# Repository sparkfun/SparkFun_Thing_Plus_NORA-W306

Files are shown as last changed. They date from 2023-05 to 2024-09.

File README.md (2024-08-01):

SparkFun Thing Plus - NORA-W306
========================================

SparkFun Thing Plus - NORA-W306 (https://www.sparkfun.com/products/21637)

[*SparkFun Thing Plus - NORA-W306 (WRL-21637)*](https://www.sparkfun.com/products/21637)

The SparkFun Thing Plus - NORA-W306 is a Feather form-factor development board equipped with the u-blox NORA-W306 module. The module contains a Realtek RTL8720DF, which has an integrated single-chip low-power dual-band (2.4GHz and 5GHz) Wireless LAN (WLAN) and Bluetooth&reg; Low Energy (BLE 5.3) communication microcontroller. It also consists of a dual processor core: Arm Cortex-M33 and Cortex-M23. To complement the module's low-power options, we've optimized components and added the ability to depower all subsystems to conserve as much power as possible for remote battery-powered applications.

Repository Contents
-------------------

* **.github/workflows** - YAML files used for GitHub Actions and GitHub Pages/mkdocs
* **/Hardware** - Eagle design files (.brd, .sch)
  * **/Production** - Production panel files (.brd)
* **/docs** - Online documentation files
  * **/assets** - Folder containing all the file assets used for product documentation
    * **/board_files** - Copy of design files used for product documentation
    * **/component_documentation** - Datasheets and manuals for hardware components
    * **/img** - Images for product documentation
  * **/github** - Files stating how to contribute and filing issues used for product documentation
  * **/javascript** - Folder containing custom javascript used for product documentation
  * **/stylesheet** - Folder containing CSS files used for product documentation
* **/overrides** - Customization files used for product documentation
  * **/.icons** - Icons used for GitHub used for product documentation
  * **./partials** - Used for product documentation

Documentation
--------------

* **[Installing an Arduino Library Guide](https://learn.sparkfun.com/tutorials/installing-an-arduino-library)** - Basic information on how to install an Arduino library.
* **Arduino Libraries**
    * **[MAX17048 LiPo Fuel Gauge](https://github.com/sparkfun/SparkFun_MAX1704x_Fuel_Gauge_Arduino_Library)**
    * **[SdFat](https://github.com/greiman/SdFat)**
    * **[Qwiic OLED Display](https://github.com/sparkfun/SparkFun_Qwiic_OLED_Arduino_Library)**
* **[Graphical Datasheet](https://github.com/sparkfun/Graphical_Datasheets/blob/main/Datasheets/NORA-W306/SparkFun_Thing_Plus_NORA-W306_u-blox.pdf)**
* **[Fritzing Part](https://github.com/sparkfun/Fritzing_Parts/blob/main/products/21637_sfe_thing_plus_u-blox_NORA-W306_development_board_lipo_charger_fuel_gauge_qwiic_WS2812.fzpz)**
* **[Realtek: Arduino Board Support Files](https://github.com/ambiot/ambd_arduino)**
* **[Hookup Guide](https://docs.sparkfun.com/SparkFun_Thing_Plus_NORA-W306)** - Basic hookup guide for the SparkFun Thing Plus NORA-W306.

Product Versions
----------------

* [WRL-21637](https://www.sparkfun.com/products/21637) - v1.0

Version History
---------------
* v1.0 - Initial Release

License Information
-------------------

This product is _**open source**_!

Please review the LICENSE.md file for license information.

If you have any questions or concerns on licensing, please contact technical support on our [SparkFun forums](https://forum.sparkfun.com/viewforum.php?f=152).

Distributed as-is; no warranty is given.

- Your friends at SparkFun.

_<COLLABORATION CREDIT>_

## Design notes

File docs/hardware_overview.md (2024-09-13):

In this section, we will highlight the hardware and pins that are broken out on the SparkFun Thing Plus NORA-W306. For more information, check out our [Resources and Going Further](../resources/) for the u-blox NORA-W306 module or Realtek RTL8720DF that is contained within the module.

<div style="text-align: center;">
  <table>
    <tr style="vertical-align:middle;">
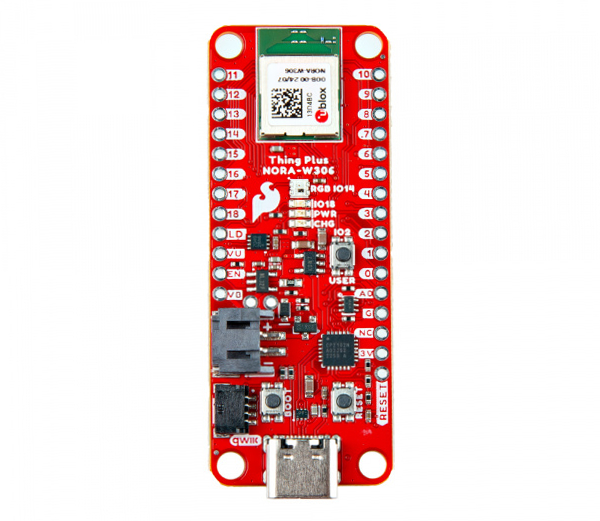
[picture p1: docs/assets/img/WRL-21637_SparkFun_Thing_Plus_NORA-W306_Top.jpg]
     <td style="text-align: center; vertical-align: middle; border: solid 1px #cccccc;"></td>
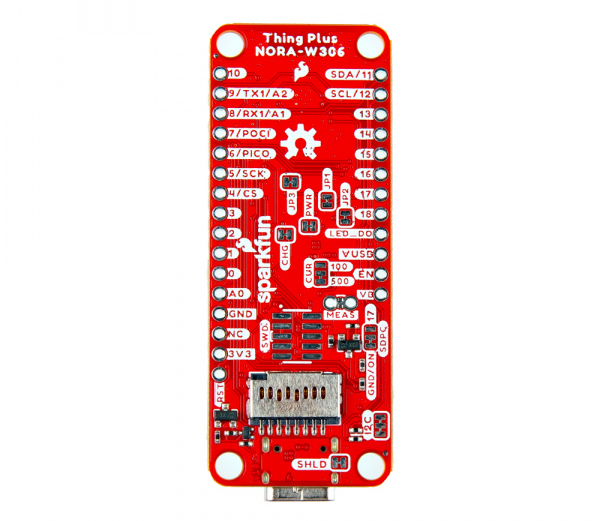
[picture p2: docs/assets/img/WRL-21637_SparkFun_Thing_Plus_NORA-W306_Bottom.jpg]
Bottom View
     <td style="text-align: center; vertical-align: middle; border: solid 1px #cccccc;"></td>
    </tr>
    <tr style="vertical-align:middle;">
     <td style="text-align: center; vertical-align: middle; border: solid 1px #cccccc;"><i>Top View</i></td>
     <td style="text-align: center; vertical-align: middle; border: solid 1px #cccccc;"><i>Bottom View</i></td>
    </tr>
  </table>
</div>

### Power

There are a variety of power and power-related nets broken out to connectors and through hole pads. Power is regulated down to 3.3V for the NORA-W306 so the [logic level](https://learn.sparkfun.com/tutorials/logic-levels/all) is 3.3V. There are Schottky diode and transistors to safely select voltage from the USB or LiPo battery. This avoids any conflicting voltages between the two sources.

* **VU** or **VUSB** &mdash; The _V_BUS_ net is connected to the USB Type C connector and the VU/VUSB PTH. You can use 5V from a USB port by connecting to the USB Type C connector or connecting power to the VBUS PTH. Make sure that power you provide to this pin does not exceed 6 volts. Power is regulated down with the XC6222 3.3V/700mA voltage regulator. The USB Type C connector is also used to upload code to your processor, send serial data to a terminal window, or charging the LiPo battery. Of course for portable power, you could connect a USB battery as an alternative to using a LiPo battery.
* **VB** &mdash;  The _V_BATT_ net is connected to the 2-pin JST style connector, VB PTH, and the NORA-W306's MEAS pin. For portable applications, you can connect a nominal 3.7V single cell, LiPo battery to the 2-pin JST style connector. This pin is also connected to the MCP73831 charge IC to safely charge the LiPo battery to its maximum voltage of about 4.2V. We recommend connecting only LiPo batteries to the VBAT net to power the board. Of course, you can power a separate device through the VBAT PTH pin. Power is regulated down with the XC6222 3.3V/700mA voltage regulator.
* **3V** or **3V3** &mdash; The 3.3V net is labeled as 3V or 3V3. You can apply power to the board if you have a regulated voltage of 3.3V. Otherwise, you could power a separate device through the 3V3 PTH pin. This is also connected to the Qwiic connector's 3.3V pin to power Qwiic enabled devices.
* **EN** &mdash; The 3.3V voltage regulator's EN pin is labeled as EN. Pulling this pin low will disable the 3.3V voltage regulator.
* **G** or **GND** &mdash; Of course, is the common, ground voltage (0V reference) for the system.

<div style="text-align: center;">
  <table>
    <tr style="vertical-align:middle;">
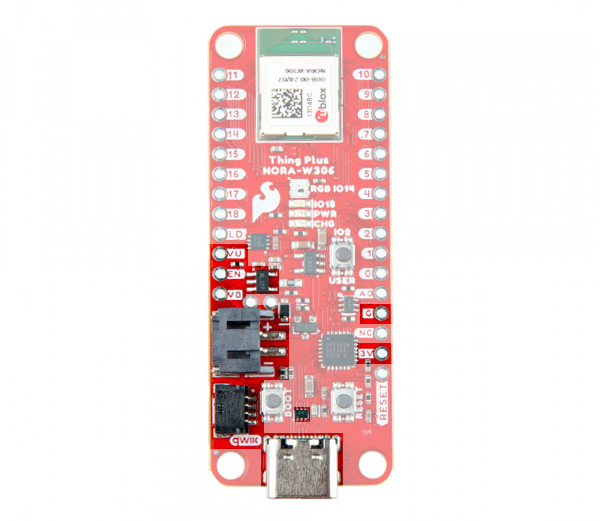
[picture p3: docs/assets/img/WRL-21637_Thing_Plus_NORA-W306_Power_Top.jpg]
     <td style="text-align: center; vertical-align: middle; border: solid 1px #cccccc;"></td>
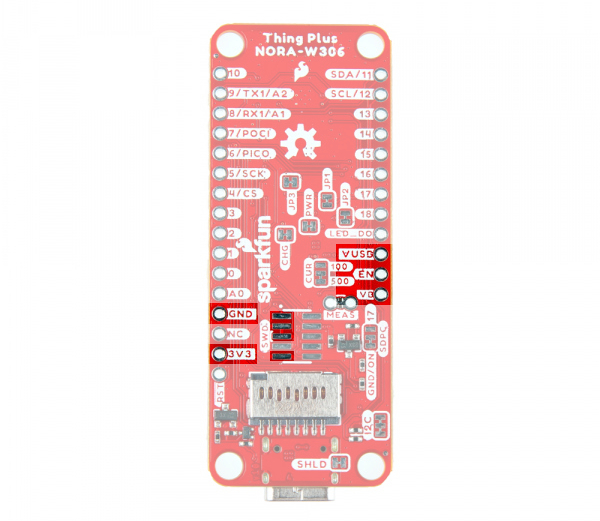
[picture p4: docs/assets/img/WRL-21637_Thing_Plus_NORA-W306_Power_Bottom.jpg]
Bottom View
     <td style="text-align: center; vertical-align: middle; border: solid 1px #cccccc;"></td>
    </tr>
    <tr style="vertical-align:middle;">
     <td style="text-align: center; vertical-align: middle; border: solid 1px #cccccc;" colspan="2"><i>Power, Ground, and Connectors Highlighted<br />(Top & Bottom View)</i></td>
    </tr>
  </table>
</div>

!!! note
    You will notice the pads of the SWD pins are also highlighted! 3.3V and ground are also connected to these pads. Users can easily access these pins using a SWD header and cable. Of course, you could also solder wire to those pads if you needed another way to connect to the traces.

!!! tip
    To complement the module's low-power options, we've optimized components and added the ability to depower all subsystems to conserve as much power as possible for remote battery-powered applications. Without a battery attached or charging, and cutting the power to WS2812 (i.e. jumper JP3); the current draw was as low as 14&micro;A in low power mode! Amazing! Under normal conditions, we measured the current draw as low as 30mA.

    Let's compare the Thing Plus ESP32 (USB-C) against the Thing Plus NORA-W306. The power LED jumper was cut on the Thing Plus ESP32. A microSD card was inserted in the microSD card socket (which does not have a way to turn off power through a GPIO) and the board was powered via a single cell LiPo battery. The current draw was 884&micro;A in deep sleep mode while it was 40mA when awake.

    For the Thing Plus NORA-W306, we cut the power LED and WS28112 LED jumpers. The SDPC (microSD Power Control) jumper was modified so power to the microSD card can be controlled through GPIO 17. A microSD card was inserted in the microSD card socket. With the MEAS jumper cut, a multimeter (set to measure current) was connected to monitor the current draw. Power was also provided via a single cell LiPo battery. The current draw was 115&micro;A in deep sleep mode while it was 21mA when awake.

    For more information, check out the demo video below with current draw for the board in low power mode!

    <div style="text-align: center;">
    <iframe width="560" height="315" src="https://www.youtube.com/embed/ElCYbEnyYH4?si=EVBnWnvqqZ6KBMxX" title="YouTube video player" frameborder="0" allow="accelerometer; autoplay; clipboard-write; encrypted-media; gyroscope; picture-in-picture; web-share" referrerpolicy="strict-origin-when-cross-origin" allowfullscreen></iframe>
    </div>

    <!--
    <div style="text-align: center;">
      <table>
        <tr style="vertical-align:middle;">
         <td style="text-align: center; vertical-align: middle; border: solid 1px #cccccc;">Component</td>
         <td style="text-align: center; vertical-align: middle; border: solid 1px #cccccc;">Power Usage Current [ &micro;A ]</td>
        </tr>
        <tr style="vertical-align:middle;">
         <td style="text-align: center; vertical-align: middle; border: solid 1px #cccccc;">CP2102</td>
         <td style="text-align: center; vertical-align: middle; border: solid 1px #cccccc;">199</td>
        </tr>
        <tr style="vertical-align:middle;">
         <td style="text-align: center; vertical-align: middle; border: solid 1px #cccccc;">microSD</td>
         <td style="text-align: center; vertical-align: middle; border: solid 1px #cccccc;">179</td>
        </tr>
        <tr style="vertical-align:middle;">
         <td style="text-align: center; vertical-align: middle; border: solid 1px #cccccc;">3.3V VREG<br />(Powered with 4V at VBATT)</td>
         <td style="text-align: center; vertical-align: middle; border: solid 1px #cccccc;">93</td>
        </tr>
        <tr style="vertical-align:middle;">
         <td style="text-align: center; vertical-align: middle; border: solid 1px #cccccc;">NORA-W306<br />(Powered with 3.3V at 3V3 net)</td>
         <td style="text-align: center; vertical-align: middle; border: solid 1px #cccccc;">10 to 11</td>
        </tr>
      </table>
    </div>
    -->

### LiPo Charge Circuit

The board includes the MCP73831 LiPo charger IC (the little black IC with 5 pins highlighted) to safely charge a single cell, LiPo battery. In this case, the charge rate is set to a default rate of **500mA**. Cutting the trace on the back while adding a solder jumper between the middle pad and the pad labeled as _100mA_ will set the charge rate to 100mA. The on-board LED (not highlighted) labeled as CHG can be used to get an indication of the **charge status** of your battery.

<div style="text-align: center;">
  <table>
    <tr style="vertical-align:middle;">
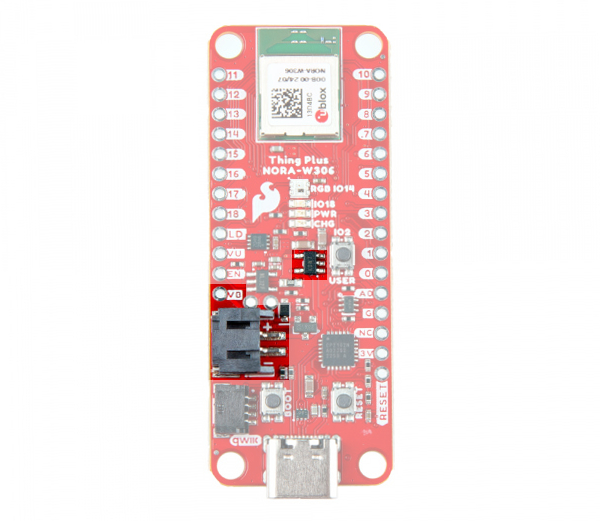
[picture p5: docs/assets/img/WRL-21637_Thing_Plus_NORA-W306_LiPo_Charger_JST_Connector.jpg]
Charge Circuit (Top View)
     <td style="text-align: center; vertical-align: middle; border: solid 1px #cccccc;"></td>
    </tr>
    <tr style="vertical-align:middle;">
     <td style="text-align: center; vertical-align: middle; border: solid 1px #cccccc;"><i>2-pin JST Style Connector, LiPo Charger IC, and VBATT PTH Highlighted<br />(Top View)</i></td>
    </tr>
  </table>
</div>

!!! note
    For more information on proper handling of LiPo batteries, check out the tutorial on [Single Cell LiPo Battery Care](https://learn.sparkfun.com/tutorials/single-cell-lipo-battery-care).

    <div class="grid cards" style="width:500px; margin: 0 auto;" markdown>

    -   <a href="https://learn.sparkfun.com/tutorials/single-cell-lipo-battery-care">
          <figure markdown>
            Single Cell LiPo Battery Care
          </figure>
        </a>

        ---

        <a href="https://learn.sparkfun.com/tutorials/single-cell-lipo-battery-care">
          <b>Single Cell LiPo Battery Care</b>
        </a>
    <!-- ----------WHITE SPACE BETWEEN GRID CARDS---------- -->
    </div>

### GPIO

The SparkFun Thing Plus - NORA-W306 breaks out the GPIO pins to plated through hole pads on the edge of the board using the Thing Plus/Feather Form Factor. Each of the pins on the edge of the board are tired to various components on the board. Check below for more information on each connection!

<div style="text-align: center;">
  <table>
    <tr style="vertical-align:middle;">
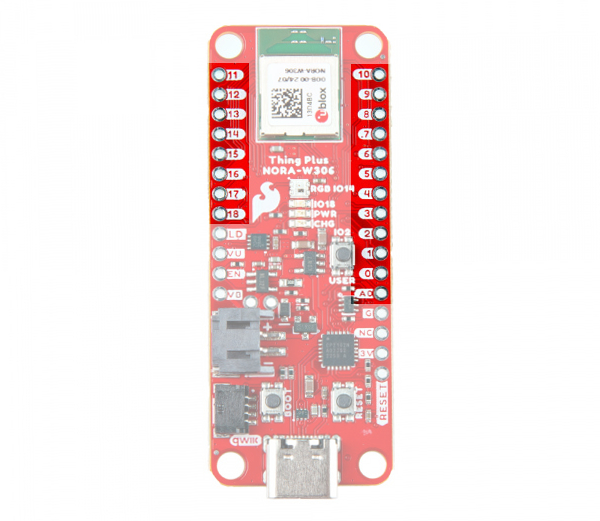
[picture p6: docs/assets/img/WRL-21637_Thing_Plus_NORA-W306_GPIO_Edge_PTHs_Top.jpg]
GPIO Pins Highlighted
     <td style="text-align: center; vertical-align: middle; border: solid 1px #cccccc;"></td>
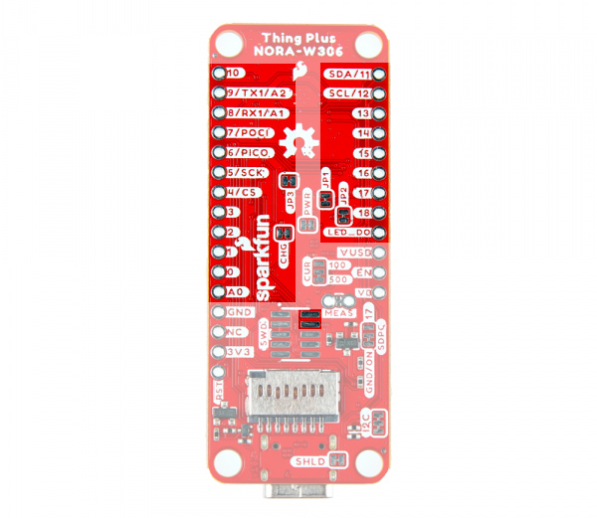
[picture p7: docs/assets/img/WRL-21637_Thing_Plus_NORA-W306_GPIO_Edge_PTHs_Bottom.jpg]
GPIO Pins Highlighted
     <td style="text-align: center; vertical-align: middle; border: solid 1px #cccccc;"></td>
    </tr>
    <tr style="vertical-align:middle;">
     <td style="text-align: center; vertical-align: middle; border: solid 1px #cccccc;" colspan="2"><i>GPIO Pins Highlighted<br />(Top & Bottom View)</i></td>
  </table>
</div>

Note that the pin label might have additional functionality that may not be apparent from the silkscreen. Below is a graphical datasheet of the SparkFun Thing Plus - NORA-W306 that highlights the additional functionality.

<div style="text-align: center;">
  <table>
    <tr style="vertical-align:middle;">
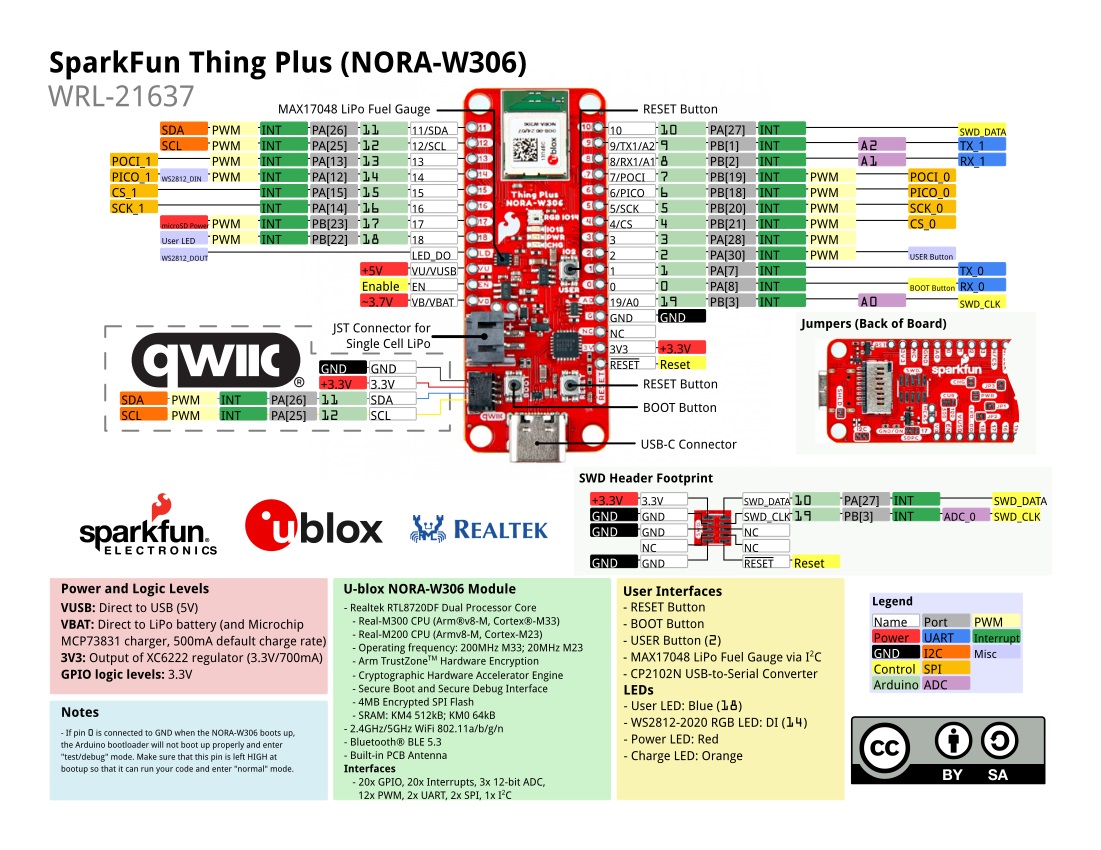
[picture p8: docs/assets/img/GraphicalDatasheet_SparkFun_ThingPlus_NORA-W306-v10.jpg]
Graphical Datasheet
     <td style="text-align: center; vertical-align: middle; border: solid 1px #cccccc;"></td>
    </tr>
    <tr style="vertical-align:middle;">
     <td style="text-align: center; vertical-align: middle; border: solid 1px #cccccc;"><i>Graphical Datasheet</i></td>
  </table>
</div>

!!! note
    While the u-blox integration manual may have pins highlighted to show additional functionality, there are some that are not supported in the Realtek's Arduino core. Some of these features that are not supported in the Arduino core include SDIO, I2S, IR, and RTC.

### SWD

For advanced users, the SWD pins are broken out on the 2x5 header on the back of the board. Note that this is not populated so you will need to solder a [compatible header, 2x5 SWD cable, and compatible JTAG programmer](https://www.sparkfun.com/categories/tags/jtag) to connect. These pins are also connected to the edge of the board.

<div style="text-align: center;">
  <table>
    <tr style="vertical-align:middle;">
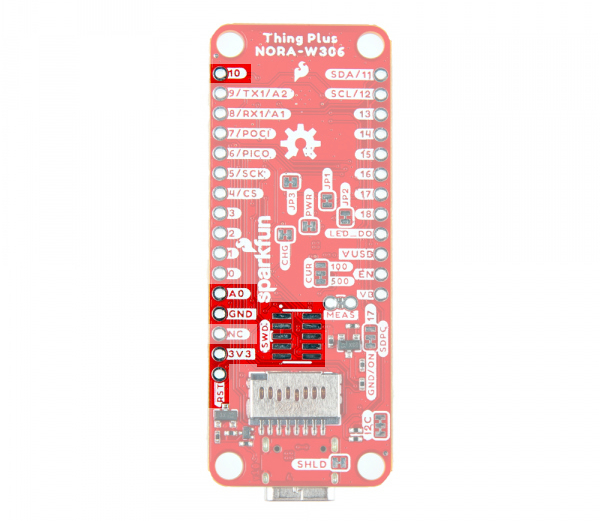
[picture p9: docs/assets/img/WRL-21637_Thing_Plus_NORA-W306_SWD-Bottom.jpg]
SWD Pins Highlighted
     <td style="text-align: center; vertical-align: middle; border: solid 1px #cccccc;"></td>
    </tr>
    <tr style="vertical-align:middle;">
     <td style="text-align: center; vertical-align: middle; border: solid 1px #cccccc;"><i>SWD Pins Highlighted</i></td>
  </table>
</div>

!!! note
    Pin `10` is tied to the SWD Data pad and `A0` is tied to SWD CLK pad on the back of the board.

### Reset and Boot Buttons

Each board includes a RESET and BOOT button. There is an additional reset PTH next to the reset button. Hit the reset button to restart the NORA-W306. To manually place the NORA-W306 into boot mode, hold down the BOOT button while pressing the RESET button momentarily and then release the BOOT button.

<div style="text-align: center;">
  <table>
    <tr style="vertical-align:middle;">
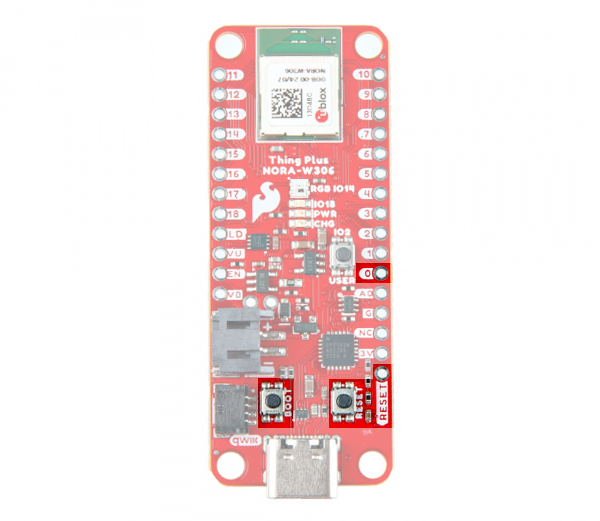
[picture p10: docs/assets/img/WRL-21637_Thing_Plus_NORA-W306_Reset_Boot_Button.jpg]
     <td style="text-align: center; vertical-align: middle; border: solid 1px #cccccc;"></td>
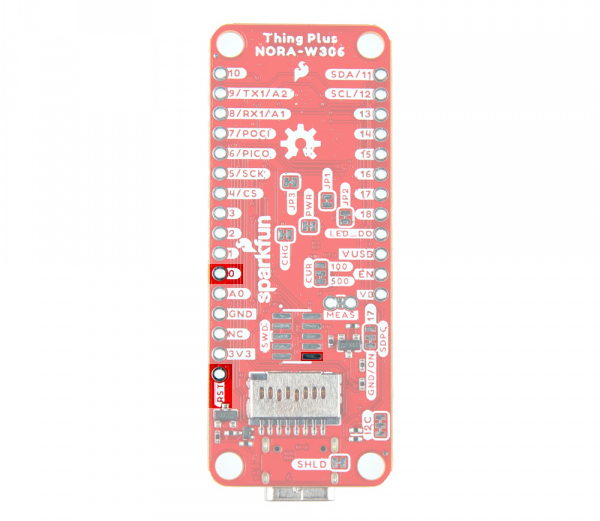
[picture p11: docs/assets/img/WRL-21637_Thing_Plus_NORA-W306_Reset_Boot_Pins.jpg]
     <td style="text-align: center; vertical-align: middle; border: solid 1px #cccccc;"></td>
    </tr>
    <tr style="vertical-align:middle;">
     <td style="text-align: center; vertical-align: middle; border: solid 1px #cccccc;" colspan="2"><i>Reset and Boot Pins and Buttons Highlighted<br />(Top & Bottom View)</i></td>
    </tr>
  </table>
</div>

!!! note
    The BOOT button is also connected to pin 0 (TX). The datasheet refers to this pin as the CHIP_EN.

!!! note
    You will notice a pad of the SWD is also highlighted. The reset pin is connected to this pad. Users can easily access these pins using a SWD header and cable. Of course, you could also solder wire to those pads if you needed another way to connect to the traces.

### User Button

The board also includes a user button that is connected pin `2`.

<div style="text-align: center;">
  <table>
    <tr style="vertical-align:middle;">
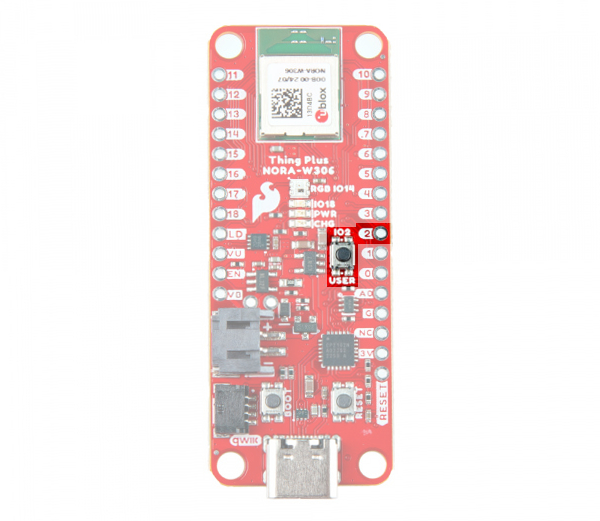
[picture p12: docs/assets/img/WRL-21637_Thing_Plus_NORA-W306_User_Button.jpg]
     <td style="text-align: center; vertical-align: middle; border: solid 1px #cccccc;"></td>
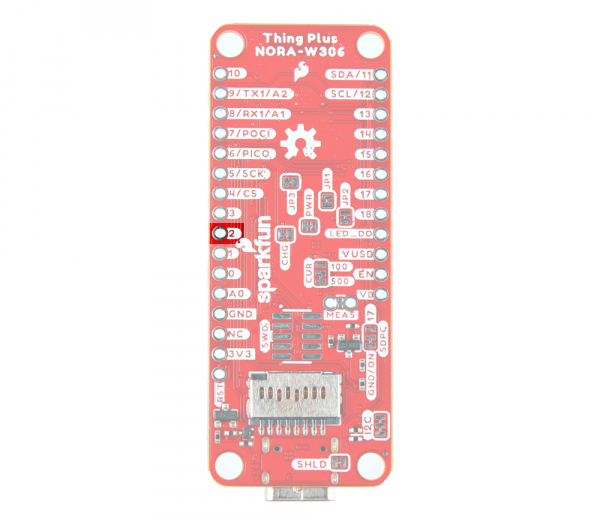
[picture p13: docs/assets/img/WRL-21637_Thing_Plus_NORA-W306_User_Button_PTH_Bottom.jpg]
Bottom View
     <td style="text-align: center; vertical-align: middle; border: solid 1px #cccccc;"></td>
    </tr>
    <tr style="vertical-align:middle;">
     <td style="text-align: center; vertical-align: middle; border: solid 1px #cccccc;" colspan="2"><i>Reset & Boot Pins and Buttons Highlighted<br />(Top & Bottom View)</i></td>
    </tr>
  </table>
</div>

!!! note
    When defining the pin for the user button, make sure to use an [internal pull-up resistor](https://docs.arduino.cc/tutorials/generic/digital-input-pullup) so that the button is not floating.

!!! tip
    Need a bigger button? Users can connect pin 2 on the edge of the board to an external button!

### Interrupts

Speaking of buttons, all GPIOs can also be set as [interrupts](https://learn.sparkfun.com/tutorials/processor-interrupts-with-arduino/all)!

<div style="text-align: center;">
  <table>
    <tr style="vertical-align:middle;">
     <td style="text-align: center; vertical-align: middle; border: solid 1px #cccccc;"><a href="../assets/img/WRL-21637_Thing_Plus_NORA-W306_GPIO_Edge_PTHs_Top.jpg">GPIO Pins Highlighted</a></td>
     <td style="text-align: center; vertical-align: middle; border: solid 1px #cccccc;"><a href="../assets/img/WRL-21637_Thing_Plus_NORA-W306_GPIO_Edge_PTHs_Bottom.jpg">GPIO Pins Highlighted</a></td>
    </tr>
    <tr style="vertical-align:middle;">
     <td style="text-align: center; vertical-align: middle; border: solid 1px #cccccc;" colspan="2"><i>Interrupt Pins Highlighted<br />(Top & Bottom View)</i></td>
  </table>
</div>

### UART

There are two [UARTs](https://learn.sparkfun.com/tutorials/serial-communication). The primary hardware UART (UART0) is connected to the USB-to-serial converter. The secondary hardware UART (UART1) is broken out to the edge of the board. We recommend connecting a UART device to the secondary hardware UART to avoid any bus contention with the CP2102N.

<div style="text-align: center;">
  <table>
    <tr style="vertical-align:middle;">
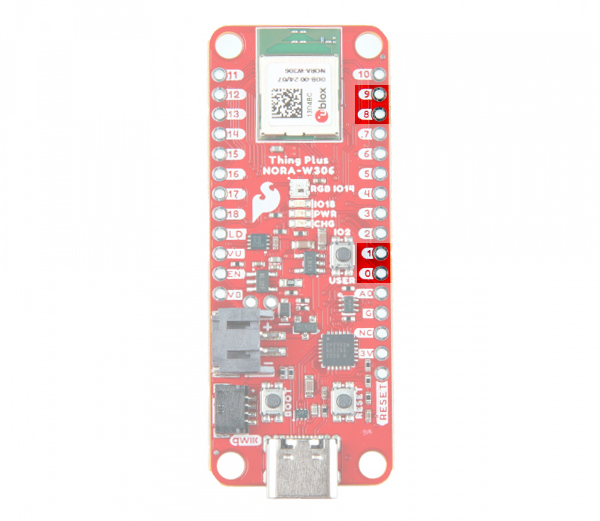
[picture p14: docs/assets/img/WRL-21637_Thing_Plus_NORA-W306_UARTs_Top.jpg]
UARTs Highlighted
     <td style="text-align: center; vertical-align: middle; border: solid 1px #cccccc;"></td>
     <td style="text-align: center; vertical-align: middle; border: solid 1px #cccccc;"><a href="../assets/img/WRL-
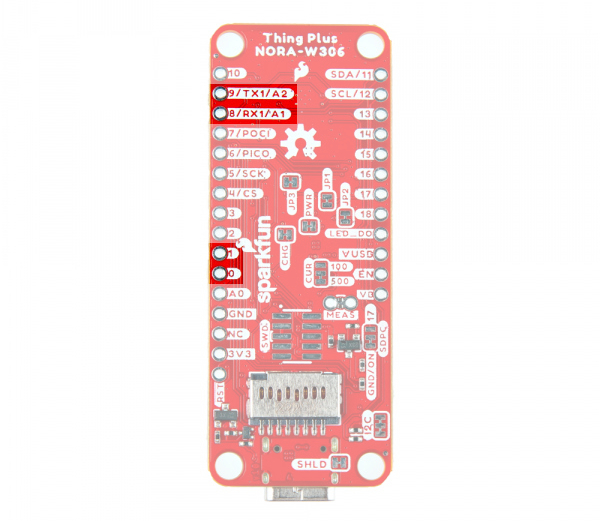
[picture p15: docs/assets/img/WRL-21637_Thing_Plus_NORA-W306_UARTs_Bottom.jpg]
UARTs Highlighted
    WRL-21637_Thing_Plus_NORA-W306_UARTs_Bottom.jpg"></a></td>
    </tr>
    <tr style="vertical-align:middle;">
     <td style="text-align: center; vertical-align: middle; border: solid 1px #cccccc;" colspan="2"><i>UARTs Highlighted<br />(Top & Bottom View)</i></td>
  </table>
</div>

#### CP2102N USB-to-Serial Converter

The board includes the CP2102N USB-to-Serial converter. This is used for serial programming or communicating with a serial terminal. The CP2102N is connected to the NORA-W306&apos;s primary hardware UART (UART0): TX pin is connected to pin `0` (RX0) while and RX pin is connected to pin `1` (TX0).

<div style="text-align: center;">
  <table>
    <tr style="vertical-align:middle;">
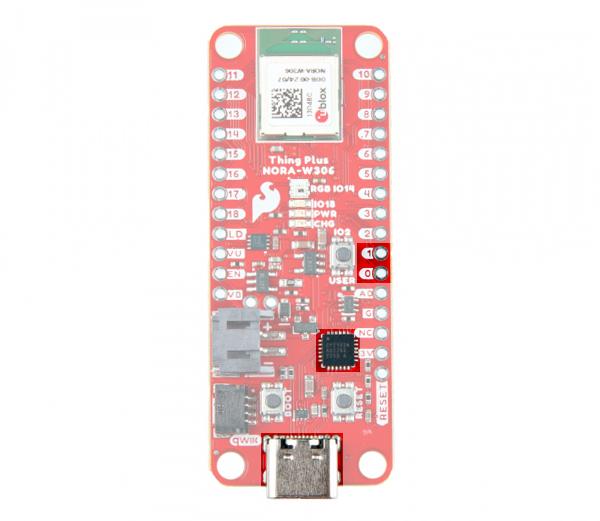
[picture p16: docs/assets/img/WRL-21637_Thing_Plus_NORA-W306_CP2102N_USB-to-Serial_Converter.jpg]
USB-to-Serial Converter, USB, and UART0 Highlighted
     <td style="text-align: center; vertical-align: middle; border: solid 1px #cccccc;"></td>
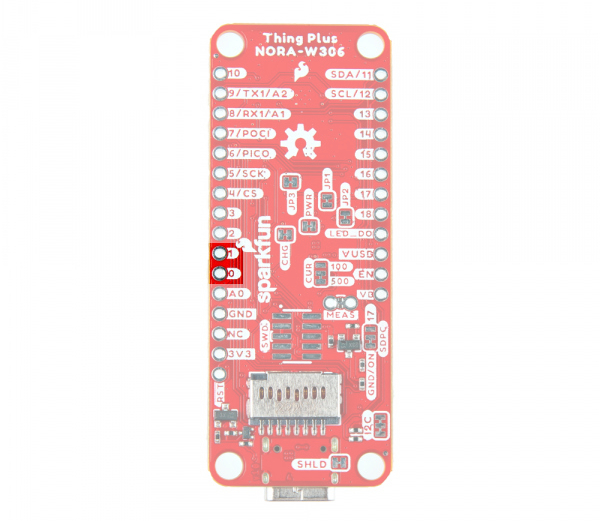
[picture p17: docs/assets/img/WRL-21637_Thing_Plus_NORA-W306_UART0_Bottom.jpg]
UART0 Highlighted
     <td style="text-align: center; vertical-align: middle; border: solid 1px #cccccc;"></td>
    </tr>
    <tr style="vertical-align:middle;">
     <td style="text-align: center; vertical-align: middle; border: solid 1px #cccccc;" colspan="2"><i>USB-to-Serial Converter, USB, and UART0 Highlighted<br />(Top & Bottom View)</i></td>
  </table>
</div>

### Qwiic and I<sup>2</sup>C

The board includes one horizontal Qwiic connector on the board. These pins are connected to the primary <a href="https://learn.sparkfun.com/tutorials/i2c/all">I<sup>2</sup>C</a> bus and power (e.g. 3.3V and GND) allowing you to easily add a Qwiic-enabled device to your application. The I<sup>2</sup>C data and clock lines are also tied to 2.2k&ohm; pull-up resistors. The I<sup>2</sup>C SCL pin is connected to `12`. The I<sup>2</sup>C SDA is connected to `11`.

<div style="text-align: center;">
  <table>
    <tr style="vertical-align:middle;">
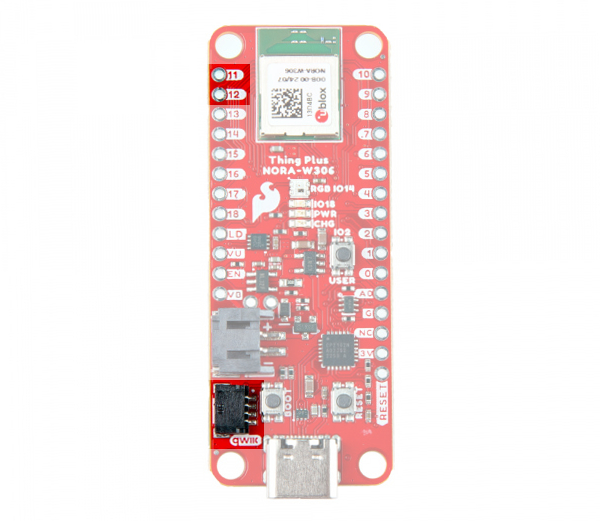
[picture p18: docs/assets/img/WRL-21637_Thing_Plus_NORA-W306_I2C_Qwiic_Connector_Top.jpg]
I2C Pins and Qwiic Connector Highlighted
     <td style="text-align: center; vertical-align: middle; border: solid 1px #cccccc;"></td>
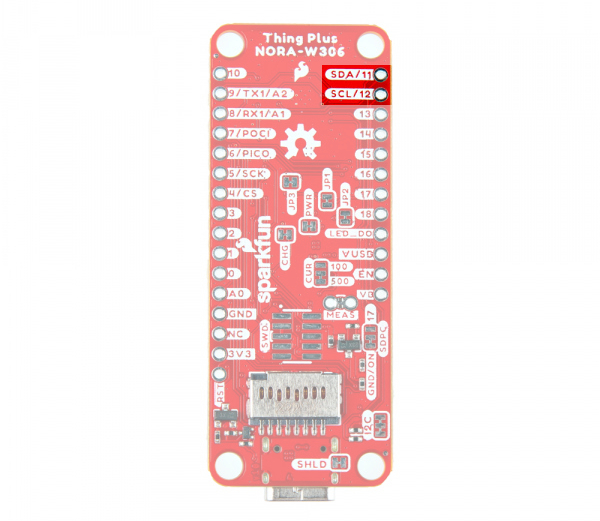
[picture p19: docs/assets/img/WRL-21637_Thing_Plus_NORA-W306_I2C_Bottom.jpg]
I2C Pins Highlighted
     <td style="text-align: center; vertical-align: middle; border: solid 1px #cccccc;"></td>
    </tr>
    <tr style="vertical-align:middle;">
     <td style="text-align: center; vertical-align: middle; border: solid 1px #cccccc;" colspan="2"><i>I<sup>2</sup>C and Qwiic Connector Highlighted<br />(Top & Bottom View)</i></td>
  </table>
</div>

#### LiPo Fuel Gauge - MAX17048

Built into the board is also the single cell LiPo Fuel Gauge, specifically the [MAX17408](https://learn.sparkfun.com/tutorials/lipo-fuel-gauge-max1704x-hookup-guide/all). The 7-bit, unshifted address of the MAX17048 is **0x36**. The address becomes _0x6C_ for write and _0x6D_ for read.  

<div style="text-align: center;">
  <table>
    <tr style="vertical-align:middle;">
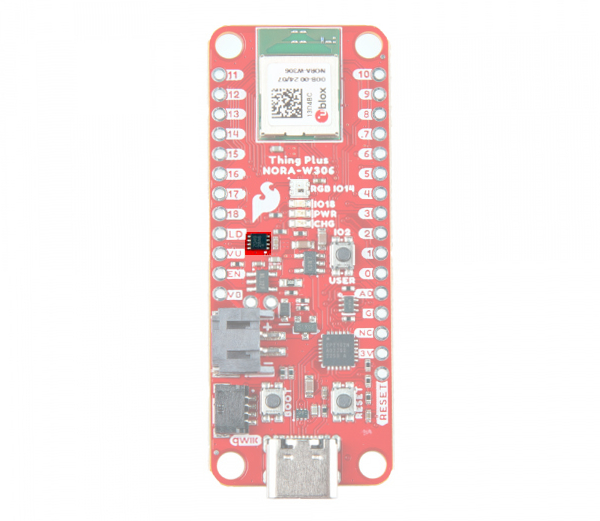
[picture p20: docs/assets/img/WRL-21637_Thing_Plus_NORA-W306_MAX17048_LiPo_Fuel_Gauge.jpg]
LiPo Fuel Gauge - MAX17048 Highlighted
     <td style="text-align: center; vertical-align: middle; border: solid 1px #cccccc;"></td>
    </tr>
    <tr style="vertical-align:middle;">
     <td style="text-align: center; vertical-align: middle; border: solid 1px #cccccc;"><i>LiPo Fuel Gauge - MAX17048 Highlighted<br />(Top View)</i></td>
  </table>
</div>

### SPI

There are two [SPI](https://learn.sparkfun.com/tutorials/serial-peripheral-interface-spi/all) ports available. The primary SPI pins (SPI0) is broken out as:  `5` (SPI0_SCK), `6` (SPI0_PICO), `7` (SPI0_POCI), and `4` (SPI0_CS). These are also connected to the microSD card that is populated on the back. The secondary SPI pins (SPI1) is broken out as: `16` (SPI1_SCK), `14` (SPI1_PICO), `13` (SPI1_POCI), and `15` (SPI1_CS)

<div style="text-align: center;">
  <table>
    <tr style="vertical-align:middle;">
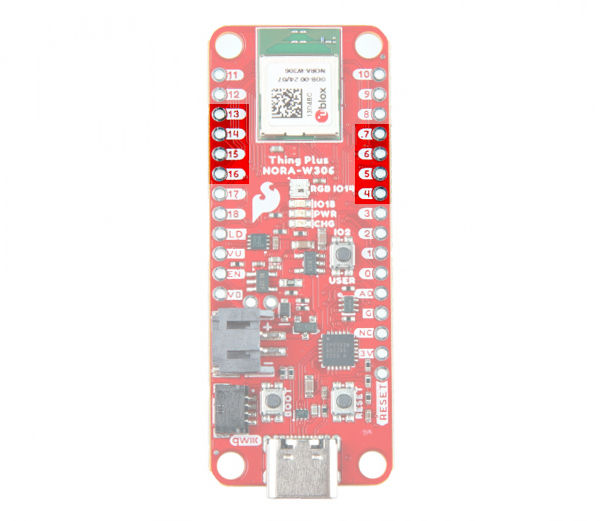
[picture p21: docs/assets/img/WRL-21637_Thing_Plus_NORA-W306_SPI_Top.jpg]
SPI Pins Highlighted - Top
     <td style="text-align: center; vertical-align: middle; border: solid 1px #cccccc;"></td>
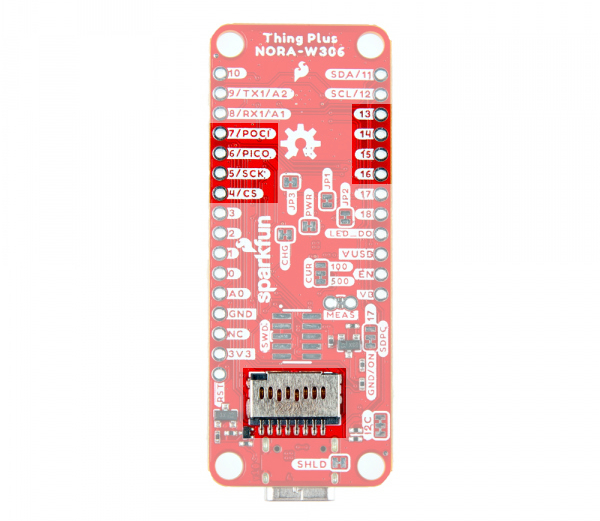
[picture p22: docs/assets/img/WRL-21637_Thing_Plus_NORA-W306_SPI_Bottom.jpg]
SPI Pins Highlighted - Bottom
     <td style="text-align: center; vertical-align: middle; border: solid 1px #cccccc;"></td>
    </tr>
    <tr style="vertical-align:middle;">
     <td style="text-align: center; vertical-align: middle; border: solid 1px #cccccc;" colspan="2"><i>SPI Pins Highlighted<br />(Top & Bottom View)</i></td>
  </table>
</div>

!!! note
    Pin `14` is also connected to the addressable LED. The Realtek Arduino Core needed to use this specific SPI pin to control WS2812. Users can disable the addressable LED by cutting JP1 on the back of the board.

#### MicroSD Card Socket

Built into the board is a microSD card socket to log data. As explained in the SPI section, the data lines are connected to the primary SPI pins (SPI0). One special feature that is different from other Thing Plus boards is the transistor to toggle power to the microSD card socket. By default, it is always on. For users that want to conserve power, you can cut the jumper for the **SDPC**. You will then need to add a solder blob between the center pad and the pad that is labeled **17**.

<div style="text-align: center;">
  <table>
    <tr style="vertical-align:middle;">
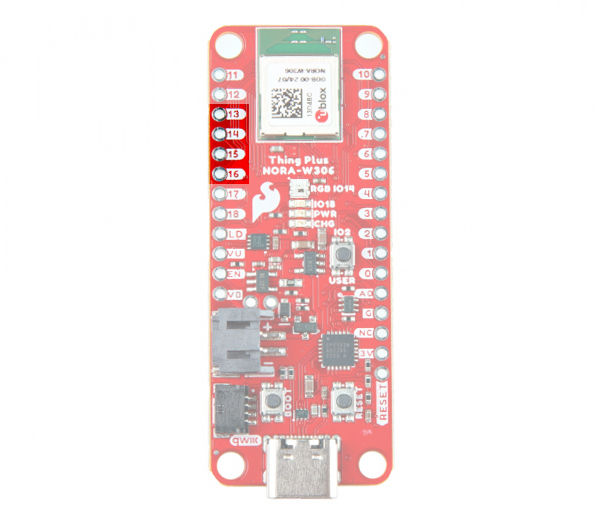
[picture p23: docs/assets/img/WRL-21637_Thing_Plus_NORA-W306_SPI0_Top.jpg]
SPI Pins Highlighted on the top
     <td style="text-align: center; vertical-align: middle; border: solid 1px #cccccc;"></td>
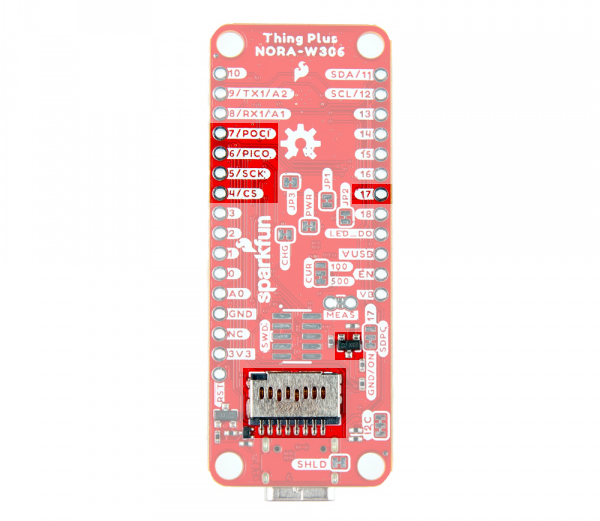
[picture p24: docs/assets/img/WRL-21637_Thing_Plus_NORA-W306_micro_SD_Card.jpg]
SPI Pins Highlighted on the Bottom
     <td style="text-align: center; vertical-align: middle; border: solid 1px #cccccc;"></td>
    </tr>
    <tr style="vertical-align:middle;">
     <td style="text-align: center; vertical-align: middle; border: solid 1px #cccccc;" colspan="2"><i>Micro SD Card, Transistor, and Power Enable Pin Highlighted<br />(Top & Bottom View)</i></td>
  </table>
</div>

### Pulse Width Modulation (PWM)

There are 12x [PWM](https://learn.sparkfun.com/tutorials/pulse-width-modulation/all) pins available: `2`, `3`, `4`, `5`, `6`, `7`, `11`, `12`, `13`, `14`, `17`, and `18`. Note that these are tied to other peripherals as well.

<div style="text-align: center;">
  <table>
    <tr style="vertical-align:middle;">
     <td style="text-align: center; vertical-align: middle; border: solid 1px #cccccc;"><a href="../assets/img/WRL-WRL-21637_Thing_Plus_NORA-W306_PWM_Pins_Top.jpg">PWM Pins Highlighted</a></td>
     <td style="text-align: center; vertical-align: middle; border: solid 1px #cccccc;"><a href="../assets/img/WRL-21637_Thing_Plus_NORA-W306_PWM_Pins_Bottom.jpg">PWM Pins Highlighted</a></td>
    </tr>
    <tr style="vertical-align:middle;">
     <td style="text-align: center; vertical-align: middle; border: solid 1px #cccccc;" colspan="2"><i>PWM Pins Highlighted<br />(Top & Bottom View)</i></td>
  </table>
</div>

### Analog

There are 3x 12-bit [analog](https://learn.sparkfun.com/tutorials/analog-to-digital-conversion/all#what-is-the-adc) pins available: `A0`, `A1`, and `A2`.

<div style="text-align: center;">
  <table>
    <tr style="vertical-align:middle;">
     <td style="text-align: center; vertical-align: middle; border: solid 1px #cccccc;"><a href="../assets/img/WRL-WRL-21637_Thing_Plus_NORA-W306_ADC_Pins_Analog_Top.jpg">ADC Pins Highlighted</a></td>
     <td style="text-align: center; vertical-align: middle; border: solid 1px #cccccc;"><a href="../assets/img/WRL-
     WRL-21637_Thing_Plus_NORA-W306_ADC_Pins_Analog_Bottom.jpg">ADC Pins Highlighted</a></td>
    </tr>
    <tr style="vertical-align:middle;">
     <td style="text-align: center; vertical-align: middle; border: solid 1px #cccccc;" colspan="2"><i>ADC Pins Highlighted<br />(Top & Bottom View)</i></td>
  </table>
</div>

### LEDs

There are 4x LEDs populated on the board.

* **PWR** &mdash; The **PWR** LED lights up to indicate when there is a 3.3V available after power is regulated down from the USB connector or LiPo battery. This can be disabled by cutting the jumper labeled as **PWR**.
* **CHG** &mdash; The on-board yellow **CHG** LED can be used to get an indication of the **charge status** of your battery. Below is a table of other status indicators depending on the state of the charge IC. This can be disabled by cutting the jumper labeled as **CHG**.
* **RGB IO14** &mdash; The **RGB IO14** LED is an WS2812-2020 LED. Users can control this addressable RGB LED using pin `14`. This LED can be disconnected from the pin by cutting the jumper labeled as **JP1**. For users that are not using this LED and want to conserve power, the 3.3V net can also be disconnected as well by cutting the jumper labeled as **JP3**. For users that are interested in daisy chaining additional WS2812 LEDs, users can connect to the PTH labled as **LD** or **LED D0**.
* **IO18** &mdash; The LED labeled as **IO18** can be configured by the user and is connected to pin `18`. This can be disconnect from the pin by cutting the jumper labeled **JP2**.

<div style="text-align: center;">
  <table>
    <tr style="vertical-align:middle;">
      <td style="text-align: center; vertical-align: middle;"><b>Charge State</b></td>
      <td style="text-align: center; vertical-align: middle;"><b>LED status</b></td>
    </tr>
    <tr align="center">
      <td style="text-align: center; vertical-align: middle;">No Battery</td>
      <td style="text-align: center; vertical-align: middle;">Floating (should be OFF, but may flicker)</td>
    </tr>
    <tr align="center">
      <td style="text-align: center; vertical-align: middle;">Shutdown</td>
      <td style="text-align: center; vertical-align: middle;">Floating (should be OFF, but may flicker)</td>
    </tr>
    <tr align="center">
      <td style="text-align: center; vertical-align: middle;">Charging</td>
      <td style="text-align: center; vertical-align: middle;">ON</td>
    </tr>
    <tr align="center">
      <td style="text-align: center; vertical-align: middle;">Charge Complete</td>
      <td style="text-align: center; vertical-align: middle;">OFF</td>
    </tr>
  </table>
</div>

<div style="text-align: center;">
  <table>
    <tr style="vertical-align:middle;">
     <td style="text-align: center; vertical-align: middle; border: solid 1px #cccccc;"><a href="../assets/img/WRL-21637_Thing_Plus_NORA-W306_LEDs_Top.jpg">LEDs and PTHs Highlighted - Top</a></td>
     <td style="text-align: center; vertical-align: middle; border: solid 1px #cccccc;"><a href="../assets/img/WRL-21637_Thing_Plus_NORA-W306_LED_PTH_Bottom.jpg">PTHs connected to LEDs Highlighted - Bottom</a></td>
    </tr>
    <tr style="vertical-align:middle;">
     <td style="text-align: center; vertical-align: middle; border: solid 1px #cccccc;" colspan="2"><i>LEDs and Connected PTHs Highlighted<br />(Top & Bottom View)</i></td>
  </table>
</div>

### Jumpers

!!!note
    If this is your first time working with jumpers, check out the [How to Work with Jumper Pads and PCB Traces](https://learn.sparkfun.com/tutorials/how-to-work-with-jumper-pads-and-pcb-traces/all) tutorial for more information.

There are a few jumper pads available on the bottom of the board.

* **SHLD** &mdash; This jumper connects the USB Type C connector's shield pin to GND. Cut this to isolate the USB Type C connector's shield pin. This is for advanced users that want to ground their board to their enclosure instead of the ground plane.
* **MEAS** &mdash; To enable measurements and determine how long your battery might last, we've added a NC (normally closed) jumper between the two MEAS PTH pins. By cutting this jumper, the voltage connecting to the 3.3V voltage regulator input is interrupted. Soldering in a male jumper or wires into the accompanying holes will give you the ability to insert a current meter and precisely monitor how much current your application is consuming.
* **PWR** &mdash; By default, this jumper is closed. Cut this trace to disable the power LED that is connected to 3.3V.
* **CHG** &mdash; By default, this jumper is closed. Cut this trace to disable the charge LED that is connected to the LiPo charge IC.
* **LED_D0** &mdash; By default, this jumper is closed. Cut this trace to disable the WS2812 addressable RGB LED's output pin labeled as `D0`.
* **JP1** &mdash; By default, this jumper is closed. Cut this trace to disable the WS2812 addressable RGB LED's input pin that is connected to pin `14`.
* **JP2** &mdash; By default, this jumper is closed. Cut this trace to disable the user LED that is connected to pin `18`.
* **JP3** &mdash; By default, this jumper is closed. Cut this trace to disable power connected to the WS2812 addressable LED's 3.3V pin.
* **CUR** &mdash; This three way jumper sets the charge IC's charge rate. By default, it's connected to the pad labeled **500** so the charge rate is set to 500mA. Cutting a trace and adding a solder jumper between the center pad and the pad labeled as **100** will set the charge rate to 100mA.
* **I2C** &mdash; By default, this three-pad jumper is closed and located on the bottom of the board. The three way jumper labeled I2C connect the two 2.2k&ohm; pull-up resistors to the I<sup>2</sup>C data and clock lines. If multiple devices are connected to the bus with the pull-up resistors enabled, the parallel equivalent resistance will create too strong of a pull-up for the bus to operate correctly. As a general rule of thumb, [disable all but one pair of pull-up resistors](https://learn.sparkfun.com/tutorials/i2c/all#i2c-at-the-hardware-level) if multiple devices are connected to the bus.
* **SDPC** &mdash; By default, this jumper is closed and for the microSD card's power control circuit. Cut this trace on the **GND/ON** side to disable power to the microSD card's socket. For users that want to control the transistor via a GPIO, add a solder blob between the center pad and the pad that is labeled **17**. Make sure to also define the pin in code to toggle power to the microSD card.

<div style="text-align: center;">
  <table>
    <tr style="vertical-align:middle;">
     <td style="text-align: center; vertical-align: middle; border: solid 1px #cccccc;"><a href="../assets/img/WRL-21637_Thing_Plus_NORA-W306_MEAS_PTH_Top.jpg">MEAS PTH Highlighted - Top</a></td>
     <td style="text-align: center; vertical-align: middle; border: solid 1px #cccccc;"><a href="../assets/img/WRL-21637_Thing_Plus_NORA-W306_Jumpers_Bottom.jpg">Jumpers Highlighted - Bottom</a></td>
    </tr>
    <tr style="vertical-align:middle;">
     <td style="text-align: center; vertical-align: middle; border: solid 1px #cccccc;" colspan="2"><i>Jumpers Highlighted<br />(Top & Bottom View)</i></td>
  </table>
</div>

### Board Dimensions

The board is 0.9" x 2.3" (22.86mm x 58.42mm) and uses the [standard Thing+](https://www.sparkfun.com/thing_plus) footprint. There are 4x mounting holes by each corner of the board. You can use 4-40 standoffs to mount the board to a panel or enclosure.

<div style="text-align: center;">
  <table>
    <tr style="vertical-align:middle;">
     <td style="text-align: center; vertical-align: middle; border: solid 1px #cccccc;"><a href="../assets/img/SparkFun_Thing_Plus_NORA-W306_Board_Dimensions.png">Board Dimensions</a></td>
    </tr>
    <tr style="vertical-align:middle;">
     <td style="text-align: center; vertical-align: middle; border: solid 1px #cccccc;"><i>Board Dimensions</i></td>
    </tr>
  </table>
</div>

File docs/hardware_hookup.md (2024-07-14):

At a minimum, you will need to plug in the USB C cable to the SparkFun Thing Plus NORA-W306 to power and program the board.

<div style="text-align: center;">
  <table>
    <tr style="vertical-align:middle;">
     <td style="text-align: center; vertical-align: middle; border: solid 1px #cccccc;"><a href="../assets/img/WRL-21637_Thing_Plus_NORA-W306_USB_Cable.jpg">USB Cable inserted into Thing Plus NORA-W306</a></td>
    </tr>
    <tr style="vertical-align:middle;">
     <td style="text-align: center; vertical-align: middle; border: solid 1px #cccccc;"><i>USB Cable inserted into Thing Plus NORA-W306</i></td>
    </tr>
  </table>
</div>

### Single Cell LiPo Battery

!!! warning "Battery Polarity"
    Please make sure that you use one of our recommended Lithium Ion batteries. Some batteries use the same JST connector as ours but have the opposite polarity. Connecting one of these to your SparkFun Thing Plus NORA-W306 will destroy it. If you are going to use your own battery, it is up to you to ensure it has the correct polarity.

For remote applications, you can connect a standard single cell LiPo battery. The SparkFun Thing Plus NORA-W306 has a built-in charger too which will charge your battery at **500mA** when a USB-C is connected. Please make sure your battery capacity is at least 500mAh (0.5Ah); bad things will happen if you try to charge smaller batteries using the board's default charge rate of 500mA. Of course, you can adjust the charge rate with the 3-way jumper on the back of the board. The yellow CHG charging LED will light up while the battery is charging and will turn off once charging is complete.

<div style="text-align: center;">
  <table>
    <tr style="vertical-align:middle;">
     <td style="text-align: center; vertical-align: middle; border: solid 1px #cccccc;"><a href="../assets/img/WRL-21637_Thing_Plus_NORA-W306_LiPo_Battery.jpg">Battery Connected</a></td>
    </tr>
    <tr style="vertical-align:middle;">
     <td style="text-align: center; vertical-align: middle; border: solid 1px #cccccc;"><i>Battery Connected</i></td>
    </tr>
  </table>
</div>

The MCP73831 charge IC on the board is used on a few SparkFun products. For more information about the CHG status LED, we recommend taking look at the Hardware Overview. We also recommend taking a look at this tutorial for [Single Cell LiPo Battery Care](https://learn.sparkfun.com/tutorials/single-cell-lipo-battery-care).

<div class="grid cards" style="width:500px; margin: 0 auto;" markdown>
<!-- ----------WHITE SPACE BETWEEN GRID CARDS---------- -->
-   <a href="https://learn.sparkfun.com/tutorials/single-cell-lipo-battery-care">
      <figure markdown>
        Single Cell LiPo Battery Care
      </figure>
    </a>

    ---

    <a href="https://learn.sparkfun.com/tutorials/single-cell-lipo-battery-care">
      <b>Single Cell LiPo Battery Care</b>
    </a>
<!-- ----------WHITE SPACE BETWEEN GRID CARDS---------- -->
</div>

### Inserting a MicroSD Card

For those that need to store data, you can add a microSD card to your application. You will just need to insert a microSD card with the metal contacts facing the board and into the socket on the back. Compared to other microSD cards sockets in sparkFun's storefront, this will not have a click to lock the memory card in place. Just make sure to fully insert the memory card.

<div style="text-align: center;">
  <table>
    <tr style="vertical-align:middle;">
     <td style="text-align: center; vertical-align: middle; border: solid 1px #cccccc;"><a href="../assets/img/WRL-21637_Thing_Plus_NORA-W306_microSD_Card.jpg">MicroSD Card in Socket</a></td>
    </tr>
    <tr style="vertical-align:middle;">
     <td style="text-align: center; vertical-align: middle; border: solid 1px #cccccc;"><i>MicroSD Card in Socket</i></td>
    </tr>
  </table>
</div>

You should only insert or remove the SD card while the power is turned off or disconnected. Removing the card while the SparkFun Thing Plus NORA-W306 is powered will almost certainly corrupt your data.

### Connecting via Qwiic

For users that want to connect a Qwiic-enabled device, you will simply need to insert a cable between the Qwiic connectors. Then insert a USB cable between the microcontroller and your computer to power and program.

<div style="text-align: center;">
  <table>
    <tr style="vertical-align:middle;">
     <td style="text-align: center; vertical-align: middle; border: solid 1px #cccccc;"><a href="../assets/img/WRL-21637_Thing_Plus_NORA-W306_Qwiic_Enabled_Device_OLED.jpg">Qwiic-enabled Device Connected to Thing Plus NORA-w306</a></td>
    </tr>
    <tr style="vertical-align:middle;">
     <td style="text-align: center; vertical-align: middle; border: solid 1px #cccccc;"><i>Qwiic-enabled Device Connected to Thing Plus NORA-W306</i></td>
    </tr>
  </table>
</div>

### Connecting via PTH

For temporary connections to the PTHs, you could use IC hooks to test out the pins. However, you'll need to solder headers or wires of your choice to the board for a secure connection. You can choose between a combination of [header pins and jumper wires](https://learn.sparkfun.com/tutorials/how-to-solder-through-hole-soldering/all), or [stripping wire and soldering the wire](https://learn.sparkfun.com/tutorials/working-with-wire/all) directly to the board.

<div class="grid cards col-2" markdown>

-   <a href="https://learn.sparkfun.com/tutorials/how-to-solder-through-hole-soldering/all">
      <figure markdown>
        How to Solder: Through Hole Soldering
      </figure>
    </a>

    ---

    <a href="https://learn.sparkfun.com/tutorials/how-to-solder-through-hole-soldering/all">
      <b>How to Solder: Through Hole Soldering</b>
    </a>
<!-- ----------WHITE SPACE BETWEEN GRID CARDS---------- -->

-   <a href="https://learn.sparkfun.com/tutorials/working-with-wire/all">
      <figure markdown>
        Working with Wire
      </figure>
    </a>

    ---

    <a href="https://learn.sparkfun.com/tutorials/working-with-wire/all">
      <b>Working with Wire</b>
    </a>
<!-- ----------WHITE SPACE BETWEEN GRID CARDS---------- -->
</div>

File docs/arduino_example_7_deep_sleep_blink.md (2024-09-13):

In this example, we will show how to set your board in deep sleep, blink the user LED as an indicator, and then go back into power saving mode.

!!! note
    This is a modified example from the Realtek's Arduino example for [Deep Sleep Mode](https://www.amebaiot.com/en/amebad-arduino-deepsleepmode/).

### Hardware Hookup

For users interested in measuring the current draw via the MEAS jumper, you can cut the trace located on the back of the board. Power the board via USB or battery. Then place a [multimeter set to measure current](https://learn.sparkfun.com/tutorials/how-to-use-a-multimeter#measuring-current) on the PTHs. This makes it easier to measure the current as opposed to measuring the current between the power source and connector.

!!! note
    The MEAS jumper is before the XC6222 3.3V voltage regulator. For users that are connecting power to the 3V3 pin or Qwiic connector, you will need to place a multimeter between the regulated 3.3V power source and the board.

<div style="text-align: center;">
  <table>
    <tr style="vertical-align:middle;">
     <td style="text-align: center; vertical-align: middle; border: solid 1px #cccccc;"><a href="../assets/img/WRL-21637_Thing_Plus_NORA-W306_MEAS_Jumper_Modified.jpg">MEAS Jumper Modified</a></td>
    </tr>
    <tr style="vertical-align:middle;">
     <td style="text-align: center; vertical-align: middle; border: solid 1px #cccccc;"><i>MEAS Jumper Modified</i></td>
    </tr>
  </table>
</div>

To upload code, connect the USB cable to the SparkFun Thing Plus NORA-W306. Of course, make sure to connect the other end to your computer.

<div style="text-align: center;">
  <table>
    <tr style="vertical-align:middle;">
     <td style="text-align: center; vertical-align: middle; border: solid 1px #cccccc;"><a href="../assets/img/WRL-21637_Thing_Plus_NORA-W306_USB_Cable.jpg">USB Cable inserted into Thing Plus NORA-W306</a></td>
    </tr>
    <tr style="vertical-align:middle;">
     <td style="text-align: center; vertical-align: middle; border: solid 1px #cccccc;"><i>USB Cable inserted into Thing Plus NORA-W306</i></td>
    </tr>
  </table>
</div>

!!! tip
    Make sure to add a solder blob on the MEAS jumper when finished measuring. Users can also solder a [2-pin male header](https://www.sparkfun.com/products/116) and [shunt](https://www.sparkfun.com/products/9044) to the PTHs to easily remove/add the connection.

### Arduino Code

This example builds upon Realtek's deep sleep mode. Once the deep sleep modes are set up, the NORA-W306 goes into deep sleep. In this particular example, we will use the timer (i.e. `SET_DS_AON_TIMER_WAKEUP`) as the source. After 5 seconds, the board wakes up with the user LED also blinking five times before going back to deep sleep for 5 seconds.

!!! note
    The serial UART is disabled to reduce amount the peripherals that are turned on. To save more power, you can cut the JP3 and PWR LED jumpers. There is also a fancy circuit to disable power to the CP2102 when there is no USB power. As an alternative to USB power, users can power the board with a LiPo battery.

Copy and paste the following code in the Arduino IDE. Select your Board (in this case the **SparkFun Thing Plus NORA-W306 (RTL8720DF)**), and associated COM port (in this case **COM13**). Then hit the upload button.

``` C++
/*
* SparkFun Electronics
* 7/17/2024
*
* SparkFun_ThingPlus_NORAW306_DeepSleepBlink.ino
*
* Deep Sleep mode example for the SparkFun Thing Plus NORA-W306
*
* This example demonstrates how to put the NORA-W306 into deep sleep mode and
* wake it up using the AON timer (every 5 seconds).
* When awake, the onboard LED will blink.
* When asleep, the current consumption can be monitored using the MEAS jumper.
*
* Hardware Hookup and Instructions:
*   Connect the NORA-W306 to your computer using a USB-C cable.
*   Upload this code to the NORA-W306.
*   To measure the low-power consumption of the NORA-W306, remove USB-C cable
*   and utilize the MEAS jumper to measure the current consumption.
*   
* Software versions used in this example:
*   Arduino IDE 2.3.2
*   Realtek Ameba Boards (32-bits ARM Cortex-M33 @200MHz) by Realtek Version 3.1.8
*     (https://github.com/ambiot/ambd_arduino)
*     (https://raw.githubusercontent.com/ambiot/ambd_arduino/dev/Arduino_package/package_realtek_amebad_early_index.json)
*
* Original code is from the following example in the RealTek Ameba Arduino package:
*  Examples -> AmebaPowerSave -> DeepSleepMode.ino
*
* MIT License
*
* Copyright (c) 2024 SparkFun Electronics
*
* Permission is hereby granted, free of charge, to any person obtaining a copy of
* this software and associated documentation files (the "Software"), to deal in the
* Software without restriction, including without limitation the rights to use,
* copy, modify, merge, publish, distribute, sublicense, and/or sell copies of the
* Software, and to permit persons to whom the Software is furnished to do so,
* subject to the following conditions:
*
* The above copyright notice and this permission notice shall be included in all
* copies or substantial portions of the Software.
*
* THE SOFTWARE IS PROVIDED "AS IS", WITHOUT WARRANTY OF ANY KIND, EXPRESS OR IMPLIED,
* INCLUDING BUT NOT LIMITED TO THE WARRANTIES OF MERCHANTABILITY, FITNESS FOR A
* PARTICULAR PURPOSE AND NONINFRINGEMENT. IN NO EVENT SHALL THE AUTHORS OR COPYRIGHT
* HOLDERS BE LIABLE FOR ANY CLAIM, DAMAGES OR OTHER LIABILITY, WHETHER IN AN ACTION
* OF CONTRACT, TORT OR OTHERWISE, ARISING FROM, OUT OF OR IN CONNECTION WITH THE
* SOFTWARE OR THE USE OR OTHER DEALINGS IN THE SOFTWARE.
*/

#include <PowerSave.h>

//SET_DS_AON_TIMER_WAKEUP
//SET_DS_RTC_WAKEUP
//For AMB21/22 only the AON GPIO pins listed below should be selected
    //SET_AON_GPIO_WAKEUP_PA25          // pin 16
    //SET_AON_GPIO_WAKEUP_PA26          // pin 17
    //SET_AON_GPIO_WAKEUP_PA21          // pin 26
    //SET_AON_GPIO_WAKEUP_PA20          // pin 27
    //SET_AON_GPIO_WAKEUP_PA19          // pin 28
//For AMB23 only the AON GPIO pins listed below should be selected
    //SET_AON_GPIO_WAKEUP_PA12          // pin 9
    //SET_AON_GPIO_WAKEUP_PA13          // pin 10
    //SET_AON_GPIO_WAKEUP_PA14          // pin 11
    //SET_AON_GPIO_WAKEUP_PA15          // pin 12
    //SET_AON_GPIO_WAKEUP_PA16          // pin 13
    //SET_AON_GPIO_WAKEUP_PA18          // pin 15
    //SET_AON_GPIO_WAKEUP_PA19          // pin 16
    //SET_AON_GPIO_WAKEUP_PA21          // pin 18
//For BW16/BW16-TypeC only the AON GPIO pins listed below should be selected
    //SET_AON_GPIO_WAKEUP_PA25          // pin 7
    //SET_AON_GPIO_WAKEUP_PA26          // pin 8
    //SET_AON_GPIO_WAKEUP_PA15          // pin 9
    //SET_AON_GPIO_WAKEUP_PA14          // pin 10
    //SET_AON_GPIO_WAKEUP_PA13          // pin 11
    //SET_AON_GPIO_WAKEUP_PA12          // pin 12
//For board AW-CU488_ThingPlus
    //SET_AON_GPIO_WAKEUP_PA18          // pin 0
    //SET_AON_GPIO_WAKEUP_PA16          // pin 1
    //SET_AON_GPIO_WAKEUP_PA17          // pin 2
    //SET_AON_GPIO_WAKEUP_PA13          // pin 3
    //SET_AON_GPIO_WAKEUP_PA12          // pin 4
    //SET_AON_GPIO_WAKEUP_PA26          // pin 5
    //SET_AON_GPIO_WAKEUP_PA25          // pin 6
    //SET_AON_GPIO_WAKEUP_PA19          // pin 8
    //SET_AON_GPIO_WAKEUP_PA15          // pin 28
    //SET_AON_GPIO_WAKEUP_PA14          // pin 29
//For board AMB25/AMB26
    //SET_AON_GPIO_WAKEUP_PA12          // pin 3
    //SET_AON_GPIO_WAKEUP_PA13          // pin 2
    //SET_AON_GPIO_WAKEUP_PA14          // pin 1
    //SET_AON_GPIO_WAKEUP_PA15          // pin 0
    //SET_AON_GPIO_WAKEUP_PA25          // pin 7
    //SET_AON_GPIO_WAKEUP_PA26          // pin 6
//For board SparkFun Thing Plus NORA-W306
    //SET_AON_GPIO_WAKEUP_PA18          // pin 6
    //SET_AON_GPIO_WAKEUP_PA13          // pin 13
    //SET_AON_GPIO_WAKEUP_PA12          // pin 14
    //SET_AON_GPIO_WAKEUP_PA26          // pin 11
    //SET_AON_GPIO_WAKEUP_PA25          // pin 12
    //SET_AON_GPIO_WAKEUP_PA15          // pin 15
    //SET_AON_GPIO_WAKEUP_PA14          // pin 16

#define DS_WAKEUP_SOURCE                SET_DS_AON_TIMER_WAKEUP

#define AON_TIMER_SLEEP_DURATION        5000
#define DS_RTC_ALARM_DAY                0
#define DS_RTC_ALARM_HOUR               0
#define DS_RTC_ALARM_MIN                0
#define DS_RTC_ALARM_SEC                10

void DeepSleep_wakeup(void) {
    //printf("\r\nDeep sleep wakeuped! \r\n");
    uint32_t wakereason_number = PowerSave.AONWakeReason();

    //pinMode(17, OUTPUT); // 17 SDPC uSD power control
    //digitalWrite(17, LOW); // Turn on uSD power if you'd like to measure its current consumption   

    if (wakereason_number == AONWakeReason_AON_GPIO) {
        //printf("AonWakepin wakeup. Wait 5s sleep again.    \r\n");
        delay(5000);
    } else if (wakereason_number == AONWakeReason_AON_TIMER) {
        PowerSave.AONTimerCmd();
        //printf("AonTimer wakeup. Wait 5s sleep again.    \r\n");

        pinMode(LED_BUILTIN, OUTPUT);
        for(int i = 0 ; i < 5 ; i ++)
        {
          digitalWrite(LED_BUILTIN, HIGH);
          delay(1000);
          digitalWrite(LED_BUILTIN, LOW);
          delay(1000);
        }
        pinMode(LED_BUILTIN, INPUT);
        //delay(5000);
    } else if (wakereason_number == AONWakeReason_RTC) {
        //printf("RTC wakeup. Wait 5s sleep again.    \r\n");
        delay(5000);
    }

    //pinMode(17, INPUT_PULLUP); // 17 SDPC uSD power control (Pullup = off)

    PowerSave.AONWakeClear();
}

void setup() {
    // If you want serial debug messages, uncomment the following lines and others
    // below, as desired.
    // Open serial communications and wait for port to open:
    // Serial.begin(115200);
    // while (!Serial) {
    //     ; // wait for serial port to connect. Needed for native USB port only
    // }

    // Pin configuration - specific to the SparkFun Thing Plus NORA-W306

    pinMode(0, INPUT_PULLDOWN); // LOG RX, can backpower the CP2102
    pinMode(1, INPUT_PULLDOWN); // LOG TX, can backpower the CP2102
    pinMode(4, INPUT_PULLDOWN); // SPI0_CS, can sink current from 3V3 via R16 (100K), note, this is only possible if you leave uSD power on
    pinMode(5, INPUT_PULLDOWN); // SPI0_CLK
    pinMode(6, INPUT_PULLDOWN); // SPI0_PICO
    pinMode(7, INPUT_PULLDOWN); // SPI0_POCI

    pinMode(11, INPUT_PULLUP); // SDA
    pinMode(12, INPUT_PULLUP); // SCL
    pinMode(17, INPUT_PULLUP); // 17 SDPC uSD power control
    pinMode(20, INPUT_PULLNONE); // aka PB_24, this is tied internally to PB_23 (aka Arduino pin "17") and also defaults to internal pulldown.

    PowerSave.begin(DEEPSLEEP_MODE);

    if (TRUE == (PowerSave.DsleepWakeStatusGet())) {
        DeepSleep_wakeup();
    }

    PowerSave.AONTimerDuration(0);

    switch (DS_WAKEUP_SOURCE) {
        case SET_DS_AON_TIMER_WAKEUP:
            PowerSave.DS_AON_TIMER_WAKEUP();
            PowerSave.AONTimerDuration(AON_TIMER_SLEEP_DURATION);
            break;
        case SET_DS_RTC_WAKEUP:
            PowerSave.DS_RTC_WAKEUP();
            PowerSave.RTCWakeSetup(DS_RTC_ALARM_DAY, DS_RTC_ALARM_HOUR, DS_RTC_ALARM_MIN, DS_RTC_ALARM_SEC);
            break;
        case SET_AON_GPIO_WAKEUP_PA12:
            PowerSave.AON_WAKEPIN_WAKEUP_PA12();
            break;
        case SET_AON_GPIO_WAKEUP_PA13:
            PowerSave.AON_WAKEPIN_WAKEUP_PA13();
            break;
        case SET_AON_GPIO_WAKEUP_PA14:
            PowerSave.AON_WAKEPIN_WAKEUP_PA14();
            break;
        case SET_AON_GPIO_WAKEUP_PA15:
            PowerSave.AON_WAKEPIN_WAKEUP_PA15();
            break;
        case SET_AON_GPIO_WAKEUP_PA16:
            PowerSave.AON_WAKEPIN_WAKEUP_PA16();
            break;
        case SET_AON_GPIO_WAKEUP_PA17:
            PowerSave.AON_WAKEPIN_WAKEUP_PA17();
            break;
        case SET_AON_GPIO_WAKEUP_PA18:
            PowerSave.AON_WAKEPIN_WAKEUP_PA18();
            break;
        case SET_AON_GPIO_WAKEUP_PA19:
            PowerSave.AON_WAKEPIN_WAKEUP_PA19();
            break;
        case SET_AON_GPIO_WAKEUP_PA20:
            PowerSave.AON_WAKEPIN_WAKEUP_PA20();
            break;
        case SET_AON_GPIO_WAKEUP_PA21:
            PowerSave.AON_WAKEPIN_WAKEUP_PA21();
            break;
        case SET_AON_GPIO_WAKEUP_PA25:
            PowerSave.AON_WAKEPIN_WAKEUP_PA25();
            break;
        case SET_AON_GPIO_WAKEUP_PA26:
            PowerSave.AON_WAKEPIN_WAKEUP_PA26();
            break;
        default:
            printf("Unknown wakeup source.    \r\n");
        break;
    }

    PowerSave.enable();
}

void loop() {
    delay(1000);
}
```

Once connected, choose a power source to connect to the SparkFun Thing Plus NORA-W306. This can be through the PTHs on the edge of the board (VU, VB, or 3V3) or the connectors (USB C, 2-pin JST, or Qwiic). Note that the board will draw more power through the USB C connector and VU PTH as this will power the CP2102. Power will also be drawn with the LiPo charger and 3.3V voltage regulator.

Below are a few diagrams showing two possible ways to measure the current draw when the board is in deep sleep mode.

<div style="text-align: center;">
  <table>
    <tr style="vertical-align:middle;">
     <td style="text-align: center; vertical-align: middle; border: solid 1px #cccccc;"><a href="../assets/img/NORA-W306_Low_Power_Deep_Sleep_Multimeter_bb.jpg">Fritzing Diagram of Multimeter Measuring Current through MEAS and a LiPo Battery as the Power Source</a></td>
     <td style="text-align: center; vertical-align: middle; border: solid 1px #cccccc;"><a href="../assets/img/NORA-W306_Low_Power_Deep_Sleep_Multimeter_PTH_bb.jpg">Fritzing Diagram of Multimeter Measuring Current LiPo Battery and Board</a></td>
    </tr>
    <tr style="vertical-align:middle;">
     <td style="text-align: center; vertical-align: middle; border: solid 1px #cccccc;"><i>Fritzing Diagram of Multimeter Measuring Current through MEAS and a LiPo Battery as the Power Source</i></td>
     <td style="text-align: center; vertical-align: middle; border: solid 1px #cccccc;"><i>Fritzing Diagram of Multimeter Measuring Current LiPo Battery and Board</i></td>
    </tr>
  </table>
</div>

If you haven't already, check out the demo video that was linked earlier in the hardware overview showing the current draw for the board in low power mode!

<div style="text-align: center;">
  <iframe width="560" height="315" src="https://www.youtube.com/embed/ElCYbEnyYH4?si=EVBnWnvqqZ6KBMxX" title="YouTube video player" frameborder="0" allow="accelerometer; autoplay; clipboard-write; encrypted-media; gyroscope; picture-in-picture; web-share" referrerpolicy="strict-origin-when-cross-origin" allowfullscreen></iframe>
</div>

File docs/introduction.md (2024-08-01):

The [SparkFun Thing Plus - NORA-W306](https://www.sparkfun.com/products/21637) is a Feather form-factor development board equipped with the u-blox NORA-W306 module. The module contains a Realtek RTL8720DF, which has an integrated single-chip low-power dual-band (2.4GHz and 5GHz) Wireless LAN (WLAN) and Bluetooth&reg; Low Energy (BLE 5.3) communication microcontroller. It also consists of a dual processor core: Arm Cortex-M33 and Cortex-M23. To complement the module's low-power options, we've optimized components and added the ability to depower all subsystems to conserve as much power as possible for remote battery-powered applications.

<div class="grid cards" style="width:500px; margin: 0 auto;" markdown>

-   <a href="https://www.sparkfun.com/products/21637">
      <figure markdown>
        SparkFun Thing Plus NORA-W306
      </figure>
    </a>

    ---

    <a href="https://www.sparkfun.com/products/21637">
      <b>SparkFun Thing Plus NORA-W306</b>
      <br />
      WRL-21637
      <br />
      <center>[Purchase from SparkFun :fontawesome-solid-cart-plus:](https://www.sparkfun.com/products/21637){ .md-button .md-button--primary }</center>
    </a>

</div>

<div style="text-align: center;">
  <iframe width="560" height="315" src="https://www.youtube.com/embed/sLkoSZ7Aepk?si=EVbyI7tt1I8poK95" title="YouTube video player" frameborder="0" allow="accelerometer; autoplay; clipboard-write; encrypted-media; gyroscope; picture-in-picture; web-share" referrerpolicy="strict-origin-when-cross-origin" allowfullscreen></iframe>
</div>

In this tutorial, we'll go over the hardware and how to hookup the development board to an Arduino. We will also go over a few Arduino examples to get started!

### Required Materials

To follow along with this tutorial, you will need the following materials. You may not need everything though depending on what you have. Add it to your cart, read through the guide, and adjust the cart as necessary.

<!--

* 1x [USB micro-B Cable - 6 Foot [CAB-15425]](https://www.sparkfun.com/products/15425)
* 1x [SparkFun Thing Plus NORA-W306 [WRL-21637]](https://www.sparkfun.com/products/21637)
* 1x microSD Card
    * [microSD Card - 1GB (Class 4) [COM-15107]](https://www.sparkfun.com/products/15107) for those that are interested in logging data
* 1x microSD Card Adapter
* 1x Qwiic Cable
    * [Flexible Qwiic Cable - 50mm [PRT-17260]](https://www.sparkfun.com/products/17260), for short distances
    * [Flexible Qwiic Cable - 500mm [PRT-17257]](https://www.sparkfun.com/products/17257), for those that need to wire the board farther away from your microcontroller
* 1x [SparkFun Micro OLED Breakout (Qwiic) [SEN-22495]](https://www.sparkfun.com/products/22495) to Qwiic-ly connect and display readings

-->

<div class="grid cards col-4" markdown>

<!-- ----------WHITE SPACE BETWEEN PRODUCTS---------- -->
-   <a href="https://www.sparkfun.com/products/15425">
      <figure markdown>
        Reversible USB A to C Cable - 0.8m
      </figure>
    </a>

    ---

    <a href="https://www.sparkfun.com/products/15425">
      <b>Reversible USB A to C Cable - 0.8m</b>
      <br />
      CAB-15425
    </a>
<!-- ----------WHITE SPACE BETWEEN PRODUCTS---------- -->
-   <a href="https://www.sparkfun.com/products/21637">
      <figure markdown>
        SparkFun Thing Plus NORA-W306
      </figure>
    </a>

    ---

    <a href="https://www.sparkfun.com/products/21637">
      <b>SparkFun Thing Plus NORA-W306</b>
      <br />
      WRL-21637
    </a>
<!-- ----------WHITE SPACE BETWEEN PRODUCTS---------- -->
-   <a href="https://www.sparkfun.com/products/15107">
      <figure markdown>
        microSD Card - 1GB (Class 4)
      </figure>
    </a>

    ---

    <a href="https://www.sparkfun.com/products/15107">
      <b>microSD Card - 1GB (Class 4)</b>
      <br />
      COM-15107
    </a>
<!-- ----------WHITE SPACE BETWEEN PRODUCTS---------- -->
-   <a href="https://www.sparkfun.com/products/22495">
      <figure markdown>
        SparkFun Micro OLED Breakout (Qwiic)
      </figure>
    </a>

    ---

    <a href="https://www.sparkfun.com/products/22858">
      <b>SparkFun Micro OLED Breakout (Qwiic)</b>
      <br />
      SEN-22495
    </a>
<!-- ----------WHITE SPACE BETWEEN PRODUCTS---------- -->
-   <a href="https://www.sparkfun.com/products/17260">
      <figure markdown>
        Flexible Qwiic Cable - 50mm
      </figure>
    </a>

    ---

    <a href="https://www.sparkfun.com/products/17260">
      <b>Flexible Qwiic Cable - 50mm</b>
      <br>
      PRT-17260
    </a>
<!-- ----------WHITE SPACE BETWEEN PRODUCTS---------- -->

</div>

!!! note
    Make sure that you have a microSD card reader or adapter as well to read the contents saved on the memory card.

    <div style="text-align: center;">
      <table>
        <tr style="vertical-align:middle;">
         <td style="text-align: center; vertical-align: middle; border: solid 1px #cccccc;"><a href="https://cdn.sparkfun.com/assets/parts/7/6/3/6/11609-Action.jpg">MicroSD Card Adapters</a></td>
        </tr>
        <tr style="vertical-align:middle;">
         <td style="text-align: center; vertical-align: middle; border: solid 1px #cccccc;"><i>MicroSD Card Adapters</i></td>
      </table>
    </div>

### Tools (Optional)

You will need a soldering iron, solder, and [general soldering accessories](https://www.sparkfun.com/categories/49) for a secure connection when using the plated through holes. For users that are measuring the current draw, you may want to consider grabbing a digital multimeter or a USB C cable that is able to display the current draw.

<!--

* [Soldering Iron [TOL-14456]](https://www.sparkfun.com/products/14456)
* [Solder Lead Free - 15-gram Tube [TOL-9163]](https://www.sparkfun.com/products/9163)
* [Flush Cutters - Hakko [TOL-11952]](https://www.sparkfun.com/products/11952)
* [Hook-Up Wire - Assortment (Stranded, 22 AWG) [PRT-11375]](https://www.sparkfun.com/products/11375)
* [Wire Strippers - 30AWG (Hakko) [TOL-12630]](https://www.sparkfun.com/products/12630)

-->

<div class="grid cards col-4" markdown>

-   <a href="https://www.sparkfun.com/products/14456">
      <figure markdown>
        Soldering Iron - 60W (Adjustable Temperature)
      </figure>
    </a>

    ---

    <a href="https://www.sparkfun.com/products/14456">
      <b>Soldering Iron - 60W (Adjustable Temperature)</b>
      <br />
      TOL-14456
    </a>
<!-- ----------WHITE SPACE BETWEEN PRODUCTS---------- -->
-   <a href="https://www.sparkfun.com/products/9163">
      <figure markdown>
        Solder Lead Free - 15-gram Tube
      </figure>
    </a>

    ---

    <a href="https://www.sparkfun.com/products/9163">
      <b>Solder Lead Free - 15-gram Tube</b>
      <br>
      TOL-09163
    </a>
<!-- ----------WHITE SPACE BETWEEN PRODUCTS---------- -->
-   <a href="https://www.sparkfun.com/products/11375">
      <figure markdown>
        Hook-Up Wire - Assortment (Stranded, 22 AWG)
      </figure>
    </a>

    ---

    <a href="https://www.sparkfun.com/products/11375">
      <b>Hook-Up Wire - Assortment (Stranded, 22 AWG)</b>
      <br />
      PRT-11375
    </a>
<!-- ----------WHITE SPACE BETWEEN PRODUCTS---------- -->
-   <a href="https://www.sparkfun.com/products/12630">
      <figure markdown>
        Wire Strippers - 30AWG (Hakko)
      </figure>
    </a>

    ---

    <a href="https://www.sparkfun.com/products/12630">
      <b>Wire Strippers - 30AWG (Hakko)</b>
      <br />
      TOL-12630
    </a>
<!-- ----------WHITE SPACE BETWEEN PRODUCTS---------- -->
-   <a href="https://www.sparkfun.com/products/11952">
      <figure markdown>
        Flush Cutters - Hakko
      </figure>
    </a>

    ---

    <a href="https://www.sparkfun.com/products/11952">
      <b>Flush Cutters - Hakko</b>
      <br />
      TOL-11952
    </a>
<!-- ----------WHITE SPACE BETWEEN PRODUCTS---------- -->
-   <a href="https://www.sparkfun.com/products/12966">
      <figure markdown>
        Digital Multimeter - Basic
      </figure>
    </a>

    ---

    <a href="https://www.sparkfun.com/products/12966">
      <b>Digital Multimeter - Basic</b>
      <br />
      TOL-12966
    </a>
<!-- ----------WHITE SPACE BETWEEN PRODUCTS---------- -->
-   <a href="https://www.sparkfun.com/products/19718">
      <figure markdown>
        Fast Charging USB A to C Cable with LCD - 4ft (6A)
      </figure>
    </a>

    ---

    <a href="https://www.sparkfun.com/products/19718">
      <b>Fast Charging USB A to C Cable with LCD - 4ft (6A)</b>
      <br />
      CAB-19718
    </a>
<!-- ----------WHITE SPACE BETWEEN PRODUCTS---------- -->
</div>

### Prototyping Accessories

Depending on your setup, you may want to use IC hooks for a temporary connection. However, you will want to solder header pins to connect devices to the plated through holes for a secure connection.

<!--

* [Breadboard - Self-Adhesive (White) [PRT-12002]](https://www.sparkfun.com/products/12002)
* [IC Hook with Pigtail [CAB-09741]](https://www.sparkfun.com/products/9741)
* [Break Away Headers - Straight [PRT-00116]](https://www.sparkfun.com/products/116)
* [Feather Stackable Header Kit [PRT-15187]](https://www.sparkfun.com/products/15187)
* [Jumper Wires Premium 6" M/M Pack of 10 [PRT-08431]](https://www.sparkfun.com/products/8431)

-->

<div class="grid cards col-4" markdown>

-   <a href="https://www.sparkfun.com/products/12002">
      <figure markdown>
        Breadboard - Self-Adhesive (White)
      </figure>
    </a>

    ---

    <a href="https://www.sparkfun.com/products/12002">
      <b>Breadboard - Self-Adhesive (White)</b>
      <br />
      PRT-12002
    </a>
<!-- ----------WHITE SPACE BETWEEN PRODUCTS---------- -->
-   <a href="https://www.sparkfun.com/products/9741">
      <figure markdown>
        IC Hook with Pigtail
      </figure>
    </a>

    ---

    <a href="https://www.sparkfun.com/products/9741">
      <b>IC Hook with Pigtail</b>
      <br>
      CAB-09741
    </a>
<!-- ----------WHITE SPACE BETWEEN PRODUCTS---------- -->
-   <a href="https://www.sparkfun.com/products/116">
      <figure markdown>
        Break Away Headers - Straight
      </figure>
    </a>

    ---

    <a href="https://www.sparkfun.com/products/116">
      <b>Break Away Headers - Straight</b>
      <br />
      PRT-00116
    </a>
<!-- ----------WHITE SPACE BETWEEN PRODUCTS---------- -->
-   <a href="https://www.sparkfun.com/products/15187">
      <figure markdown>
        Feather Stackable Header Kit
      </figure>
    </a>

    ---

    <a href="https://www.sparkfun.com/products/15187">
      <b>Feather Stackable Header Kit</b>
      <br />
      PRT-15187
    </a>
<!-- ----------WHITE SPACE BETWEEN PRODUCTS---------- -->
-   <a href="https://www.sparkfun.com/products/9044">
      <figure markdown>
        Jumper - 2 Pin
      </figure>
    </a>

    ---

    <a href="https://www.sparkfun.com/products/9044">
      <b>Jumper - 2 Pin</b>
      <br />
      PRT-09044
    </a>
<!-- ----------WHITE SPACE BETWEEN PRODUCTS---------- -->
-   <a href="https://www.sparkfun.com/products/8431">
      <figure markdown>
        Jumper Wires Premium 6
      <br />
      PRT-08431
    </a>
<!-- ----------WHITE SPACE BETWEEN PRODUCTS---------- -->
</div>

### Qwiic Cables

For those that want to take advantage of the Qwiic enabled devices, you'll want to grab a Qwiic cable.

<div class="grid cards col-4" markdown>

-   <a href="https://www.sparkfun.com/products/15081">
      <figure markdown>
        SparkFun Qwiic Cable Kit
      </figure>
    </a>

    ---

    <a href="https://www.sparkfun.com/products/15081">
      <b>SparkFun Qwiic Cable Kit</b>
      <br />
      KIT-15081
    </a>
<!-- ----------WHITE SPACE BETWEEN PRODUCTS---------- -->
-   <a href="https://www.sparkfun.com/products/14427">
      <figure markdown>
        Qwiic Cable - 100mm
      </figure>
    </a>

    ---

    <a href="https://www.sparkfun.com/products/14427">
      <b>Qwiic Cable - 100mm</b>
      <br>
      PRT-14427
    </a>
<!-- ----------WHITE SPACE BETWEEN PRODUCTS---------- -->
-   <a href="https://www.sparkfun.com/products/14429">
      <figure markdown>
        Qwiic Cable - 500mm
      </figure>
    </a>

    ---

    <a href="https://www.sparkfun.com/products/14429">
      <b>Qwiic Cable - 500mm</b>
      <br />
      PRT-14429
    </a>
<!-- ----------WHITE SPACE BETWEEN PRODUCTS---------- -->
-   <a href="https://www.sparkfun.com/products/14425">
      <figure markdown>
        Qwiic Cable - Breadboard Jumper (4-pin)
      </figure>
    </a>

    ---

    <a href="https://www.sparkfun.com/products/14425">
      <b>Qwiic Cable - Breadboard Jumper (4-pin)</b>
      <br />
      PRT-14425
    </a>
<!-- ----------WHITE SPACE BETWEEN PRODUCTS---------- -->
</div>

### LiPo Battery

A [single-cell Lithium-ion battery](https://www.sparkfun.com/categories/tags/lithium-polymer) can be connected to the SparkFun Thing Plus NORA-W306 for portability.

<div class="grid cards col-4" markdown>

-   <a href="https://www.sparkfun.com/products/18286">
      <figure markdown>
        Lithium Ion Battery - 1250mAh (IEC62133 Certified)
      </figure>
    </a>

    ---

    <a href="https://www.sparkfun.com/products/18286">
      <b>Lithium Ion Battery - 1250mAh (IEC62133 Certified)</b>
      <br />
      PRT-18286
    </a>
<!-- ----------WHITE SPACE BETWEEN PRODUCTS---------- -->
-   <a href="https://www.sparkfun.com/products/13854">
      <figure markdown>
        Lithium Ion Battery - 850mAh
      </figure>
    </a>

    ---

    <a href="https://www.sparkfun.com/products/13854">
      <b>Lithium Ion Battery - 850mAh</b>
      <br>
      PRT-13854
    </a>
<!-- ----------WHITE SPACE BETWEEN PRODUCTS---------- -->
-   <a href="https://www.sparkfun.com/products/13856">
      <figure markdown>
        Lithium Ion Battery - 6Ah
      </figure>
    </a>

    ---

    <a href="https://www.sparkfun.com/products/13856">
      <b>Lithium Ion Battery - 6Ah</b>
      <br />
      PRT-13856
    </a>
<!-- ----------WHITE SPACE BETWEEN PRODUCTS---------- -->
</div>

### Suggested Reading

If you aren't familiar with the Qwiic Connection System, we recommend reading [here for an overview](https://www.sparkfun.com/qwiic).

<div style="text-align: center">
  <table style="border-style:none">
    <tr>
     <td style="text-align: center; vertical-align: middle;">
     <div style="text-align: center"><a href="https://www.sparkfun.com/qwiic">Qwiic Connection System Click to learn more about the Qwiic Connection System!</a>
     </div>
    </td>
    </tr>
    <tr>
      <td style="text-align: center; vertical-align: middle;"><div style="text-align: center"><i><a href="https://www.sparkfun.com/qwiic">Qwiic Connection System</a></i></div></td>
    </tr>
  </table>
</div>

If you aren’t familiar with the following concepts, we also recommend checking out a few of these tutorials before continuing.

<div class="grid cards col-4" markdown>

-   <a href="https://learn.sparkfun.com/tutorials/how-to-solder-through-hole-soldering">
      <figure markdown>
        How to Solder: Through-Hole Soldering
      </figure>
    </a>

    ---

    <a href="https://learn.sparkfun.com/tutorials/how-to-solder-through-hole-soldering">
      <b>How to Solder: Through-Hole Soldering</b>
    </a>
<!-- ----------WHITE SPACE BETWEEN GRID CARDS---------- -->
-   <a href="https://learn.sparkfun.com/tutorials/installing-arduino-ide">
      <figure markdown>
        Installing Arduino IDE
      </figure>
    </a>

    ---

    <a href="https://learn.sparkfun.com/tutorials/installing-arduino-ide">
      <b>Installing Arduino IDE</b>
    </a>
<!-- ----------WHITE SPACE BETWEEN GRID CARDS---------- -->
-   <a href="https://learn.sparkfun.com/tutorials/arduino-shields-v2">
      <figure markdown>
        Arduino Shields V2
      </figure>
    </a>

    ---

    <a href="https://learn.sparkfun.com/tutorials/arduino-shields-v2">
      <b>Arduino Shields V2</b>
    </a>
<!-- ----------WHITE SPACE BETWEEN GRID CARDS---------- -->
-   <a href="https://learn.sparkfun.com/tutorials/i2c">
      <figure markdown>
        I2C
      </figure>
    </a>

    ---

    <a href="https://learn.sparkfun.com/tutorials/i2c">
      <b>I2C</b>
    </a>
<!-- ----------WHITE SPACE BETWEEN GRID CARDS---------- -->
-   <a href="https://learn.sparkfun.com/tutorials/installing-board-definitions-in-the-arduino-ide">
      <figure markdown>
        Installing Board Definitions in the Arduino IDE
      </figure>
    </a>

    ---

    <a href="https://learn.sparkfun.com/tutorials/installing-board-definitions-in-the-arduino-ide">
      <b>Installing Board Definitions in the Arduino IDE</b>
    </a>
<!-- ----------WHITE SPACE BETWEEN GRID CARDS---------- -->
-   <a href="https://learn.sparkfun.com/tutorials/serial-communication">
      <figure markdown>
        Serial Communication
      </figure>
    </a>

    ---

    <a href="https://learn.sparkfun.com/tutorials/serial-communication">
      <b>Serial Communication</b>
    </a>
<!-- ----------WHITE SPACE BETWEEN GRID CARDS---------- -->
-   <a href="https://learn.sparkfun.com/tutorials/serial-peripheral-interface-spi">
      <figure markdown>
        Serial Peripheral Interface (SPI)
      </figure>
    </a>

    ---

    <a href="https://learn.sparkfun.com/tutorials/serial-peripheral-interface-spi">
      <b>Serial Peripheral Interface (SPI)</b>
    </a>
<!-- ----------WHITE SPACE BETWEEN GRID CARDS---------- -->
-   <a href="https://learn.sparkfun.com/tutorials/pulse-width-modulation">
      <figure markdown>
        Pulse Width Modulation
      </figure>
    </a>

    ---

    <a href="https://learn.sparkfun.com/tutorials/pulse-width-modulation">
      <b>Pulse Width Modulation</b>
    </a>
<!-- ----------WHITE SPACE BETWEEN GRID CARDS---------- -->
-   <a href="https://learn.sparkfun.com/tutorials/logic-levels">
      <figure markdown>
        Logic Levels
      </figure>
    </a>

    ---

    <a href="https://learn.sparkfun.com/tutorials/logic-levels">
      <b>Logic Levels</b>
    </a>
<!-- ----------WHITE SPACE BETWEEN GRID CARDS---------- -->
-   <a href="https://learn.sparkfun.com/tutorials/analog-vs-digital">
      <figure markdown>
        Analog vs. Digital
      </figure>
    </a>

    ---

    <a href="https://learn.sparkfun.com/tutorials/analog-vs-digital">
      <b>Analog vs. Digital</b>
    </a>
<!-- ----------WHITE SPACE BETWEEN GRID CARDS---------- -->
-   <a href="https://learn.sparkfun.com/tutorials/ws2812-breakout-hookup-guide/">
      <figure markdown>
        WS2812 Breakout Hookup Guide
      </figure>
    </a>

    ---

    <a href="https://learn.sparkfun.com/tutorials/ws2812-breakout-hookup-guide/">
      <b>WS2812 Breakout Hookup Guide</b>
    </a>
<!-- ----------WHITE SPACE BETWEEN GRID CARDS---------- -->
-   <a href="https://learn.sparkfun.com/tutorials/single-cell-lipo-battery-care">
      <figure markdown>
        Single Cell LiPo Battery Care
      </figure>
    </a>

    ---

    <a href="https://learn.sparkfun.com/tutorials/single-cell-lipo-battery-care">
      <b>Single Cell LiPo Battery Care</b>
    </a>
<!-- ----------WHITE SPACE BETWEEN GRID CARDS---------- -->
-   <a href="https://learn.sparkfun.com/tutorials/lipo-fuel-gauge-max1704x-hookup-guide">
      <figure markdown>
        LiPo Fuel Gauge (MAX1704X) Hookup Guide
      </figure>
    </a>

    ---

    <a href="https://learn.sparkfun.com/tutorials/lipo-fuel-gauge-max1704x-hookup-guide">
      <b>LiPo Fuel Gauge (MAX1704X) Hookup Guide</b>
    </a>
<!-- ----------WHITE SPACE BETWEEN GRID CARDS---------- -->
</div>

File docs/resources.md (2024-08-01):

Now that you've successfully got your SparkFun Thing Plus - NORA-W306 up and running, it's time to incorporate it into your own project! For more information, check out the resources below:

* [Schematic (PDF)](../assets/board_files/SparkFun_Thing_Plus_NORA_W306_Schematic_v10.pdf)
* [Eagle Files (ZIP)](../assets/board_files/SparkFun_Thing_Plus_NORA_W306_v1_0.zip)
* [Board Dimensions (PNG)](../assets/img/SparkFun_Thing_Plus_NORA-W306_Board_Dimensions.png)
* Component Datasheets
    * u-blox NORA-W306
        * [Product Summary (PDF)](../assets/component_documentation/NORA-W30_ProductSummary_UBX-22006516.pdf)
        * [Datasheet (PDF)](../assets/component_documentation/NORA-W30_DataSheet_UBX-22021117.pdf)
        * [Integration Manual (PDF)](../assets/component_documentation/NORA-W30_SIM_UBX-22021119.pdf)
    * [XC6222 3.3V/700mA Voltage Regulator (PDF)](../assets/component_documentation/xc6222.pdf)
    * [MCP73831 LiPo Charger (PDF)](../assets/component_documentation/MCP73831.pdf)
    * [MAX17048 LiPo Fuel Gauge (PDF)](../assets/component_documentation/MAX17048.pdf)
    * [WS2812C-2020 RGB Addressable LED (PDF)](../assets/component_documentation/WS2812C-2020.pdf)
* [Graphical Datasheet](../assets/img/SparkFun_Thing_Plus_NORA-W306_u-blox.pdf)
* [Fritzing Part](https://github.com/sparkfun/Fritzing_Parts/blob/main/products/21637_sfe_thing_plus_u-blox_NORA-W306_development_board_lipo_charger_fuel_gauge_qwiic_WS2812.fzpz)
* [Qwiic Info Page](https://www.sparkfun.com/qwiic)
* [Compare Thing Plus Boards](https://www.sparkfun.com/thing_plus)
* [CP210X Drivers](https://www.silabs.com/developers/usb-to-uart-bridge-vcp-drivers)
* [Realtek: Arduino Board Support Files](https://github.com/ambiot/ambd_arduino)
* Arduino Libraries
    * [MAX17048](https://github.com/sparkfun/SparkFun_MAX1704x_Fuel_Gauge_Arduino_Library)
    * [SdFat](https://github.com/greiman/SdFat)
    * [Qwiic OLED](https://github.com/sparkfun/SparkFun_Qwiic_OLED_Arduino_Library)
* [GitHub Hardware Repo](https://github.com/sparkfun/SparkFun_Thing_Plus_NORA-W306)
* [SFE Product Showcase](https://youtu.be/sLkoSZ7Aepk?si=6z98aLXZULI_bts6)

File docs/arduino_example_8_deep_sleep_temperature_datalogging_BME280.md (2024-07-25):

In this example, we will read sensor readings from a BME280, log the data to a microSD card, and then go into deep sleep.

### Hardware Hookup

To take advantage of the SD power control (SDPC), you will need to make sure to cut the trace on the back of the board and add a solder blob between the center pad and pad labeled as `17`.

<div style="text-align: center;">
  <table>
    <tr style="vertical-align:middle;">
     <td style="text-align: center; vertical-align: middle; border: solid 1px #cccccc;"><a href="../assets/img/WRL-21637_Thing_Plus_NORA-W306_SDPC_Jumper_Modification.jpg">MicroSD Card Power Control Jumper Modified</a></td>
    </tr>
    <tr style="vertical-align:middle;">
     <td style="text-align: center; vertical-align: middle; border: solid 1px #cccccc;"><i>MicroSD Card Power Control Jumper Modified</i></td>
    </tr>
  </table>
</div>

When ready, insert a microSD card into the socket on the back of the board. Then connect the Qwiic BME280 to the SparkFun Thing Plus NORA-W306 using a Qwiic cable.

<div style="text-align: center;">
  <table>
    <tr style="vertical-align:middle;">
     <td style="text-align: center; vertical-align: middle; border: solid 1px #cccccc;"><a href="../assets/img/NORA-W306_Low_Power_Deep_Sleep_microSD_BME280_bb.jpg">Fritzing Diagram BME280 connected to NORA-W306 via Qwiic</a></td>
    </tr>
    <tr style="vertical-align:middle;">
     <td style="text-align: center; vertical-align: middle; border: solid 1px #cccccc;"><i>Fritzing Diagram BME280 connected to NORA-W306 via Qwiic</i></td>
    </tr>
  </table>
</div>

Connect a USB cable to the board to power and upload code.

### Arduino Code

This example builds upon Realtek's deep sleep like the previous example. In addition to blinking the LED, we will also read the temperature from a BME280 and write the sensor data to the microSD card.

Copy and paste the following code in the Arduino IDE. Select your Board (in this case the **SparkFun Thing Plus NORA-W306 (RTL8720DF)**), and associated COM port (in this case **COM23**). Then hit the upload button.

``` C++
/*
* SparkFun Electronics
* 7/17/2024
*
* SparkFun_ThingPlus_NORAW306_DeepSleepTempLogger.ino
*
* Deep Sleep mode with data logging  - example for the SparkFun Thing Plus NORA-W306
*
* This example demonstrates how to put the NORA-W306 into deep sleep mode and
* wake it up using the AON timer (every 5 seconds).
* When awake, it will log the temperature from the BME280 sensor to the uSD card.
* When awake, it will also blink the stat LED three times to indicate a log has happened.
* When asleep, the current consumption can be monitored using the MEAS jumper.
*
* Hardware Hookup and Instructions:
*   Connect the NORA-W306 to your computer using a USB-C cable.
*   Connect the BME280 sensor with a Qwiic Cable.
*   Upload this code to the NORA-W306.
*   To measure the low-power consumption of the NORA-W306, remove USB-C cable
*   and utilize the MEAS jumper to measure the current consumption.
*   
* Software versions used in this example:
*   Arduino IDE 2.3.2
*   Realtek Ameba Boards (32-bits ARM Cortex-M33 @200MHz) by Realtek Version 3.1.8
*     (https://github.com/ambiot/ambd_arduino)
*     (https://raw.githubusercontent.com/ambiot/ambd_arduino/dev/Arduino_package/package_realtek_amebad_early_index.json)
*   BME280 library by SparkFun Electronics
*     (https://github.com/sparkfun/SparkFun_BME280_Arduino_Library)
*
* Original code is from the following example in the RealTek Ameba Arduino package:
*  Examples -> AmebaPowerSave -> DeepSleepMode.ino
*
* MIT License
*
* Copyright (c) 2024 SparkFun Electronics
*
* Permission is hereby granted, free of charge, to any person obtaining a copy of
* this software and associated documentation files (the "Software"), to deal in the
* Software without restriction, including without limitation the rights to use,
* copy, modify, merge, publish, distribute, sublicense, and/or sell copies of the
* Software, and to permit persons to whom the Software is furnished to do so,
* subject to the following conditions:
*
* The above copyright notice and this permission notice shall be included in all
* copies or substantial portions of the Software.
*
* THE SOFTWARE IS PROVIDED "AS IS", WITHOUT WARRANTY OF ANY KIND, EXPRESS OR IMPLIED,
* INCLUDING BUT NOT LIMITED TO THE WARRANTIES OF MERCHANTABILITY, FITNESS FOR A
* PARTICULAR PURPOSE AND NONINFRINGEMENT. IN NO EVENT SHALL THE AUTHORS OR COPYRIGHT
* HOLDERS BE LIABLE FOR ANY CLAIM, DAMAGES OR OTHER LIABILITY, WHETHER IN AN ACTION
* OF CONTRACT, TORT OR OTHERWISE, ARISING FROM, OUT OF OR IN CONNECTION WITH THE
* SOFTWARE OR THE USE OR OTHER DEALINGS IN THE SOFTWARE.
*/

// variables to store the readings from the sensor
float humidity;
float pressure;
float altitude;
float temperature;

#include "SdFat.h"
#include "sdios.h"

File myFile;

/*
  Set DISABLE_CS_PIN to disable a second SPI device.
  For example, with the Ethernet shield, set DISABLE_CS_PIN
  to 10 to disable the Ethernet controller.
*/
const int8_t DISABLE_CS_PIN = -1;
/*
  Change the value of SD_CS_PIN if you are using SPI
  and your hardware does not use the default value, SS.
  Common values are:
  Arduino Ethernet shield: pin 4
  Sparkfun SD shield: pin 8
  Adafruit SD shields and modules: pin 10
  SparkFun Thing Plus NORA-W306: Arduino pin 4 (aka SS/PB_21/SPI0_CS)
*/
// SDCARD_SS_PIN is defined for the built-in SD on some boards.
#ifndef SDCARD_SS_PIN
const uint8_t SD_CS_PIN = SS;
#else  // SDCARD_SS_PIN
const uint8_t SD_CS_PIN = SDCARD_SS_PIN;
#endif  // SDCARD_SS_PIN

// Try to select the best SD card configuration.
#if HAS_SDIO_CLASS
#define SD_CONFIG SdioConfig(FIFO_SDIO)
#elif ENABLE_DEDICATED_SPI
#define SD_CONFIG SdSpiConfig(SD_CS_PIN, DEDICATED_SPI, SD_SCK_MHZ(16))
#else  // HAS_SDIO_CLASS
#define SD_CONFIG SdSpiConfig(SD_CS_PIN, SHARED_SPI, SD_SCK_MHZ(16))
#endif  // HAS_SDIO_CLASS

//------------------------------------------------------------------------------
SdFs sd;
cid_t cid;
csd_t csd;
scr_t scr;
uint8_t cmd6Data[64];
uint32_t eraseSize;
uint32_t ocr;
static ArduinoOutStream cout(Serial);

#include <Wire.h>

#include "SparkFunBME280.h"
BME280 mySensor;

#include <PowerSave.h>

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

#define DS_WAKEUP_SOURCE                SET_DS_AON_TIMER_WAKEUP

#define AON_TIMER_SLEEP_DURATION        5000
#define DS_RTC_ALARM_DAY                0
#define DS_RTC_ALARM_HOUR               0
#define DS_RTC_ALARM_MIN                0
#define DS_RTC_ALARM_SEC                10

void DeepSleep_wakeup(void) {
    //printf("\r\nDeep sleep wakeuped! \r\n");
    uint32_t wakereason_number = PowerSave.AONWakeReason();

    readSensor();

    if (wakereason_number == AONWakeReason_AON_GPIO) {
        //printf("AonWakepin wakeup. Wait 5s sleep again.    \r\n");
        delay(5000);
    } else if (wakereason_number == AONWakeReason_AON_TIMER) {
        PowerSave.AONTimerCmd();
        //printf("AonTimer wakeup. Wait 5s sleep again.    \r\n");

        pinMode(LED_BUILTIN, OUTPUT);
        for(int i = 0 ; i < 3 ; i ++)
        {
          digitalWrite(LED_BUILTIN, HIGH);
          delay(100);
          digitalWrite(LED_BUILTIN, LOW);
          delay(100);
        }
        pinMode(LED_BUILTIN, INPUT);
        //delay(5000);
    } else if (wakereason_number == AONWakeReason_RTC) {

        printf("RTC wakeup. Wait 5s sleep again.    \r\n");

        delay(5000);
    }

    pinMode(0, INPUT_PULLDOWN); // LOG RX, can backpower the CP2102
    pinMode(1, INPUT_PULLDOWN); // LOG TX, can backpower the CP2102
    pinMode(4, INPUT_PULLDOWN); // SPI0_CS, can sink current from 3V3 via R16 (100K), note, this is only possible if you leave uSD power on
    pinMode(5, INPUT_PULLDOWN); // SPI0_CLK
    pinMode(6, INPUT_PULLDOWN); // SPI0_PICO
    pinMode(7, INPUT_PULLDOWN); // SPI0_POCI
    pinMode(11, INPUT_PULLUP); // SDA
    pinMode(12, INPUT_PULLUP); // SCL
    pinMode(17, INPUT_PULLUP); // 17 SDPC uSD power control
    pinMode(20, INPUT_PULLNONE); // aka PB_24, this is tied internally to PB_23 (aka Arduino pin "17") and also defaults to internal pulldown.

    PowerSave.AONWakeClear();
}

void setup() {
    // If you want serial debug messages, uncomment the following lines and others
    // below, as desired.
    // Open serial communications and wait for port to open:
    // Serial.begin(115200);
    // while (!Serial) {
    //     ; // wait for serial port to connect. Needed for native USB port only
    // }

    PowerSave.begin(DEEPSLEEP_MODE);

    if (TRUE == (PowerSave.DsleepWakeStatusGet())) {
        DeepSleep_wakeup();
    }

    PowerSave.AONTimerDuration(0);

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

    PowerSave.enable();
}

void loop() {
    delay(1000);
}

void readSensor()
{
    pinMode(0, INPUT); // LOG RX, can backpower the CP2102
    pinMode(1, OUTPUT); // LOG TX, can backpower the CP2102

    pinMode(11, OUTPUT); // SDA
    pinMode(12, OUTPUT); // SCL

    pinMode(17, OUTPUT); // 17 SDPC uSD power control
    digitalWrite(17, LOW); // uSD power GND = ON

    Serial.begin(115200);

    cout << F("SdFat version: ") << SD_FAT_VERSION_STR << endl;
    printConfig(SD_CONFIG);
uint32_t t = millis();
      if (!sd.cardBegin(SD_CONFIG)) {
    cout << F(
           "\nSD initialization failed.\n"
           "Do not reformat the card!\n"
           "Is the card correctly inserted?\n"
           "Is there a wiring/soldering problem?\n");
    if (isSpi(SD_CONFIG)) {
      cout << F(
           "Is SD_CS_PIN set to the correct value?\n"
           "Does another SPI device need to be disabled?\n"
           );
    }
    errorPrint();
    return;
  }

    t = millis() - t;
  cout << F("init time: ") << dec << t << " ms" << endl;

  if (!sd.card()->readCID(&cid) ||
      !sd.card()->readCSD(&csd) ||
      !sd.card()->readOCR(&ocr) ||
      !sd.card()->readSCR(&scr)) {
    cout << F("readInfo failed\n");
    errorPrint();
    return;
  }
  printCardType();
  cout << F("sdSpecVer: ") << 0.01*scr.sdSpecVer() << endl;
  cout << F("HighSpeedMode: ");
  if (scr.sdSpecVer() &&
    sd.card()->cardCMD6(0X00FFFFFF, cmd6Data) && (2 & cmd6Data[13])) {
    cout << F("true\n");
  } else {
    cout << F("false\n");
  }      
  cidDmp();
  csdDmp();
  cout << F("\nOCR: ") << uppercase << showbase;
  cout << hex << ocr << dec << endl;
  if (!mbrDmp()) {
    return;
  }
  if (!sd.volumeBegin()) {
    cout << F("\nvolumeBegin failed. Is the card formatted?\n");
    errorPrint();
    return;
  }
  dmpVol();

    Wire.begin();
    Wire.setClock(400000); //Increase to fast I2C speed!
    if (mySensor.beginI2C() == false) //Begin communication over I2C
    {
        printf("The sensor did not respond. Please check wiring.");
        while(1); //Freeze
    }

    mySensor.setMode(MODE_FORCED); //Wake up sensor and take reading

    while(mySensor.isMeasuring() == false) ; //Wait for sensor to start measurment
    while(mySensor.isMeasuring() == true) ; //Hang out while sensor completes the reading    

    humidity = mySensor.readFloatHumidity();
    pressure = mySensor.readFloatPressure();
    altitude = mySensor.readFloatAltitudeFeet();
    temperature = mySensor.readTempF();

    printf(" Humidity: ");
    printf("%d", int(humidity));

    printf(" Pressure: ");
    printf("%d", int(pressure));

    printf(" Altitude: ");
    printf("%d", int(altitude));

    printf(" Temperature: ");
    printf("%d", int(temperature));

    mySensor.setMode(MODE_SLEEP); //Sleep for now

    Wire.end();

    logDataToSd();
}

//------------------------------------------------------------------------------
void cidDmp() {
  cout << F("\nManufacturer ID: ");
  cout << uppercase << showbase << hex << int(cid.mid) << dec << endl;
  cout << F("OEM ID: ") << cid.oid[0] << cid.oid[1] << endl;
  cout << F("Product: ");
  for (uint8_t i = 0; i < 5; i++) {
    cout << cid.pnm[i];
  }
  cout << F("\nRevision: ") << cid.prvN() << '.' << cid.prvM() << endl;
  cout << F("Serial number: ") << hex << cid.psn() << dec << endl;
  cout << F("Manufacturing date: ");
  cout << cid.mdtMonth() << '/' << cid.mdtYear() << endl;
  cout << endl;
}
//------------------------------------------------------------------------------
void clearSerialInput() {
  uint32_t m = micros();
  do {
    if (Serial.read() >= 0) {
      m = micros();
    }
  } while (micros() - m < 10000);
}
//------------------------------------------------------------------------------
void csdDmp() {
  eraseSize = csd.eraseSize();
  cout << F("cardSize: ") << 0.000512 * csd.capacity();
  cout << F(" MB (MB = 1,000,000 bytes)\n");

  cout << F("flashEraseSize: ") << int(eraseSize) << F(" blocks\n");
  cout << F("eraseSingleBlock: ");
  if (csd.eraseSingleBlock()) {
    cout << F("true\n");
  } else {
    cout << F("false\n");
  }
  cout << F("dataAfterErase: ");
  if (scr.dataAfterErase()) {
    cout << F("ones\n");
  } else {
    cout << F("zeros\n");
  }
}
//------------------------------------------------------------------------------
void errorPrint() {
  if (sd.sdErrorCode()) {
    cout << F("SD errorCode: ") << hex << showbase;
    printSdErrorSymbol(&Serial, sd.sdErrorCode());
    cout << F(" = ") << int(sd.sdErrorCode()) << endl;
    cout << F("SD errorData = ") << int(sd.sdErrorData()) << dec << endl;
  }
}
//------------------------------------------------------------------------------
bool mbrDmp() {
  MbrSector_t mbr;
  bool valid = true;
  if (!sd.card()->readSector(0, (uint8_t*)&mbr)) {
    cout << F("\nread MBR failed.\n");
    errorPrint();
    return false;
  }
  cout << F("\nSD Partition Table\n");
  cout << F("part,boot,bgnCHS[3],type,endCHS[3],start,length\n");
  for (uint8_t ip = 1; ip < 5; ip++) {
    MbrPart_t *pt = &mbr.part[ip - 1];
    if ((pt->boot != 0 && pt->boot != 0X80) ||
        getLe32(pt->relativeSectors) > csd.capacity()) {
      valid = false;
    }
    cout << int(ip) << ',' << uppercase << showbase << hex;
    cout << int(pt->boot) << ',';
    for (int i = 0; i < 3; i++ ) {
      cout << int(pt->beginCHS[i]) << ',';
    }
    cout << int(pt->type) << ',';
    for (int i = 0; i < 3; i++ ) {
      cout << int(pt->endCHS[i]) << ',';
    }
    cout << dec << getLe32(pt->relativeSectors) << ',';
    cout << getLe32(pt->totalSectors) << endl;
  }
  if (!valid) {
    cout << F("\nMBR not valid, assuming Super Floppy format.\n");
  }
  return true;
}
//------------------------------------------------------------------------------
void dmpVol() {
  cout << F("\nScanning FAT, please wait.\n");
  int32_t freeClusterCount = sd.freeClusterCount();
  if (sd.fatType() <= 32) {
    cout << F("\nVolume is FAT") << int(sd.fatType()) << endl;
  } else {
    cout << F("\nVolume is exFAT\n");
  }
  cout << F("sectorsPerCluster: ") << sd.sectorsPerCluster() << endl;
  cout << F("fatStartSector:    ") << sd.fatStartSector() << endl;
  cout << F("dataStartSector:   ") << sd.dataStartSector() << endl;
  cout << F("clusterCount:      ") << sd.clusterCount() << endl;  
  cout << F("freeClusterCount:  ");
  if (freeClusterCount >= 0) {
    cout << freeClusterCount << endl;
  } else {
    cout << F("failed\n");
    errorPrint();    
  }
}
//------------------------------------------------------------------------------
void printCardType() {
  cout << F("\nCard type: ");
  switch (sd.card()->type()) {
    case SD_CARD_TYPE_SD1:
      cout << F("SD1\n");
      break;
    case SD_CARD_TYPE_SD2:
      cout << F("SD2\n");
      break;
    case SD_CARD_TYPE_SDHC:
      if (csd.capacity() < 70000000) {
        cout << F("SDHC\n");
      } else {
        cout << F("SDXC\n");
      }
      break;
    default:
      cout << F("Unknown\n");
  }
}
//------------------------------------------------------------------------------
void printConfig(SdSpiConfig config) {
  if (DISABLE_CS_PIN < 0) {
    cout << F(
           "\nAssuming the SD is the only SPI device.\n"
           "Edit DISABLE_CS_PIN to disable an SPI device.\n");
  } else {
    cout << F("\nDisabling SPI device on pin ");
    cout << int(DISABLE_CS_PIN) << endl;
    pinMode(DISABLE_CS_PIN, OUTPUT);
    digitalWrite(DISABLE_CS_PIN, HIGH);
  }
  cout << F("\nAssuming the SD chip select pin is: ") << int(config.csPin);
  cout << F("\nEdit SD_CS_PIN to change the SD chip select pin.\n");
}
//------------------------------------------------------------------------------
void printConfig(SdioConfig config) {
  (void)config;
  cout << F("Assuming an SDIO interface.\n");
}

//------------------------------------------------------------------------------
void logDataToSd()
{
  // open the file. note that only one file can be open at a time,
  // so you have to close this one before opening another.
  myFile = sd.open("log.txt", FILE_WRITE);

  // if the file opened okay, write to it:
  if (myFile) {
    Serial.print("Writing to log.txt...");

    myFile.print("Humidity:");
    myFile.print(humidity);
    myFile.print(",Pressure:");
    myFile.print(pressure);
    myFile.print(",Altitude:");
    myFile.print(altitude);
    myFile.print(",Temperature:");
    myFile.println(temperature);

    // close the file:
    myFile.close();
    Serial.println("done.");
  } else {
    // if the file didn't open, print an error:
    Serial.println("error opening log.txt");
  }

  // re-open the file for reading:
  myFile = sd.open("log.txt");
  if (myFile) {
    Serial.println("log.txt:");

    // read from the file until there's nothing else in it:
    while (myFile.available()) {
      Serial.write(myFile.read());
    }
    // close the file:
    myFile.close();
  } else {
    // if the file didn't open, print an error:
    Serial.println("error opening log.txt");
  }
}

```

Open the Arduino Serial Monitor at **115200** to view the output. You should see the NORA-W306 wake up, read the sensor data, user LED blink, print the data as an integer through the serial terminal, write to a file, and then close the file. For verification, the code will also re-open the file, print the contents of the file, and then close the file again. This is a good time to verify if the sensor readings are being written at the end of the file.

<div style="text-align: center;">
  <table>
    <tr style="vertical-align:middle;">
     <td style="text-align: center; vertical-align: middle; border: solid 1px #cccccc;"><a href="../assets/img/NORA-W306_Deep_Sleep_DataLogging_BME280_Arduino.JPG">Arduino Output from the NORA-W306's Deep Sleep and Datalogging Example</a></td>
    </tr>
    <tr style="vertical-align:middle;">
     <td style="text-align: center; vertical-align: middle; border: solid 1px #cccccc;"><i>Arduino Output from the NORA-W306's Deep Sleep and Datalogging Example</i></td>
    </tr>
  </table>
</div>

!!! tip
    For users that need to comment out the lines of code to re-open the file and read the sensor data, you will just need to add a multiline comment (i.e. /* and `*/`) around the following lines of code as shown below.

    ``` c++
      // re-open the file for reading:
      /*myFile = sd.open("log.txt");
      if (myFile) {
        Serial.println("log.txt:");

        // read from the file until there's nothing else in it:
        while (myFile.available()) {
          Serial.write(myFile.read());
        }
        // close the file:
        myFile.close();
      } else {
        // if the file didn't open, print an error:
        Serial.println("error opening log.txt");
      }*/
    ```

!!! note
    The sensor output in the Arduino Serial Monitor displayed the sensor reading as integers. When writing to the file, the sensor readings were floats.

For those that want to verify through a text editor, remove the USB cable from the NORA-W306. Then remove the microSD card from the board. Connect the microSD card to your computer. Using a text editor, open the file labeled as **log.txt**. You should see the sensor readings that were logged earlier. You may have an additional line of comma separated values written to the file before removing power from the board.

<div style="text-align: center;">
  <table>
    <tr style="vertical-align:middle;">
     <td style="text-align: center; vertical-align: middle; border: solid 1px #cccccc;"><a href="../assets/img/NORA-W306_datalogging_log_file_BME280_sensor_reading.JPG">Log File Opened Through Text Editor Displaying Sensor Readings</a></td>
    </tr>
    <tr style="vertical-align:middle;">
     <td style="text-align: center; vertical-align: middle; border: solid 1px #cccccc;"><i>Log File Opened Through Text Editor Displaying Sensor Readings</i></td>
    </tr>
  </table>
</div>

For those interested in viewing the current consumption, cut the MEAS jumper on the back of the NORA-W306. Solder a 1x2 breakaway male header to the board. Then connect it to a multimeter to measure the current consumption. Using a LiPo battery will bring down the current consumption since the LiPo battery charger, CHG LED, and CP2102 USB-to-serial converter are not being powered. Try disabling the power LED jumpers on the NORA-W306 and BME280. You can take it a step further by also disabling power to the WS2812 by cutting the JP3 jumper.

<div style="text-align: center;">
  <table>
    <tr style="vertical-align:middle;">
     <td style="text-align: center; vertical-align: middle; border: solid 1px #cccccc;"><a href="../assets/img/NORA-W306_Low_Power_Deep_Sleep_microSD_BME280_Multimeter_PTH_no_battery_bb.jpg">Fritzing Diagram Multimeter Connected to NORA-W306's MESA Jumper, no battery</a></td>
     <td style="text-align: center; vertical-align: middle; border: solid 1px #cccccc;"><a href="../assets/img/NORA-W306_Low_Power_Deep_Sleep_microSD_BME280_Multimeter_PTH_bb.jpg">Fritzing Diagram Multimeter Connected to NORA-W306's MESA Jumper</a></td>
    </tr>
    <tr style="vertical-align:middle;">
     <td style="text-align: center; vertical-align: middle; border: solid 1px #cccccc;" colspan="2"><i>Fritzing Diagrams with Multimeter Connected to NORA-W306's MEAS Jumper</i></td>
    </tr>
  </table>
</div>

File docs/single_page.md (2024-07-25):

---
hide:
  - navigation
  - toc
icon: fontawesome/solid/scroll
---

# Introduction
--8<-- "./docs/introduction.md"

# Hardware Overview
--8<-- "./docs/hardware_overview.md"

# Hardware Hookup
--8<-- "./docs/hardware_hookup.md"

# Installing the CP2102 USB Driver
--8<-- "./docs/installing_drivers.md"

# Setting Up Arduino
--8<-- "./docs/setting_up_arduino.md"

# Installing the Arduino Library
--8<-- "./docs/arduino_library.md"

# Arduino

# Example 1 - Blink
--8<-- "./docs/arduino_example_1_blink.md"

# Example 2: Button
--8<-- "./docs/arduino_example_2_button.md

# Example 3 - Scanning WiFi Networks
--8<-- "./docs/arduino_example_3_scan_wifi.md"

# Example 4 - Connecting to a WiFi Network
--8<-- "./docs/arduino_example_4_connect_wifi.md"

# Example 5a - Bluetooth UART Service
--8<-- "./docs/arduino_example_5a_bluetooth_uart_service.md"

# Example 5b - Bluetooth UART Client
--8<-- "./docs/arduino_example_5b_bluetooth_uart_client.md"

# Example 6 - MicroSD Card
--8<-- "./docs/arduino_example_6_microsd.md"

# Example 7 - Deep Sleep and Blink
--8<-- "./docs/arduino_example_7_deep_sleep_blink.md"

# Example 8 - Deep Sleep and MicroSD Power Control
--8<-- "./docs/arduino_example_8_deep_sleep_temperature_datalogging_BME280.md"

# Example 9 - MAX17048 LiPo Fuel Gauge
--8<-- "./docs/arduino_example_9_lipo_fuel_gauge.md"

# Example 10 - WS2812 Addressable RGB LED
--8<-- "./docs/arduino_example_10_ws2812.md"

# Example 11 - Qwiic Micro OLED
--8<-- "./docs/arduino_example_11_qwiic_micro_oled.md"

# Example 12 - LiPo Fuel Gauge (MAX17048) with Micro OLED Display Demo
--8<-- "./docs/arduino_example_12_lipo_fuel_gauge_micro_oled_ws2812.md"

# More Examples!!!
--8<-- "./docs/more_examples.md"

# Troubleshooting
--8<-- "./docs/troubleshooting.md"

# Resources
--8<-- "./docs/resources.md"

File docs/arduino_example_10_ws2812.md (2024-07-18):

In this example, we will blink the WS2812.

### Hardware Hookup

The connection is the same as explained earlier in the tutorial. Connect the USB cable to the SparkFun Thing Plus NORA-W306 and the other end to your computer. For the scope of this tutorial, we will be using the built-in WS2812B on the development board.

For those that are interested in connecting additional WS2812, you can follow the table below to daisy chain additional LEDs. This configuration is when users are using USB for power and daisy chaining a small number of WS2812's.

<div style="text-align: center;">
    <table>
        <tr>
            <th style="text-align: center; border: solid 1px #cccccc;">NORA-W306<br />Pinout
            </th>
            <th style="text-align: center; border: solid 1px #cccccc;">WS2812 LED<br />Pinout
            </th>
        </tr>
        <tr>
            <td style="text-align: center; border: solid 1px #cccccc;" bgcolor="#f2dede"><font color="#000000">VUSB (if powering off USB<br />and low number of WS2812 LEDs)</font>
            <td style="text-align: center; border: solid 1px #cccccc;" bgcolor="#f2dede"><font color="#000000">VIN</font>
            </td>
        </tr>
        <tr>
            <td style="text-align: center; border: solid 1px #cccccc;" bgcolor="#d4edda"><font color="#000000">LD/LED_D0</font>
            </td>
            <td style="text-align: center; border: solid 1px #cccccc;" bgcolor="#d4edda"><font color="#000000">DI</font>
            </td>
        </tr>
        <tr>
            <td style="text-align: center; border: solid 1px #cccccc;" bgcolor="#fff3cd"><font color="#000000">GND</font>
            </td>
            <td style="text-align: center; border: solid 1px #cccccc;" bgcolor="#fff3cd"><font color="#000000">GND</font>
            </td>
        </tr>
    </table>
</div>

For large number of LEDs, you may want to considering using an [external power supply to power the strip of addressable LEDs](https://learn.sparkfun.com/tutorials/mean-well-led-switching-power-supply-hookup-guide#daisychain).
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

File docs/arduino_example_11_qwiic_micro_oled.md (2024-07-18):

In this example, we will connect a Qwiic-enabled Micro OLED display.

### Hardware Hookup

To connect the Qwiic Micro OLED, simply insert a Qwiic cable between the display and the SparkFun Thing Plus NORA-W306.

<div style="text-align: center;">
  <table>
    <tr style="vertical-align:middle;">
     <td style="text-align: center; vertical-align: middle; border: solid 1px #cccccc;"><a href="../assets/img/WRL-21637_Thing_Plus_NORA-W306_Qwiic_Enabled_Device_OLED.jpg">Qwiic Micro OLED Connected to SparkFun Thing Plus NORA-W306</a></td>
    </tr>
    <tr style="vertical-align:middle;">
     <td style="text-align: center; vertical-align: middle; border: solid 1px #cccccc;"><i>Qwiic Micro OLED Connected to SparkFun Thing Plus NORA-W306</i></td>
    </tr>
  </table>
</div>

When ready, connect the board to your computer with the USB C cable.

### Installing the Arduino Library

!!! note
    There are two SparkFun Arduino Libraries for the Qwiic micro OLED. We recommend using the SparkFun Qwiic OLED Arduino Library.

If you have not already, make sure to install the following libraries as explained earlier.

* [Qwiic OLED](https://github.com/sparkfun/SparkFun_Qwiic_OLED_Arduino_Library)
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

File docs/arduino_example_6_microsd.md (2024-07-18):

In this example, we will write some text to a microSD card and read the contents of the text file for verification.

### Hardware Hookup

Make sure to insert a microSD card into the microSD card socket on the back of the board.

<div style="text-align: center;">
  <table>
    <tr style="vertical-align:middle;">
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

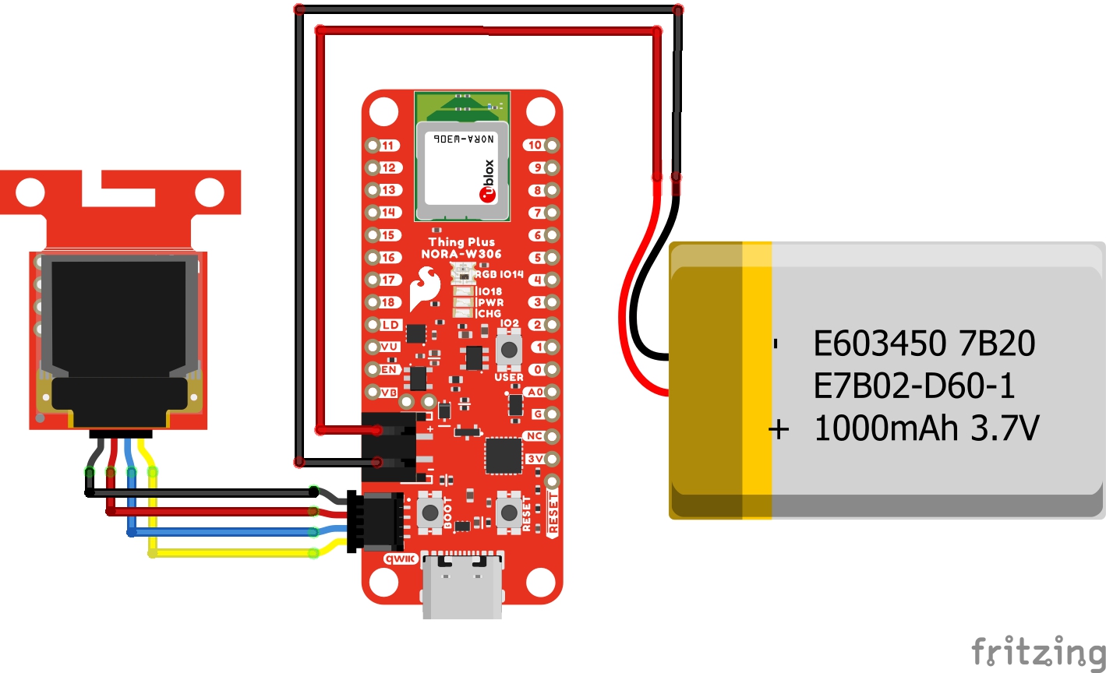
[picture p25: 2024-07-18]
docs/assets/img/NORA-W306_MAX17048_Fuel_Gauge_WS2812_LiPo_Battery_Demo_bb.jpg

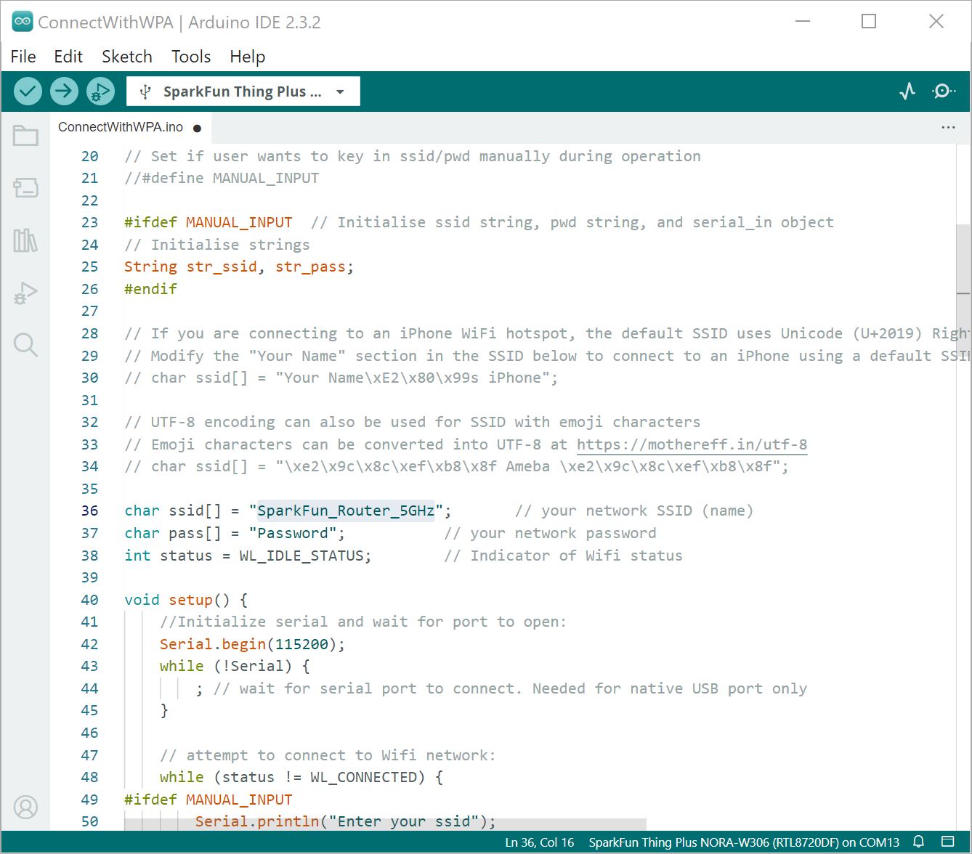
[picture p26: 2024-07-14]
docs/assets/img/AmebaD_RealTek_NORA-W306_Arduino_Connect_to_WPA_Rename_SSID_to_5GHz_Network.JPG

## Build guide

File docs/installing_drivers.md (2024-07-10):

!!! warning
    Make sure to manually install the driver for the CP2102N with the following instructions. The driver that Windows auto-installs will not work with the auto-reset circuit on the board and can cause serial uploads to fail.

You will also need to install the SiLabs CP210X Driver, which can be found here: [USB to UART Bridge VCP Driver](https://www.silabs.com/products/development-tools/software/usb-to-uart-bridge-vcp-drivers).

<div style="text-align: center">
    <a href="https://cdn.sparkfun.com/assets/learn_tutorials/8/5/2/CP210x_Universal_Windows_Driver.zip" class="md-button">Windows VCP Driver (ZIP)</a>
    <br />
    <br />
    <a href="https://www.silabs.com/documents/public/software/Mac_OSX_VCP_Driver.zip" class="md-button md-button--primary">Mac OSX VCP Driver (ZIP)</a>
</div>

!!! note
    If applicable, make sure you are using the proper driver files for your CPU architecture. This is usually indicated by a folder or file name with "x86" for 32-bit processors or "x64" for 64-bit processors.

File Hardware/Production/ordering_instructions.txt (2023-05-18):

panel size, 107x201mm
PCB thickness, 1.6mm
number of layers, 4
controlled impedance, JLC7628
material, TG155
soldermask color, Red
silkscreen color, White
oz copper, 1oz
finish, HASL lead free
stencils, top+bottom
pcs per panel, 12
min trace width, 0.1778mm / 0.0070in
min drill size, 0.2000mm / 0.0079in
filename to layer stackup 1/2/3/4: GTL, GL2, GL3, GBL

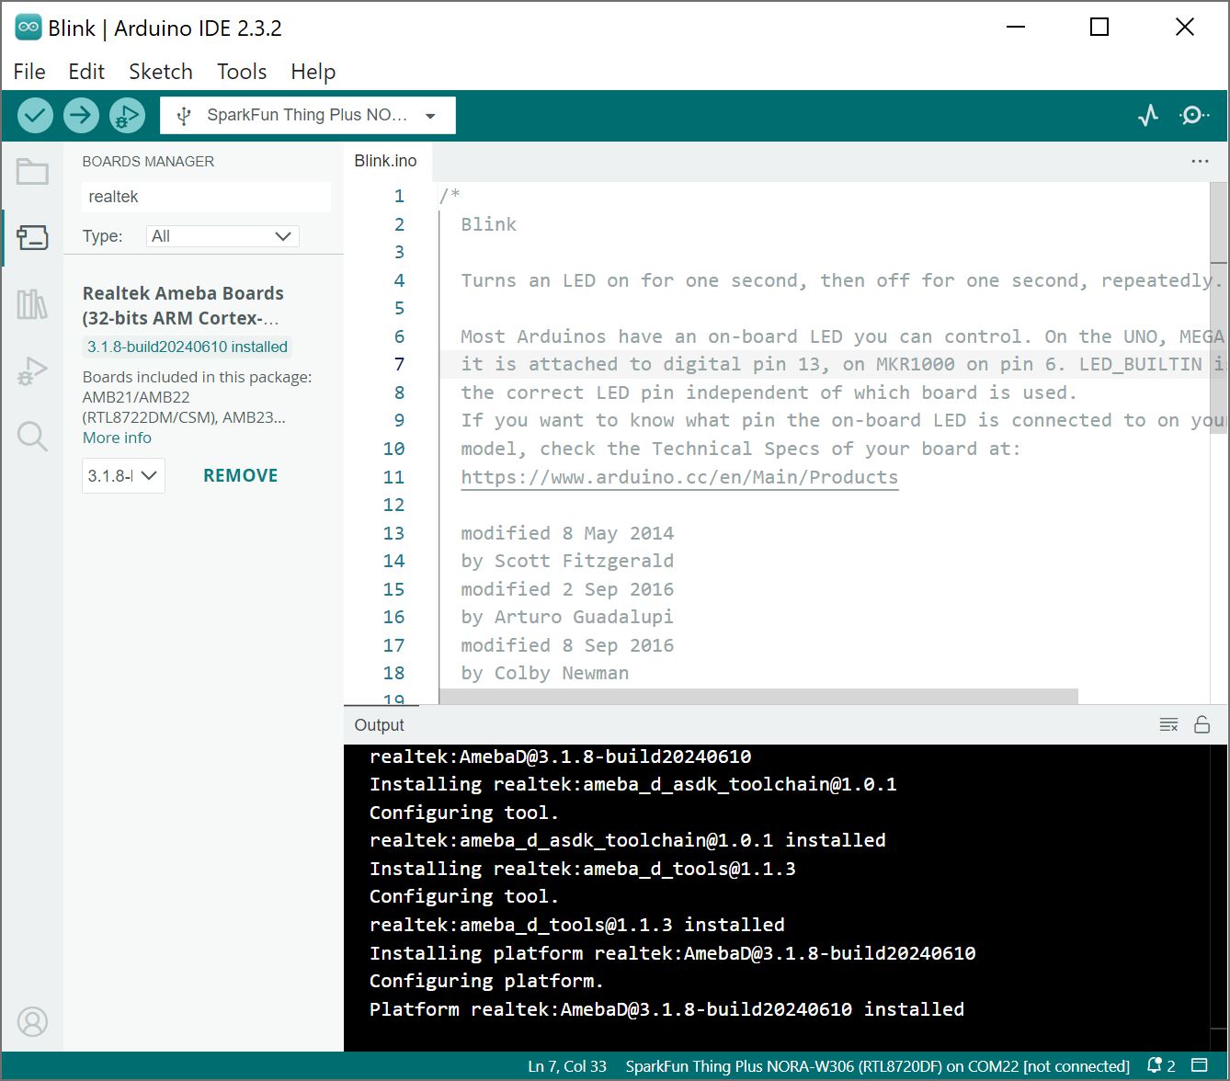
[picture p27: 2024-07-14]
docs/assets/img/NORA-W306_installed_Arduino_Board_Manager-EARLY_RELEASE.JPG

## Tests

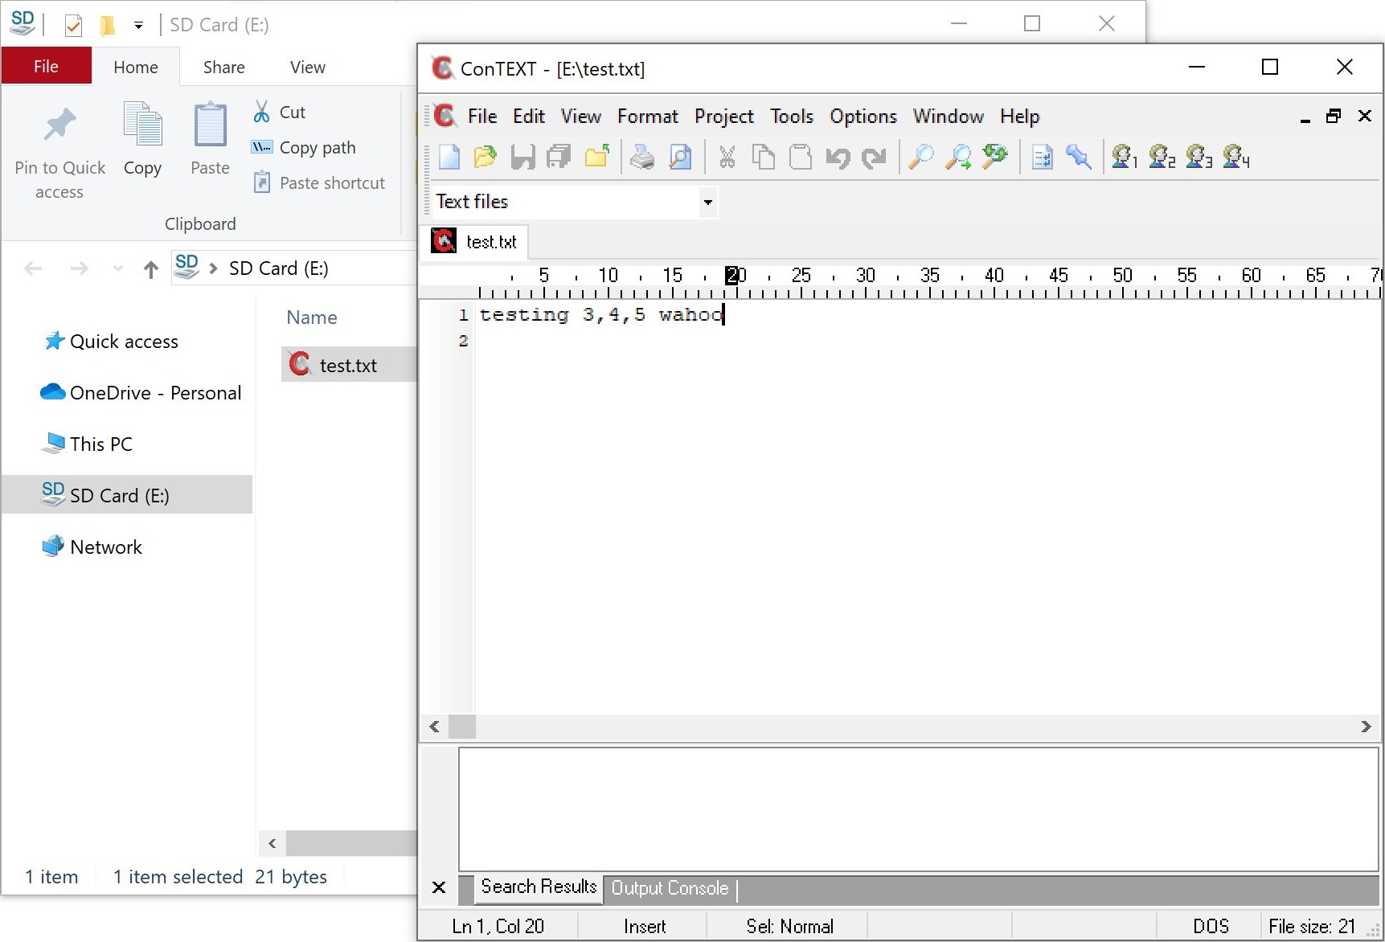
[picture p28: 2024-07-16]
docs/assets/img/File_Explorer_Text_Editor_Verification.JPG

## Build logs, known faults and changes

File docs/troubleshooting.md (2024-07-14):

### General Troubleshooting Help

!!! note
    <span class="glyphicon glyphicon-question-sign" aria-hidden="true"></span>
        <strong> Not working as expected and need help? </strong> <br /><br />

    If you need technical assistance and more information on a product that is not working as you expected, we recommend heading on over to the <a href="https://www.sparkfun.com/technical_assistance">SparkFun Technical Assistance</a> page for some initial troubleshooting. <br /><br />

    <div style="text-align: center"><a href="https://www.sparkfun.com/technical_assistance" target="sfe_technical_assistance" class="md-button">SparkFun Technical Assistance Page</a></div>

    If you don't find what you need there, the <a href="https://community.sparkfun.com/">SparkFun Forums</a> are a great place to find and ask for help. If this is your first visit, you'll need to create a forum account to search product forums and post questions.<br /><br />

    <div style="text-align: center"><a href="https://community.sparkfun.com/" class="md-button md-button--primary">Log Into SparkFun Forums</a></div>

### Manual Upload Mode

Having problems uploading code with the auto upload mode? You may see this in the output window indicating there was an error uploading.

``` bash
Please enter the upload mode manually(wait 5s)
    05
    04
    03
    02
    01
Uploading.....error: Enter Uart Download Mode

    Upload Image done.
```

If you have problems uploading code when Auto Upload Mode is enabled, try uploading code manually. From the menu, select the following: **Tools** > **Auto Upload Mode:** > **Enable**. Hit the upload button in the Arduino IDE. In the debug window, you should see something similar. As the Arduino IDE starts outputting the numbers.

``` bash
Please enter the upload mode manually(wait 5s)
    05
    04
    03
    02
    01
```

Press down on the BOOT button. While holding down the BOOT button, press the RESET Button momentarily. Keep holding the BOOT button for a moment before lifting your finger off the button.

<div style="text-align: center;">
<table>
  <tr align="center">
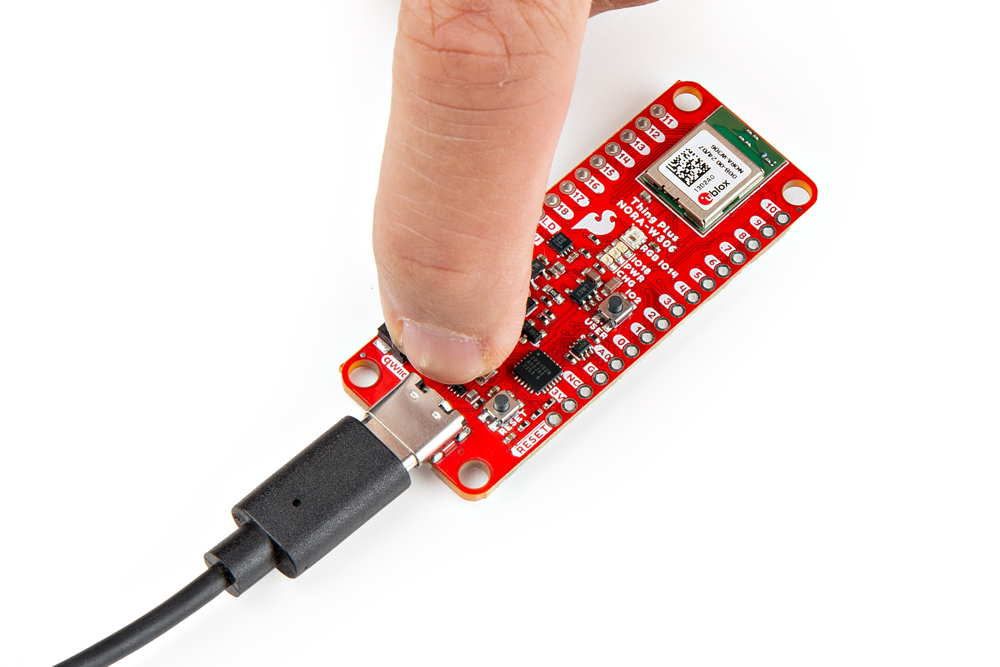
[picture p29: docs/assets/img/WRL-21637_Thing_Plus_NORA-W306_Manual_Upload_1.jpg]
Manual Upload Sequence (Boot)
   <td style="text-align: center; vertical-align: middle; border: solid 1px #cccccc;"></td>
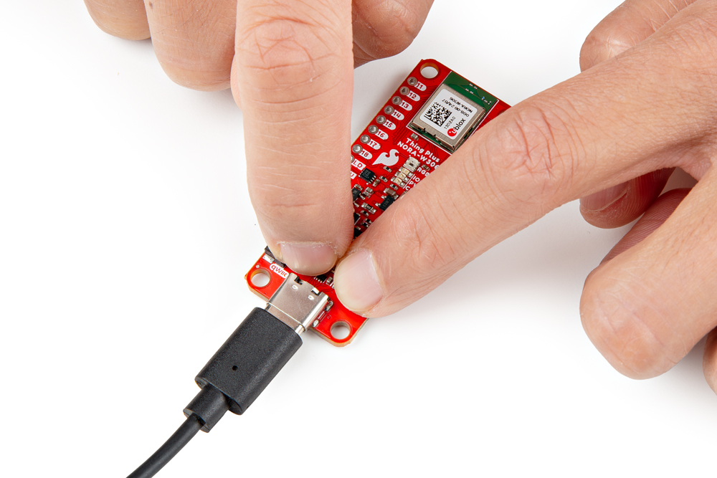
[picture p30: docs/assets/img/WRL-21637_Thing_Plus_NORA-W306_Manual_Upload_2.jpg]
Manual Upload Sequence (Boot + Reset)
   <td style="text-align: center; vertical-align: middle; border: solid 1px #cccccc;"></td>
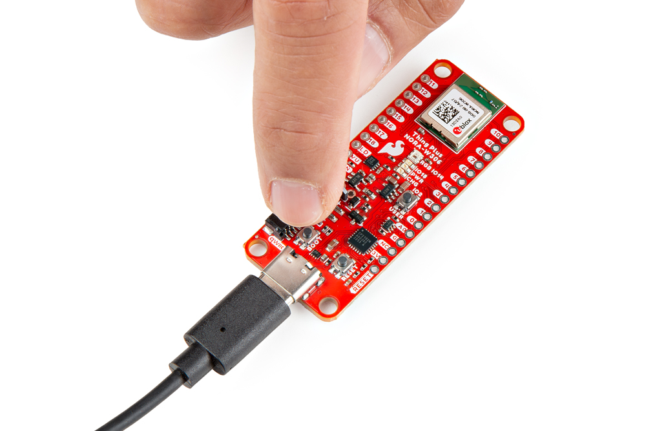
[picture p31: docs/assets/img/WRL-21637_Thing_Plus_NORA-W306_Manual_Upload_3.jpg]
Manual Upload Sequence (Boot)
   <td style="text-align: center; vertical-align: middle; border: solid 1px #cccccc;"></td>
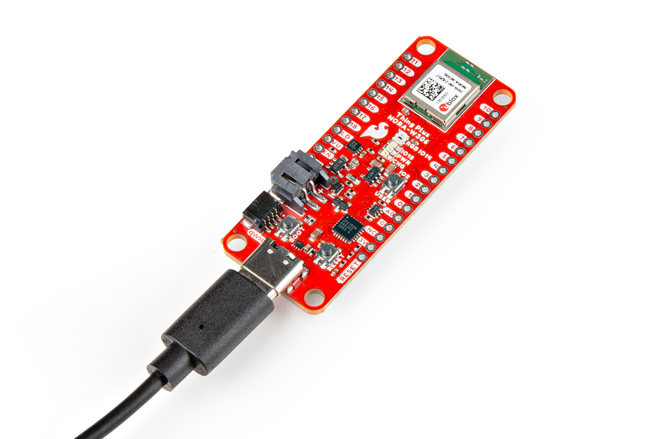
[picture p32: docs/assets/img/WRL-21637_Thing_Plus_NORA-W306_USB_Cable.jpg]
Manual Upload Sequence Release
   <td style="text-align: center; vertical-align: middle; border: solid 1px #cccccc;"></td>
  </tr>
  <tr align="center">
   <td style="text-align: center; vertical-align: middle; border: solid 1px #cccccc;"><i>BOOT Button</i></td>
   <td style="text-align: center; vertical-align: middle; border: solid 1px #cccccc;"><i>BOOT and RESET</i></td>
   <td style="text-align: center; vertical-align: middle; border: solid 1px #cccccc;"><i>Keep Holding Down BOOT</i></td>
   <td style="text-align: center; vertical-align: middle; border: solid 1px #cccccc;"><i>Release BOOT</i></td>
  </tr>
</table>
</div>

If all goes well, you should have a successful upload with the following message.

``` bash
Please enter the upload mode manually(wait 5s)
    05
    04
    03
    02
    01
Uploading..................
    Upload Image done.
All images are sent successfully!
```

<div style="text-align: center;">
  <table>
    <tr style="vertical-align:middle;">
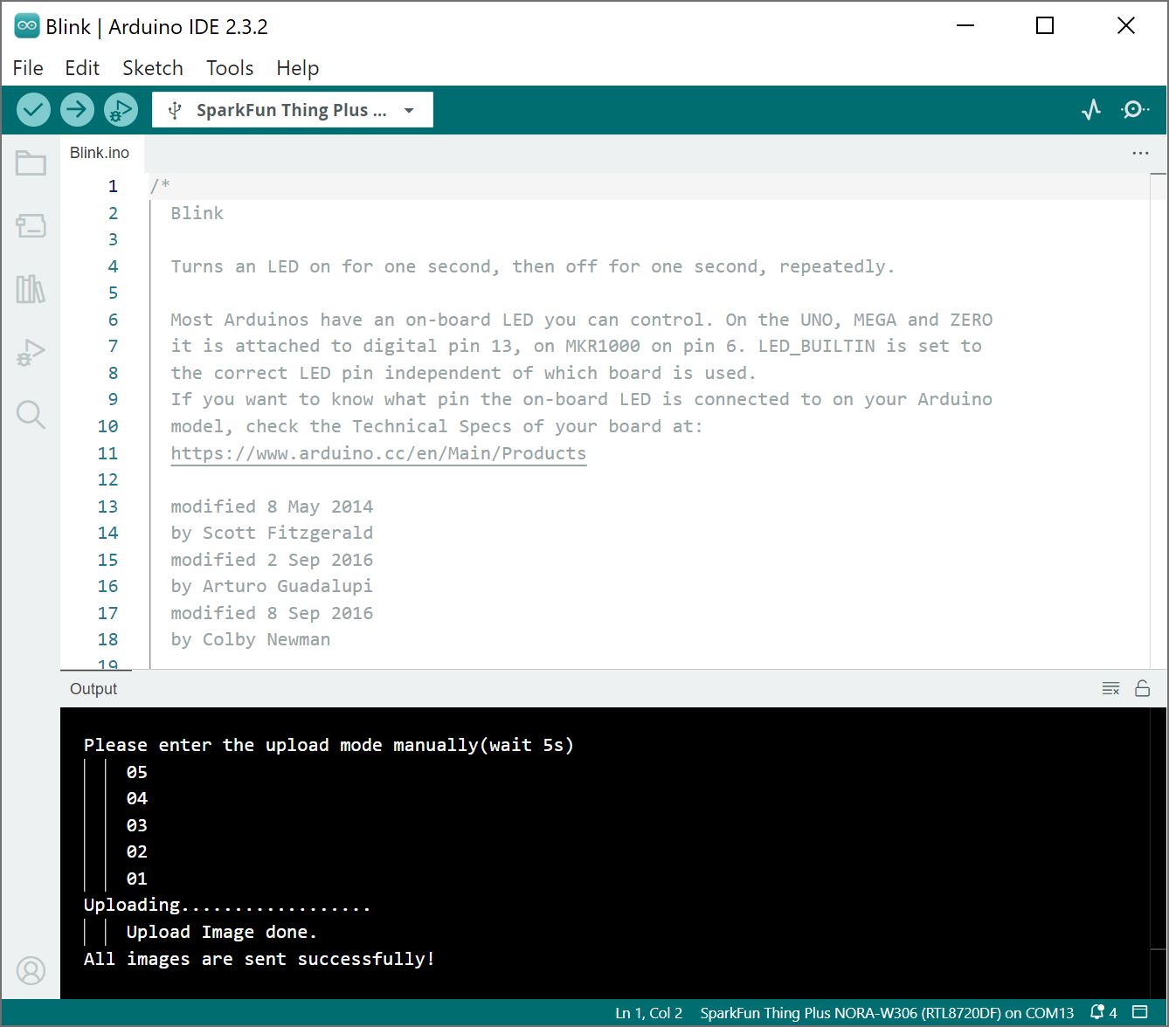
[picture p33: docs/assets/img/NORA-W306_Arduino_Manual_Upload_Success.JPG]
NORA-W306 Arduino Manual Upload Success
     <td style="text-align: center; vertical-align: middle; border: solid 1px #cccccc;"></td>
    </tr>
    <tr style="vertical-align:middle;">
     <td style="text-align: center; vertical-align: middle; border: solid 1px #cccccc;"><i>NORA-W306 Arduino Manual Upload Success</i></td>
   </tr>
  </table>
</div>

To execute the code, hit the reset button or power cycle the board!

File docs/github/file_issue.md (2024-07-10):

# Did we make a mistake?

Spot something wrong? Please let us know. 

!!! attention
    This is not where customers should seek assistance on a product. If you require technical assistance or have questions about a product that is not working as expected, please head over to the [SparkFun Technical Assistance](https://www.sparkfun.com/technical_assistance) page for some initial troubleshooting.
    <center>
    [SparkFun Technical Assistance Page](https://www.sparkfun.com/technical_assistance){ .md-button .md-button--primary }
    </center>

    If you can't find what you need there, you'll need a [Forum Account](https://forum.sparkfun.com/ucp.php?mode=register) to search product forums and post questions.

## Discrepancies in the Documentation

All of this documentation can be modified by you! Please help us make it better.

* The documentation files for these pages are contained in the [`docs` folder of the SparkFun Thing Plus NORA-W306 repository](https://github.com/sparkfun/SparkFun_Thing_Plus_NORA-W306/tree/main/docs).

### Spot something wrong?
If a section of the documentation is incorrect, please [open an issue](https://github.com/sparkfun/SparkFun_Thing_Plus_NORA-W306/issues) and let us know.

### Do you have a suggested correction?
1. With a GitHub account, fork this repo
2. Add your correction(s) or improvement(s) to the markdown file(s)
3. File a pull request with your changes, and enjoy making the ~~words~~ ~~worlds~~ world a better place.
    * Once received, the documentation specialist will automatically be notified.
    * We will review your suggested improvement(s) to make sure they are correct and fit within our documentation standards.

## Problems in the Hardware Design

All of our designs are open-source! Please help us make it better.

* Our board design files are contained in the [`Hardware` folder of the SparkFun Thing Plus NORA-W306 repository](https://github.com/sparkfun/SparkFun_Thing_Plus_NORA-W306/tree/main/Hardware).

### Does something not make sense?
If part of the design is confusing, please [open an issue](https://github.com/sparkfun/SparkFun_Thing_Plus_NORA-W306/issues) and let us know.

### Did we forget to include an important function of the board?
* Please keep in mind that we may intentionally exclude certain functions of the board to meet our product design requirements. *(For example, our Qwiic Micro boards are intended to fit on a small board layout and only use I<sup>2</sup>C communication; therefore, we may not have the SPI and interrupt pins available for users.)*
* If part of the board's functionality is missing, please [open an issue](https://github.com/sparkfun/SparkFun_Thing_Plus_NORA-W306/issues) and file a feature request.

### Do you wish to contribute directly to improving the board design?
1. With a GitHub account, Fork this repo
2. Add your design improvement(s)
3. File a pull request with your changes, and enjoy making the ~~words~~ ~~worlds~~ world a better place.
    * Once received, the engineer in charge of the original design will automatically be notified.
    * We will review your suggested improvement(s), if they are within our board design standards and meet our product design requirements, we will flag these changes for our next board revision. *(Please note, that even if your suggestion is accepted, these changes may not be immediate. We may have to cycle through our current product inventory first.)*

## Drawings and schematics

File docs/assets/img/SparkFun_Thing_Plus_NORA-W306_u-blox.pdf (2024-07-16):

# WRL-21637

# SparkFun Thing Plus (NORA-W306)

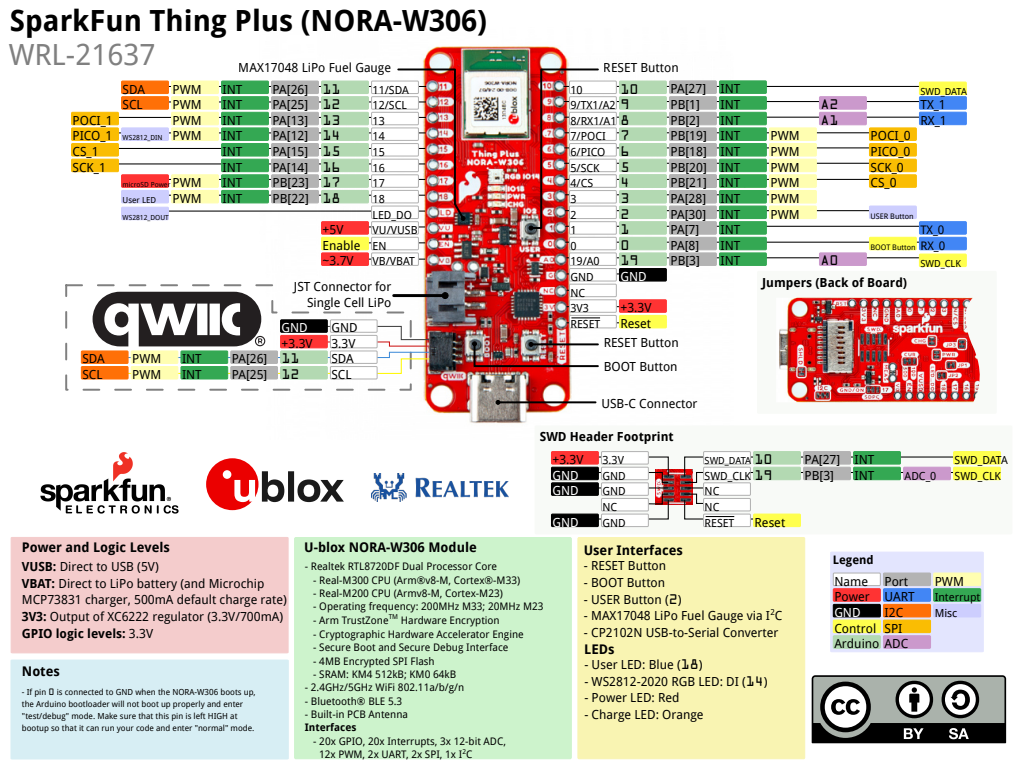
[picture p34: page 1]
INT; ADC_0; SWD_DATA 10; SWD_CLK 19; RESET; Reset; SWD_CLK; SWD_DATA; GND; Notes; 8-bit; 7/POCI 7; PB[19] INT; PWM; POCI_0; 6/PICO 6; PB[18] INT; PICO_0; 5/SCK; PB[20] INT; PB[21] INT; PA[30] INT; BOOT Button; PA[27] INT; PA[28] INT; USER Button; SCK_0; 11/SDA; 12/SCL; WS2812_DOUT; LED_DO; VU/VUSB; VB/VBAT; microSD Power User LED; SDA SCL; WS2812_DIN; POCI_1 PICO_1; SCK_1; SDA; SCL; Legend; Name Port; Power UART; Interrupt; Misc; Control SPI Arduino ADC; RESET Button; USB-C Connector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

Enable EN
JST Connector for
Single Cell LiPo

Jumpers (Back of Board)

SWD Header Footprint

User Interfaces
- RESET Button
- BOOT Button
- USER Button (2)
- MAX17048 LiPo Fuel Gauge via I²
- CP2102N USB-to-Serial Converter
LEDs
- User LED: Blue (18)
- WS2812-2020 RGB LED: DI (14)
- Power LED: Red
- Charge LED: Orange

Power and Logic Levels
VUSB: Direct to USB (5V)
VBAT: Direct to LiPo battery (and Microchip
MCP73831 charger, 500mA default charge rate)
3V3: Output of XC6222 regulator (3.3V/700mA)
GPIO logic levels: 3.3V

U-blox NORA-W306 Module
- Realtek RTL8720DF Dual Processor Core
- Real-M300 CPU (Arm®v8-M, Cortex®-M33)
- Real-M200 CPU (Armv8-M, Cortex-M23)
- Operating frequency: 200MHz M33; 20MHz M23
- Arm TrustZoneTM Hardware Encryption
- Cryptographic Hardware Accelerator Engine
- Secure Boot and Secure Debug Interface
- 4MB Encrypted SPI Flash
- SRAM: KM4 512kB; KM0 64kB
- 2.4GHz/5GHz WiFi 802.11a/b/g/n
- Bluetooth® BLE 5.3
- Built-in PCB Antenna
Interfaces
- 20x GPIO, 20x Interrupts, 3x 12-bit ADC,
12x PWM, 2x UART, 2x SPI, 1x I²

- If pin 0 is connected to GND when the NORA-W306 boots up,
the Arduino bootloader will not boot up properly and enter
"test/debug" mode. Make sure that this pin is left HIGH at
bootup so that it can run your code and enter "normal" mode.

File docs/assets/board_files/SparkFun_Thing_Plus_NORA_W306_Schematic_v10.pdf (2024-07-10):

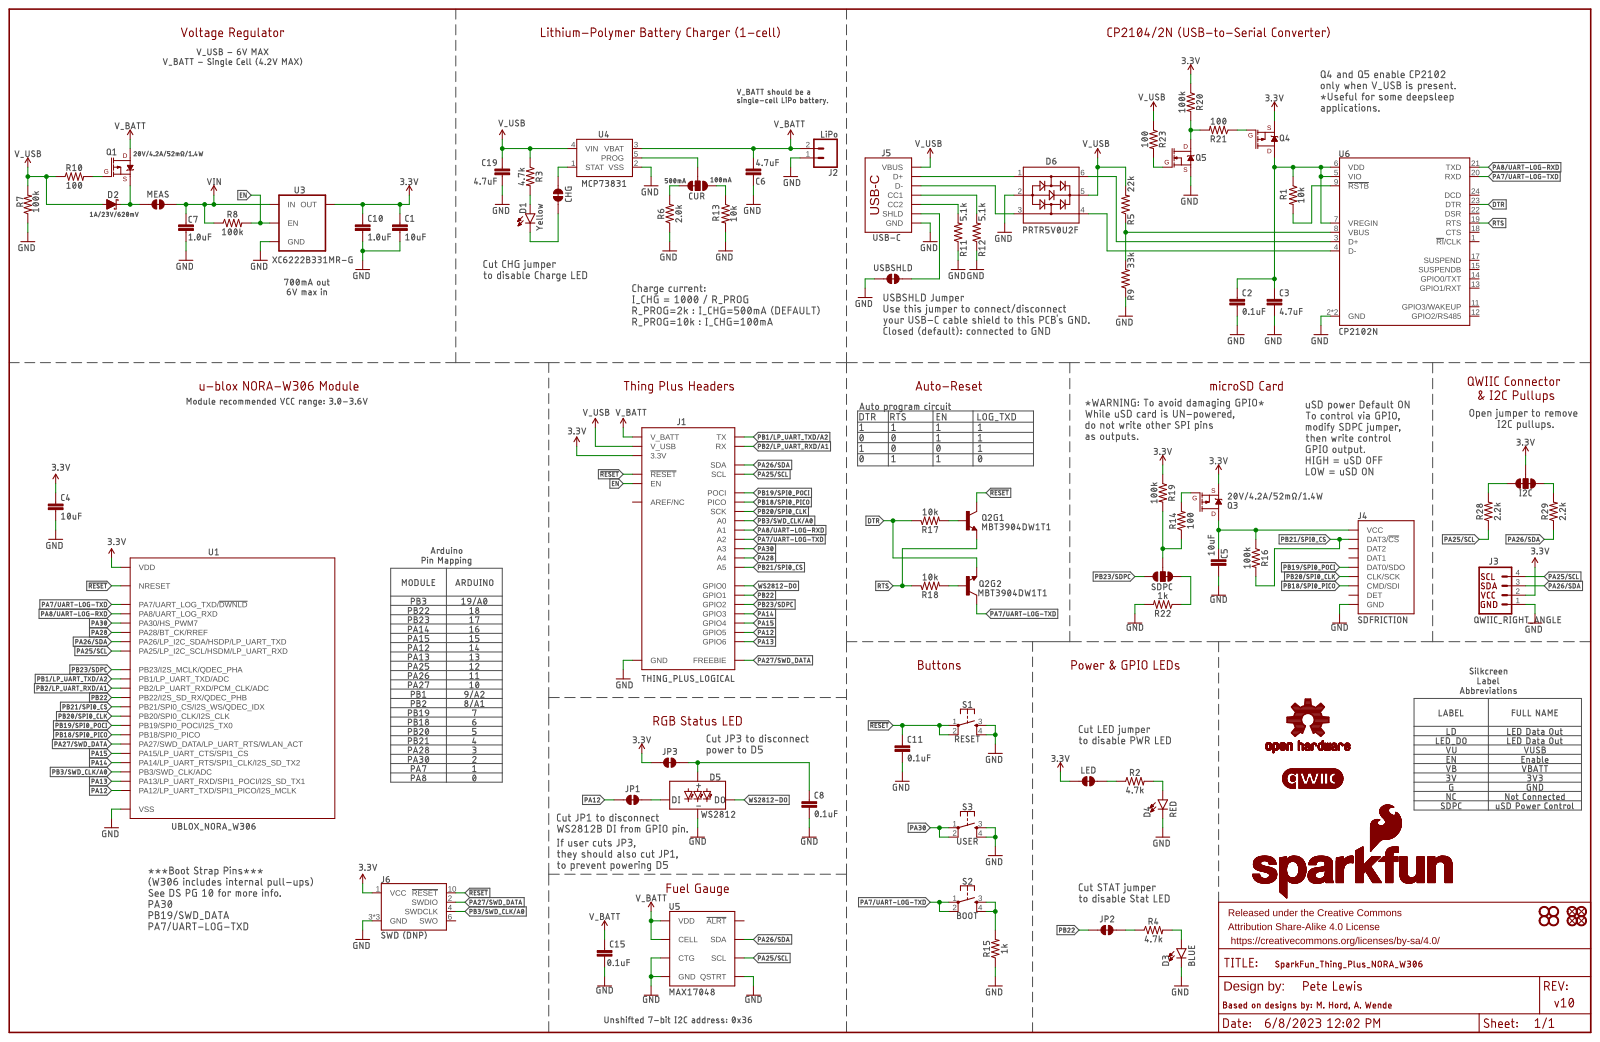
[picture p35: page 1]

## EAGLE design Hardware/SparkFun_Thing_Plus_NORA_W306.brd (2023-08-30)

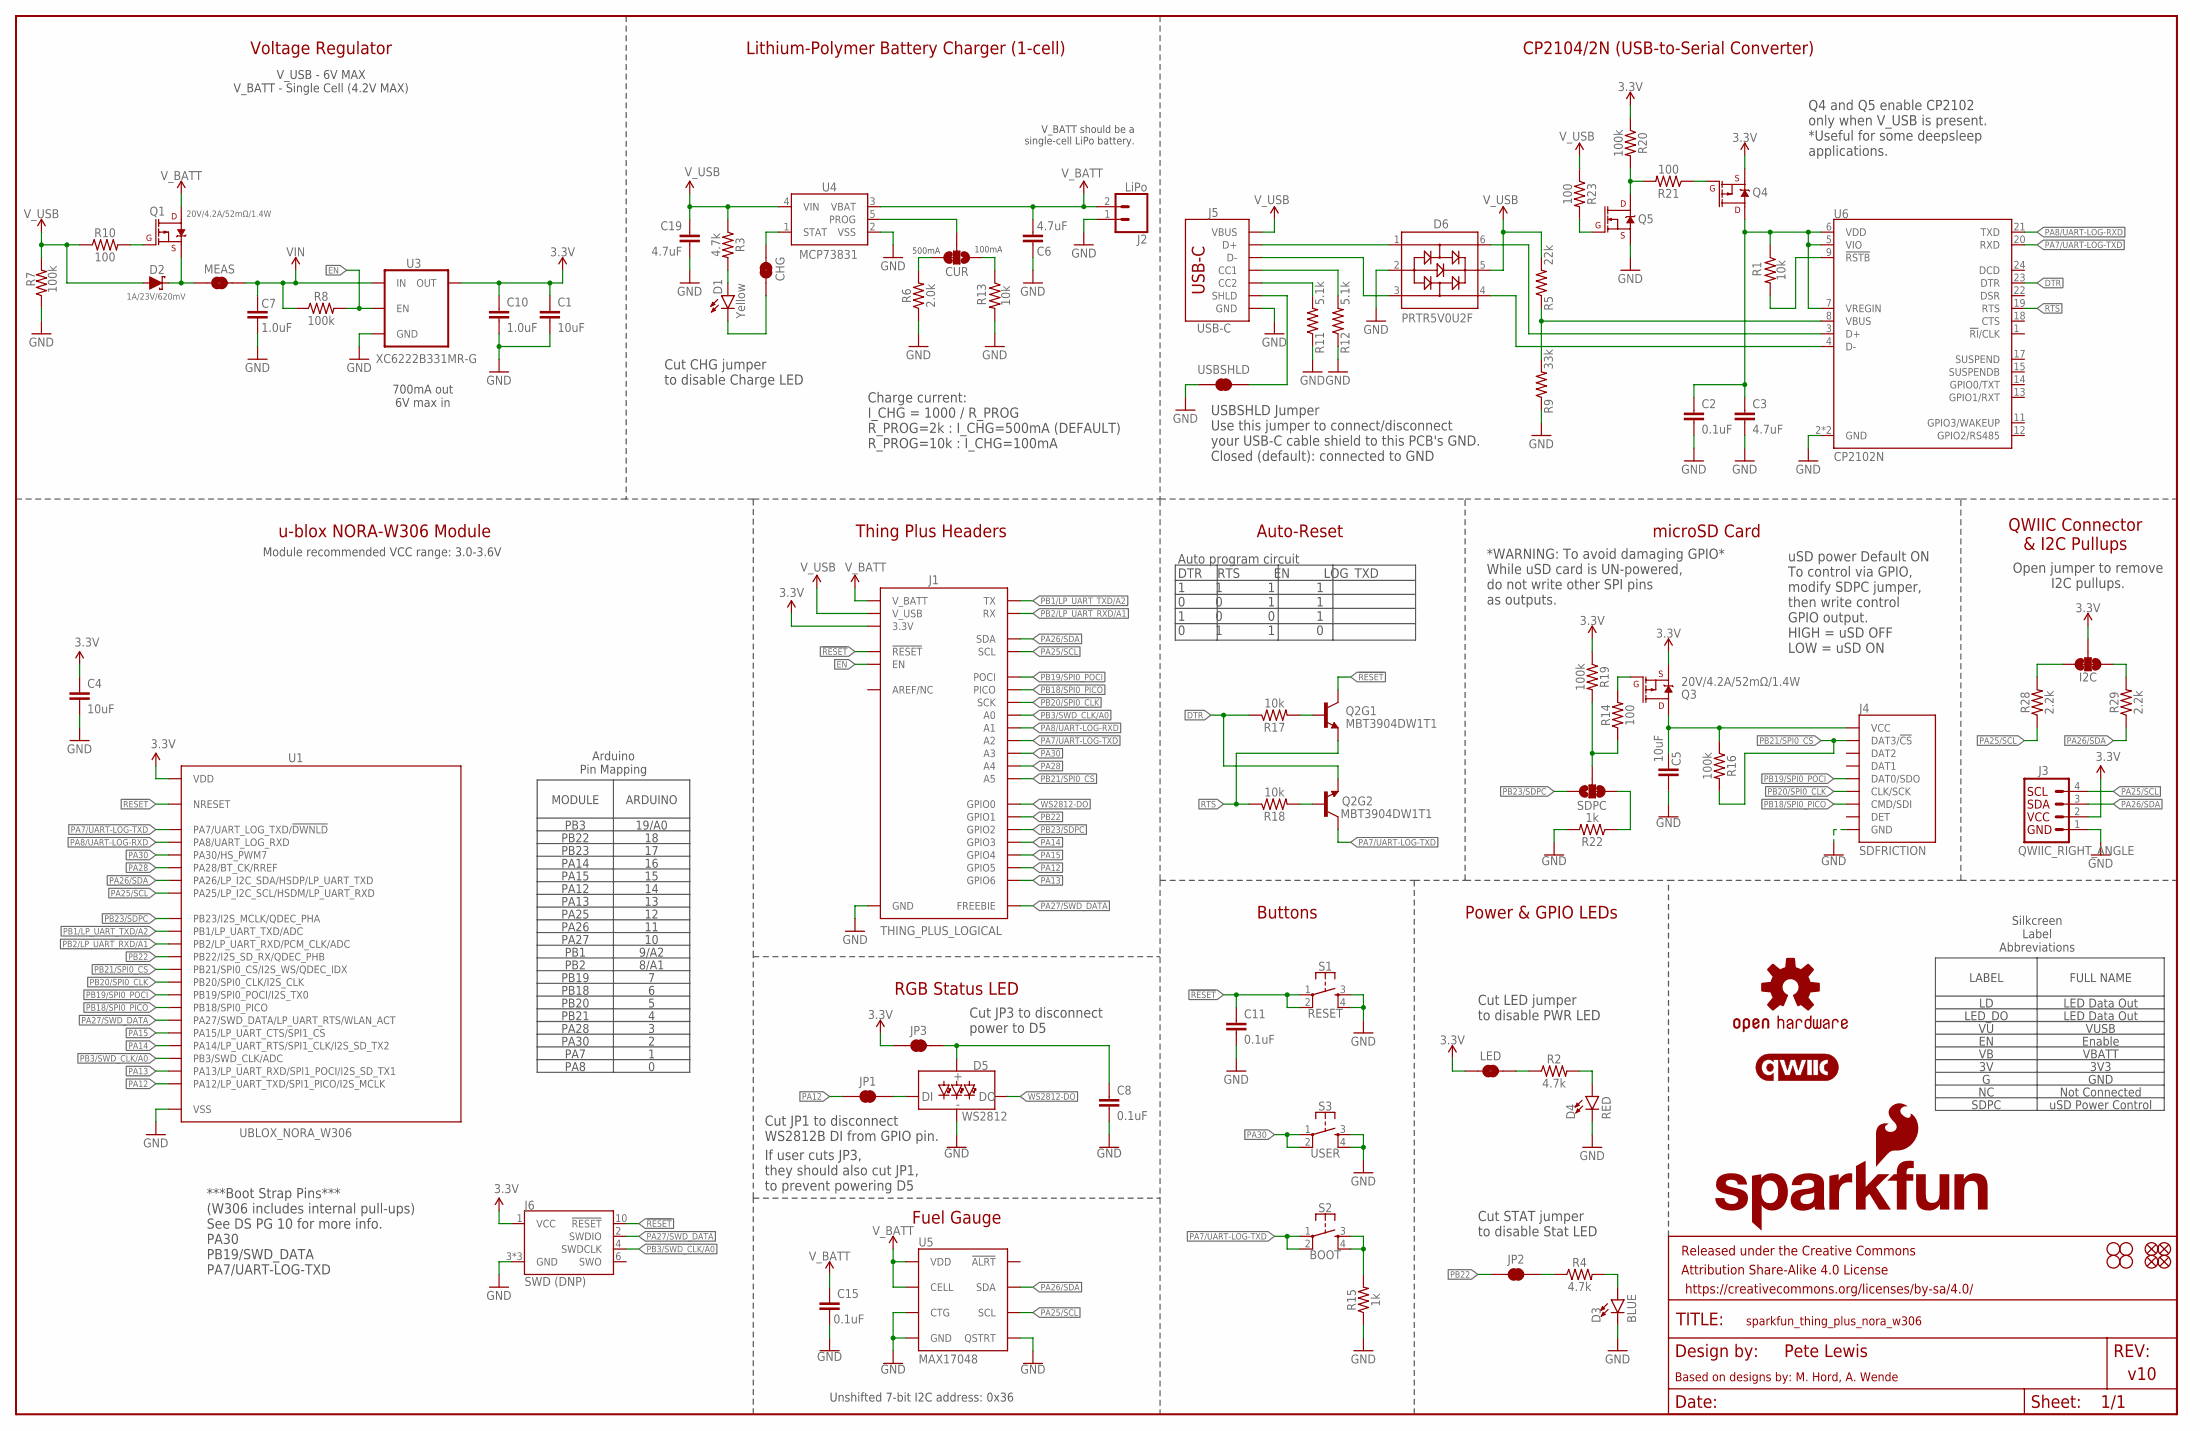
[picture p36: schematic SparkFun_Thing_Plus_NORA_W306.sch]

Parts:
C1, C4, C5: 10uF; 0402-TIGHT
C2, C8, C11, C15: 0.1uF; 0402-TIGHT
C3, C6, C19: 4.7uF; 0603
C7, C10: 1.0uF; 0402-TIGHT
CHG: JUMPER-SMT_2_NC_TRACE_SILK; SMT-JUMPER_2_NC_TRACE_SILK
CUR: JUMPER-SMT_3_1-NC_TRACE_SILK; SMT-JUMPER_3_1-NC_TRACE_SILK
D1: Yellow; LED-0603
D2: 1A/23V/620mV; SOD-323
D3: BLUE; LED-0603
D4: RED; LED-0603
D5: WS2812; WS2812-2020
D6: PRTR5V0U2F; SOT886
FD1, FD2, FD3, FD4: FIDUCIALUFIDUCIAL; FIDUCIAL-MICRO
FRAME1: FRAME-LEDGER; CREATIVE_COMMONS
H1, H2, H3, H4: STAND-OFF
I2C: JUMPER-SMT_3_2-NC_TRACE_SILK; SMT-JUMPER_3_2-NC_TRACE_SILK
J1: THING_PLUS_LOGICAL; THING_PLUS
J2: LiPo; JST-2-SMD
J3: QWIIC_RIGHT_ANGLE; JST04_1MM_RA
J4: SDFRICTION; MICROSD_TINY
J5: USB-C; USB-C-16P-4LAYER-ISOLATED
J6: SWD (DNP); 2X5-SMD-UNSHROUDED_DNP_NO_PASTE
JP1, JP2, JP3: JUMPER-SMT_2_NC_TRACE_SILK; SMT-JUMPER_2_NC_TRACE_SILK
LED: JUMPER-SMT_2_NC_TRACE_SILK; SMT-JUMPER_2_NC_TRACE_SILK
LOGO2: OSHW-LOGOM; OSHW-LOGO-M
LOGO3: SFE_LOGO_NAME_FLAME.1_INCH; SFE_LOGO_NAME_FLAME_.1
LOGO6: QWIIC_LOGO_4MM; QWIIC_4MM
MEAS: JUMPER-COMBO_2_NC_TRACE; COMBO-JUMPER_2_NC_TRACE
Q1, Q3, Q4: 20V/4.2A/52mΩ/1.4W; SOT23-3
Q2: MBT3904DW1T1; SC70-6
Q5: 20V/0.2A/8MHz/1.2Ω/1Vth; SOT-416FL
R1, R13, R17, R18: 10k; 0402-TIGHT
R2, R3, R4: 4.7k; 0402-TIGHT
R5: 22k; 0402-TIGHT
R6: 2.0k; 0603
R7, R8, R16, R19, R20: 100k; 0402-TIGHT
R9: 33k; 0402-TIGHT
R10, R14, R21, R23: 100; 0402-TIGHT
R11, R12: 5.1k; 0402-TIGHT
R15, R22: 1k; 0402-TIGHT
R28, R29: 2.2k; 0402-TIGHT
S1: RESET; TACTILE_SWITCH_SMD_4.6X2.8MM
S2: BOOT; TACTILE_SWITCH_SMD_4.6X2.8MM
S3: USER; TACTILE_SWITCH_SMD_4.6X2.8MM
SDPC: JUMPER-SMT_3_1-NC_TRACE_SILK; SMT-JUMPER_3_1-NC_TRACE_SILK
U1: UBLOX_NORA_W306; UBLOX-NORA-W3
U3: XC6222B331MR-G; SOT23-5
U4: MCP73831; SOT23-5
U5: MAX17048; DFN-8
U6: CP2102N; QFN24
USBSHLD: JUMPER-SMT_2_NC_TRACE_SILK; SMT-JUMPER_2_NC_TRACE_SILK

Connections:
3.3V: C1.1, C4.1, C10.1, I2C.2, J1.27 (3.3V), J3.2, J6.1 (VCC), JP3.1, LED.1, Q3.2 (S), Q4.2 (S), R19.1, R20.1, U1.A7 (VDD), U1.A8 (VDD), U1.B7 (VDD), U3.5 (OUT)
!RESET!: C11.1, J1.28 (!RESET), J6.10 (!RESET), Q2.3 (C), S1.1, S1.2, U1.J3 (NRESET)
CC1: J5.A5 (CC1), R12.2
CC2: J5.B5 (CC2), R11.2
CHG: CHG.2, U4.1 (STAT)
DTR: Q2.1 (E), R17.1, U6.23 (DTR)
EN: J1.11 (EN), R8.2, U3.3 (EN)
GND: C1.2, C2.2, C3.2, C4.2, C5.2, C6.2, C7.2, C8.2, C10.2, C11.2, C15.2, C19.2, D3.C, D4.C, D5.GND, D6.2, J1.25 (GND), J2.1 (2), J3.1, J4.6 (GND), J4.GND1 (GND), J4.GND2 (GND), J4.GND3 (GND), J4.GND4 (GND), J4.GND5 (GND), J4.GND6 (GND), J5.GND, J5.GND2 (GND), J6.3 (GND), J6.5 (GND), J6.9 (GND), Q5.2 (S), R6.1, R7.1, R9.1, R11.1, R12.1, R13.2, R15.1, R22.2, S1.3, S1.4, S3.3, S3.4, U1.A1 (VSS), U1.A9 (VSS), U1.B2 (VSS), U1.B8 (VSS), U1.E4 (VSS), U1.E5 (VSS), U1.F4 (VSS), U1.F5 (VSS), U1.K2 (VSS), U1.K3 (VSS), U1.K5 (VSS), U1.K7 (VSS), U1.K8 (VSS), U1.L1 (VSS), U1.L9 (VSS), U1.M1 (VSS), U1.M2 (VSS), U1.M8 (VSS), U1.M9 (VSS), U3.2 (GND), U4.2 (VSS), U5.1 (CTG), U5.4 (GND), U5.6 (QSTRT), U5.9 (GND), U6.2 (GND), U6.PAD (GND), USBSHLD.1
unnamed: R1.2, U6.9 (!RSTB)
unnamed: D3.A, R4.2
unnamed: Q2.5 (B), R17.2
unnamed: R5.1, R9.2, U6.8 (VBUS)
unnamed: Q2.2 (B), R18.2
unnamed: CHG.1, D1.C
unnamed: Q1.1 (G), R10.2
unnamed: R15.2, S2.3, S2.4
unnamed: CUR.2, U4.5 (PROG)
unnamed: D5.DI, JP1.2
unnamed: CUR.1, R13.1
unnamed: LED.2, R2.1
unnamed: CUR.3, R6.2
unnamed: D4.A, R2.2
unnamed: D6.6, U6.3 (D+)
unnamed: D6.1, J5.A6 (D+), J5.B6 (D+)
unnamed: D1.A, R3.2
unnamed: D6.4, U6.4 (D-)
unnamed: D6.3, J5.A7 (D-), J5.B7 (D-)
unnamed: I2C.3, R28.2
unnamed: I2C.1, R29.2
unnamed: JP2.2, R4.1
unnamed: D2.C, MEAS.1, MEAS.3 (1), Q1.2 (S)
unnamed: Q3.1 (G), R14.2
unnamed: C5.1, J4.4 (VCC), Q3.3 (D), R16.1
unnamed: R14.1, R19.2, SDPC.2
unnamed: Q5.3 (D), R20.2, R21.2
unnamed: C8.1, D5.VCC, JP3.2
unnamed: C2.1, C3.1, Q4.3 (D), R1.1, U6.5 (VIO), U6.6 (VDD), U6.7 (VREGIN)
unnamed: Q4.1 (G), R21.1
unnamed: Q5.1 (G), R23.2
unnamed: R22.1, SDPC.3
PA7/UART-LOG-TXD: J1.22 (A2), Q2.6 (C), S2.1, S2.2, U1.A5 (PA7/UART_LOG_TXD/!DWNLD!), U6.20 (RXD)
PA8/UART-LOG-RXD: J1.23 (A1), U1.A6 (PA8/UART_LOG_RXD), U6.21 (TXD)
PA12: J1.4 (GPIO5), JP1.1, U1.J9 (PA12/LP_UART_TXD/SPI1_PICO/I2S_MCLK)
PA13: J1.3 (GPIO6), U1.J8 (PA13/LP_UART_RXD/SPI1_POCI/I2S_SD_TX1)
PA14: J1.6 (GPIO3), U1.H9 (PA14/LP_UART_RTS/SPI1_CLK/I2S_SD_TX2)
PA15: J1.5 (GPIO4), U1.H8 (PA15/LP_UART_CTS/SPI1_CS)
PA25/SCL: J1.2 (SCL), J3.4, R28.1, U1.C2 (PA25/LP_I2C_SCL/HSDM/LP_UART_RXD), U5.7 (SCL)
PA26/SDA: J1.1 (SDA), J3.3, R29.1, U1.C1 (PA26/LP_I2C_SDA/HSDP/LP_UART_TXD), U5.8 (SDA)
PA27/SWD_DATA: J1.13 (FREEBIE), J6.2 (SWDIO), U1.H2 (PA27/SWD_DATA/LP_UART_RTS/WLAN_ACT)
PA28: J1.20 (A4), U1.B3 (PA28/BT_CK/RREF)
PA30: J1.21 (A3), S3.1, S3.2, U1.B1 (PA30/HS_PWM7)
PB1/LP_UART_TXD/A2: J1.14 (TX), U1.D8 (PB1/LP_UART_TXD/ADC)
PB2/LP_UART_RXD/A1: J1.15 (RX), U1.E8 (PB2/LP_UART_RXD/PCM_CLK/ADC)
PB3/SWD_CLK/A0: J1.24 (A0), J6.4 (SWDCLK), U1.J2 (PB3/SWD_CLK/ADC)
PB18/SPI0_PICO: J1.17 (PICO), J4.3 (CMD/SDI), U1.G9 (PB18/SPI0_PICO)
PB19/SPI0_POCI: J1.16 (POCI), J4.7 (DAT0/SDO), U1.G8 (PB19/SPI0_POCI/I2S_TX0)
PB20/SPI0_CLK: J1.18 (SCK), J4.5 (CLK/SCK), U1.F9 (PB20/SPI0_CLK/I2S_CLK)
PB21/SPI0_CS: J1.19 (A5), J4.2 (DAT3/!CS!), R16.2, U1.F8 (PB21/SPI0_CS/I2S_WS/QDEC_IDX)
PB22: J1.8 (GPIO1), JP2.1, U1.E9 (PB22/I2S_SD_RX/QDEC_PHB)
PB23/SDPC: J1.7 (GPIO2), SDPC.1, U1.C8 (PB23/I2S_MCLK/QDEC_PHA)
RTS: Q2.4 (E), R18.1, U6.19 (RTS)
USB_SHLD: J5.SHLD1 (SHLD), J5.SHLD2 (SHLD), J5.SHLD3 (SHLD), J5.SHLD4 (SHLD), J5.SHLD5 (SHLD), J5.SHLD6 (SHLD), J5.SHLD7 (SHLD), J5.SHLD8 (SHLD), USBSHLD.2
VIN: C7.1, MEAS.2, MEAS.4 (2), R8.1, U3.1 (IN)
V_BATT: C6.1, C15.1, J1.12 (V_BATT), J2.2 (1), Q1.3 (D), U4.3 (VBAT), U5.2 (CELL), U5.3 (VDD)
V_USB: C19.1, D2.A, D6.5, J1.10 (V_USB), J5.VBUS1 (VBUS), J5.VBUS2 (VBUS), R3.1, R5.2, R7.2, R10.1, R23.1, U4.4 (VIN)
WS2812-DO: D5.DO, J1.9 (GPIO0)

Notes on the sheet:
CP2104/2N (USB-to-Serial Converter)
V_BATT should be a single-cell LiPo battery.
Charge current: I_CHG = 1000 / R_PROG R_PROG=2k : I_CHG=500mA (DEFAULT) R_PROG=10k : I_CHG=100mA
Voltage Regulator
Lithium-Polymer Battery Charger (1-cell)
700mA out 6V max in
u-blox NORA-W306 Module
Thing Plus Headers
v10
QWIIC Connector & I2C Pullups
Pete Lewis
Power & GPIO LEDs
Based on designs by: M. Hord, A. Wende
V_USB - 6V MAX V_BATT - Single Cell (4.2V MAX)
100mA
500mA
Module recommended VCC range: 3.0-3.6V
Buttons
Auto program circuit DTR RTS EN LOG_TXD 1 1 1 1 0 0 1 1 1 0 0 1 0 1 1 0
Auto-Reset
USBSHLD Jumper Use this jumper to connect/disconnect your USB-C cable shield to this PCB's GND. Closed (default): connected to GND
Cut LED jumper to disable PWR LED
microSD Card
RGB Status LED
Fuel Gauge
Unshifted 7-bit I2C address: 0x36
Cut JP1 to disconnect WS2812B DI from GPIO pin.
***Boot Strap Pins*** (W306 includes internal pull-ups) See DS PG 10 for more info. PA30 PB19/SWD_DATA PA7/UART-LOG-TXD
Arduino Pin Mapping
9/A2
8/A1
19/A0
PA8
PA7
PA15
PA14
PA12
PA13
PA25
PA26

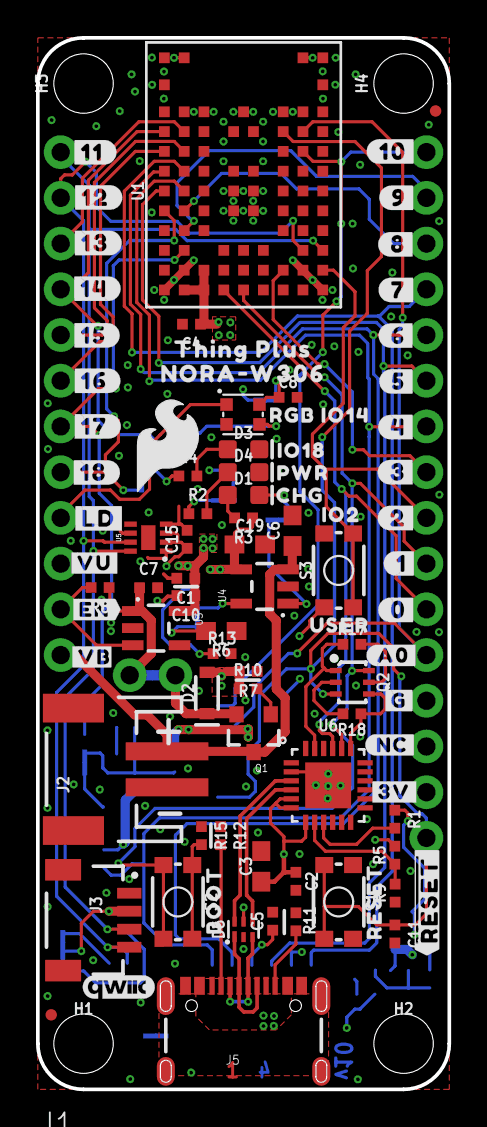
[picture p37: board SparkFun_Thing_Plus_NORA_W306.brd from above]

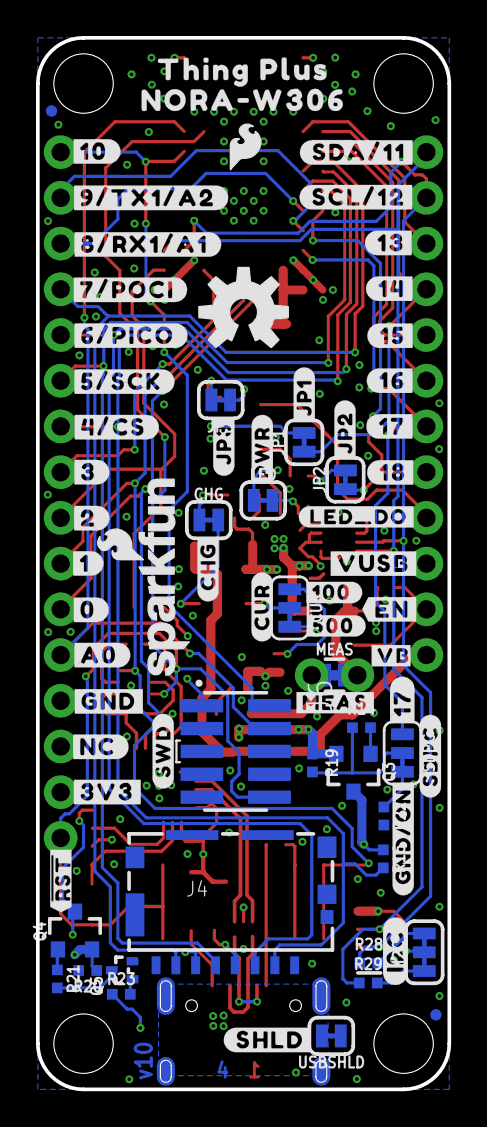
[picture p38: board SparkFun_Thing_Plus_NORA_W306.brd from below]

Board: 4 copper layers, 22.9 x 58.4 mm, 170 parts (74 on the bottom side), 66 nets.

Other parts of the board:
U$1, U$22: #17#11
U$2: BOOT0
U$3: #MEAS#1714141838
U$4: IO180
U$5: NORA#W3060
U$6: ##RST##23061714141845
U$7: USER0
U$8: SFE_LOGO_FLAME_.2
U$9: IO20
U$10: #GND#ON#3061714141842
U$11: #SDPC#0
U$12: #A0#1
U$13: #SDA#11#28
U$14: #17#28
U$15: #0#4
U$16: #1#4
U$17: #SCL#12#28
U$18: #18#28
U$19: SFE_LOGO_FLAME_.1
U$20: #LD#29
U$21: RGB_IO140
U$23: PWR0
U$24: #CUR#0
U$25: THING_PLUS1714141839
U$26, U$77: #VB26
U$28: NORA#W3061714141840
U$30: #13#13
U$31: #14#14
U$32: #15#15
U$33: #16#16
U$35: #18#18
U$36: #11#91420
U$37: #12#91420
U$38: #13#91420
U$39: #14#91420
U$40: #15#91420
U$41: #VUSB#0
U$42: #JP3#23061714141846
U$43: #EN#0
U$44: #16#91420
U$45: #3V3#0
U$46: #NC#2
U$47: #A0#18
U$48: #8#91421
U$49: #7#8
U$50: #6#8
U$51: #5#8
U$52: #4#8
U$53: #3#8
U$54: #2#8
U$55: #1#8
U$56: #0#8
U$57: #3V#23
U$58: #JP2#0
U$59: ORDERING_INSTRUCTIONS
U$60: #SWD#501
U$61: #100#23061714141846
U$62: THING_PLUS_0
U$63: #SHLD#9
U$64: #GND#10
U$65: #JP1#0
U$66: #PWR#14
U$67: #CHG#13
U$68: ##RESET##19
U$69: #NC#21
U$70: #9#10
U$71: #LED_DO#0
U$72: #I2C#3
U$73: #500#23061714141846
U$74: #10#11
U$75: #G#22
U$76: #VU#23
U$78: CHG0
U$79: RESET0
U$80: #EN#27
U$81: #2#28
U$82: #3#28
U$83: #4#CS#28
U$84: #5#SCK#28
U$85: #6#PICO#28
U$86: #7#POCI#28
U$87: #9#TX1#A2#28
U$88: #8#RX1#A1#28
U$91: #10#28

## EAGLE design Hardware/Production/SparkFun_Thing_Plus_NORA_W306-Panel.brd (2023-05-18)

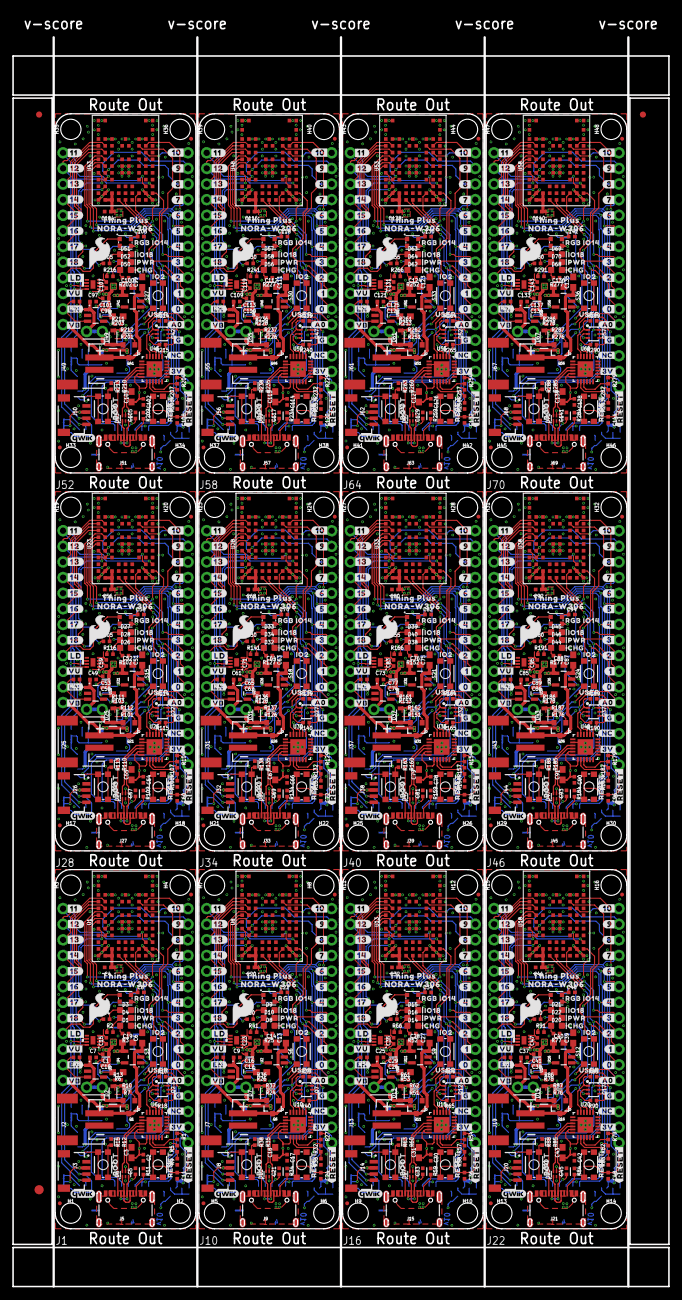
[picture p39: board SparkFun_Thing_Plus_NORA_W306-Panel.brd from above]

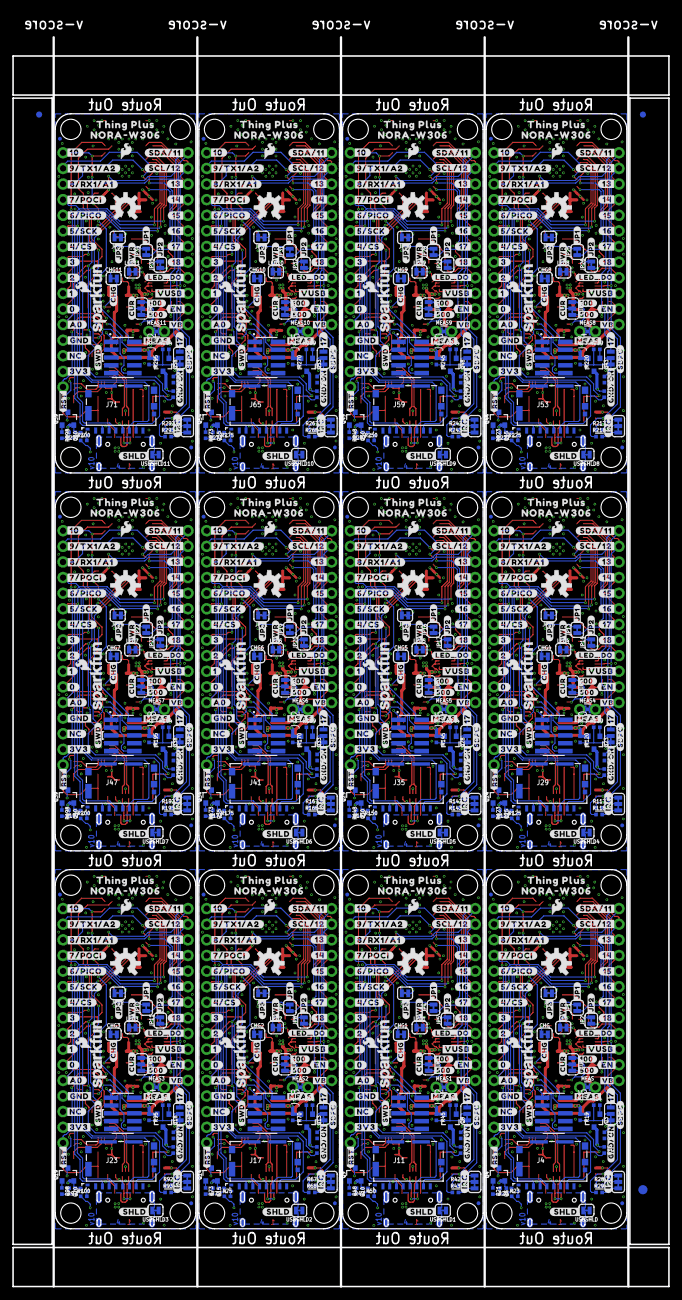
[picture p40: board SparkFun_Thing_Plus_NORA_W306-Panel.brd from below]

Board: 4 copper layers, 106.7 x 203.2 mm, 2022 parts (891 on the bottom side), 792 nets.

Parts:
C1, C4, C5, C16, C20, C21, C29, C32, C33, C41, C44, C45, C53, C56, C57, C65, C68, C69, C77, C80, C81, C89, C92, C93, C101, C104, C105, C113, C116, C117, C125, C128, C129, C137, C140, C141: 10uF; 0402-TIGHT
C2, C8, C11, C15, C17, C22, C23, C24, C30, C34, C35, C36, C42, C46, C47, C48, C54, C58, C59, C60, C66, C70, C71, C72, C78, C82, C83, C84, C90, C94, C95, C96, C102, C106, C107, C108, C114, C118, C119, C120, C126, C130, C131, C132, C138, C142, C143, C144: 0.1uF; 0402-TIGHT
C3, C6, C13, C14, C18, C19, C27, C28, C31, C39, C40, C43, C51, C52, C55, C63, C64, C67, C75, C76, C79, C87, C88, C91, C99, C100, C103, C111, C112, C115, C123, C124, C127, C135, C136, C139: 4.7uF; 0603
C7, C9, C10, C12, C25, C26, C37, C38, C49, C50, C61, C62, C73, C74, C85, C86, C97, C98, C109, C110, C121, C122, C133, C134: 1.0uF; 0402-TIGHT
CHG, CHG1, CHG2, CHG3, CHG4, CHG5, CHG6, CHG7, CHG8, CHG9, CHG10, CHG11: SMT-JUMPER_2_NC_TRACE_SILK
CUR, CUR1, CUR2, CUR3, CUR4, CUR5, CUR6, CUR7, CUR8, CUR9, CUR10, CUR11: SMT-JUMPER_3_1-NC_TRACE_SILK
D1, D8, D14, D20, D26, D32, D38, D44, D50, D56, D62, D68: Yellow; LED-0603
D2, D7, D13, D19, D25, D31, D37, D43, D49, D55, D61, D67: 1A/23V/620mV; SOD-323
D3, D9, D15, D21, D27, D33, D39, D45, D51, D57, D63, D69: BLUE; LED-0603
D4, D10, D16, D22, D28, D34, D40, D46, D52, D58, D64, D70: RED; LED-0603
D5, D12, D18, D24, D30, D36, D42, D48, D54, D60, D66, D72: WS2812; WS2812-2020
D6, D11, D17, D23, D29, D35, D41, D47, D53, D59, D65, D71: PRTR5V0U2F; SOT886
E$1, E$2, E$3, E$4: FIDUCIAL-1X2
E$5, E$6: FIDUCIAL-1.5X3
FD1, FD2, FD3, FD4, FD5, FD6, FD7, FD8, FD9, FD10, FD11, FD12, FD13, FD14, FD15, FD16, FD17, FD18, FD19, FD20, FD21, FD22, FD23, FD24, FD25, FD26, FD27, FD28, FD29, FD30, FD31, FD32, FD33, FD34, FD35, FD36, FD37, FD38, FD39, FD40, FD41, FD42, FD43, FD44, FD45, FD46, FD47, FD48: FIDUCIALUFIDUCIAL; FIDUCIAL-MICRO
H1, H2, H3, H4, H5, H6, H7, H8, H9, H10, H11, H12, H13, H14, H15, H16, H17, H18, H19, H20, H21, H22, H23, H24, H25, H26, H27, H28, H29, H30, H31, H32, H33, H34, H35, H36, H37, H38, H39, H40, H41, H42, H43, H44, H45, H46, H47, H48: STAND-OFF
I2C, I2C1, I2C2, I2C3, I2C4, I2C5, I2C6, I2C7, I2C8, I2C9, I2C10, I2C11: JUMPER-SMT_3_2-NC_TRACE_SILK; SMT-JUMPER_3_2-NC_TRACE_SILK
J1, J10, J16, J22, J28, J34, J40, J46, J52, J58, J64, J70: THING_PLUS_LOGICAL; THING_PLUS
J2, J7, J13, J19, J25, J31, J37, J43, J49, J55, J61, J67: LiPo; JST-2-SMD
J3, J8, J14, J20, J26, J32, J38, J44, J50, J56, J62, J68: QWIIC_RIGHT_ANGLE; JST04_1MM_RA
J4, J11, J17, J23, J29, J35, J41, J47, J53, J59, J65, J71: SDFRICTION; MICROSD_TINY
J5, J9, J15, J21, J27, J33, J39, J45, J51, J57, J63, J69: USB-C; USB-C-16P-4LAYER-ISOLATED
J6, J12, J18, J24, J30, J36, J42, J48, J54, J60, J66, J72: SWD (DNP); 2X5-SMD-UNSHROUDED_DNP_NO_PASTE
JP1, JP2, JP3, JP4, JP5, JP6, JP7, JP8, JP9, JP10, JP11, JP12, JP13, JP14, JP15, JP16, JP17, JP18, JP19, JP20, JP21, JP22, JP23, JP24, JP25, JP26, JP27, JP28, JP29, JP30, JP31, JP32, JP33, JP34, JP35, JP36: SMT-JUMPER_2_NC_TRACE_SILK
LED, LED1, LED2, LED3, LED4, LED5, LED6, LED7, LED8, LED9, LED10, LED11: SMT-JUMPER_2_NC_TRACE_SILK
LOGO1, LOGO2, LOGO7, LOGO10, LOGO13, LOGO16, LOGO19, LOGO22, LOGO25, LOGO28, LOGO31, LOGO34: OSHW-LOGOM; OSHW-LOGO-M
LOGO3, LOGO5, LOGO9, LOGO12, LOGO15, LOGO18, LOGO21, LOGO24, LOGO27, LOGO30, LOGO33, LOGO36: SFE_LOGO_NAME_FLAME.1_INCH; SFE_LOGO_NAME_FLAME_.1
LOGO4, LOGO6, LOGO8, LOGO11, LOGO14, LOGO17, LOGO20, LOGO23, LOGO26, LOGO29, LOGO32, LOGO35: QWIIC_LOGO_4MM; QWIIC_4MM
MEAS, MEAS1, MEAS2, MEAS3, MEAS4, MEAS5, MEAS6, MEAS7, MEAS8, MEAS9, MEAS10, MEAS11: COMBO-JUMPER_2_NC_TRACE
Q1, Q3, Q4, Q6, Q8, Q9, Q11, Q13, Q14, Q16, Q18, Q19, Q21, Q23, Q24, Q26, Q28, Q29, Q31, Q33, Q34, Q36, Q38, Q39, Q41, Q43, Q44, Q46, Q48, Q49, Q51, Q53, Q54, Q56, Q58, Q59: 20V/4.2A/52mΩ/1.4W; SOT23-3
Q2, Q7, Q12, Q17, Q22, Q27, Q32, Q37, Q42, Q47, Q52, Q57: MBT3904DW1T1; SC70-6
Q5, Q10, Q15, Q20, Q25, Q30, Q35, Q40, Q45, Q50, Q55, Q60: 20V/0.2A/8MHz/1.2Ω/1Vth; SOT-416FL
R1, R13, R17, R18, R27, R36, R39, R40, R54, R61, R64, R65, R79, R86, R89, R90, R104, R111, R114, R115, R129, R136, R139, R140, R154, R161, R164, R165, R179, R186, R189, R190, R204, R211, R214, R215, R229, R236, R239, R240, R254, R261, R264, R265, R279, R286, R289, R290: 10k; 0402-TIGHT
R2, R3, R4, R25, R30, R41, R52, R55, R66, R77, R80, R91, R102, R105, R116, R127, R130, R141, R152, R155, R166, R177, R180, R191, R202, R205, R216, R227, R230, R241, R252, R255, R266, R277, R280, R291: 4.7k; 0402-TIGHT
R5, R32, R57, R82, R107, R132, R157, R182, R207, R232, R257, R282: 22k; 0402-TIGHT
R6, R26, R53, R78, R103, R128, R153, R178, R203, R228, R253, R278: 2.0k; 0603
R7, R8, R16, R19, R20, R24, R31, R45, R46, R47, R51, R56, R70, R71, R72, R76, R81, R95, R96, R97, R101, R106, R120, R121, R122, R126, R131, R145, R146, R147, R151, R156, R170, R171, R172, R176, R181, R195, R196, R197, R201, R206, R220, R221, R222, R226, R231, R245, R246, R247, R251, R256, R270, R271, R272, R276, R281, R295, R296, R297: 100k; 0402-TIGHT
R9, R33, R58, R83, R108, R133, R158, R183, R208, R233, R258, R283: 33k; 0402-TIGHT
R10, R14, R21, R23, R37, R44, R48, R50, R62, R69, R73, R75, R87, R94, R98, R100, R112, R119, R123, R125, R137, R144, R148, R150, R162, R169, R173, R175, R187, R194, R198, R200, R212, R219, R223, R225, R237, R244, R248, R250, R262, R269, R273, R275, R287, R294, R298, R300: 100; 0402-TIGHT
R11, R12, R34, R35, R59, R60, R84, R85, R109, R110, R134, R135, R159, R160, R184, R185, R209, R210, R234, R235, R259, R260, R284, R285: 5.1k; 0402-TIGHT
R15, R22, R38, R49, R63, R74, R88, R99, R113, R124, R138, R149, R163, R174, R188, R199, R213, R224, R238, R249, R263, R274, R288, R299: 1k; 0402-TIGHT
R28, R29, R42, R43, R67, R68, R92, R93, R117, R118, R142, R143, R167, R168, R192, R193, R217, R218, R242, R243, R267, R268, R292, R293: 2.2k; 0402-TIGHT
S1, S4, S7, S10, S13, S16, S19, S22, S25, S28, S31, S34: RESET; TACTILE_SWITCH_SMD_4.6X2.8MM
S2, S5, S8, S11, S14, S17, S20, S23, S26, S29, S32, S35: BOOT; TACTILE_SWITCH_SMD_4.6X2.8MM
S3, S6, S9, S12, S15, S18, S21, S24, S27, S30, S33, S36: USER; TACTILE_SWITCH_SMD_4.6X2.8MM
SDPC, SDPC1, SDPC2, SDPC3, SDPC4, SDPC5, SDPC6, SDPC7, SDPC8, SDPC9, SDPC10, SDPC11: SMT-JUMPER_3_1-NC_TRACE_SILK
U1, U8, U13, U18, U23, U28, U33, U38, U43, U48, U53, U58: UBLOX_NORA_W306; UBLOX-NORA-W3
U2, U4, U11, U16, U21, U26, U31, U36, U41, U46, U51, U56: MCP73831; SOT23-5
U3, U7, U12, U17, U22, U27, U32, U37, U42, U47, U52, U57: XC6222B331MR-G; SOT23-5
U5, U9, U14, U19, U24, U29, U34, U39, U44, U49, U54, U59: MAX17048; DFN-8
U6, U10, U15, U20, U25, U30, U35, U40, U45, U50, U55, U60: CP2102N; QFN24
U$1, U$22, U$132, U$161, U$217, U$246, U$302, U$331, U$387, U$416, U$472, U$501, U$557, U$586, U$642, U$671, U$727, U$756, U$812, U$841, U$897, U$926, U$982, U$1011: #17#11
U$2, U$92, U$177, U$262, U$347, U$432, U$517, U$602, U$687, U$772, U$857, U$942: BOOT0
U$3, U$157, U$242, U$327, U$412, U$497, U$582, U$667, U$752, U$837, U$922, U$1007: #MEAS#1714141838
U$4, U$166, U$251, U$336, U$421, U$506, U$591, U$676, U$761, U$846, U$931, U$1016: IO180
U$5, U$94, U$179, U$264, U$349, U$434, U$519, U$604, U$689, U$774, U$859, U$944: NORA#W3060
U$6, U$162, U$247, U$332, U$417, U$502, U$587, U$672, U$757, U$842, U$927, U$1012: ##RST##23061714141845
U$7, U$123, U$208, U$293, U$378, U$463, U$548, U$633, U$718, U$803, U$888, U$973: USER0
U$8, U$95, U$180, U$265, U$350, U$435, U$520, U$605, U$690, U$775, U$860, U$945: SFE_LOGO_FLAME_.2
U$9, U$167, U$252, U$337, U$422, U$507, U$592, U$677, U$762, U$847, U$932, U$1017: IO20
U$10, U$160, U$245, U$330, U$415, U$500, U$585, U$670, U$755, U$840, U$925, U$1010: #GND#ON#3061714141842
U$11, U$170, U$255, U$340, U$425, U$510, U$595, U$680, U$765, U$850, U$935, U$1020: #SDPC#0
U$12, U$96, U$181, U$266, U$351, U$436, U$521, U$606, U$691, U$776, U$861, U$946: #A0#1
U$13, U$150, U$235, U$320, U$405, U$490, U$575, U$660, U$745, U$830, U$915, U$1000: #SDA#11#28
U$14, U$152, U$237, U$322, U$407, U$492, U$577, U$662, U$747, U$832, U$917, U$1002: #17#28
U$15, U$97, U$182, U$267, U$352, U$437, U$522, U$607, U$692, U$777, U$862, U$947: #0#4
U$16, U$98, U$183, U$268, U$353, U$438, U$523, U$608, U$693, U$778, U$863, U$948: #1#4
U$17, U$151, U$236, U$321, U$406, U$491, U$576, U$661, U$746, U$831, U$916, U$1001: #SCL#12#28
U$18, U$153, U$238, U$323, U$408, U$493, U$578, U$663, U$748, U$833, U$918, U$1003: #18#28
U$19, U$154, U$239, U$324, U$409, U$494, U$579, U$664, U$749, U$834, U$919, U$1004: SFE_LOGO_FLAME_.1
U$20, U$155, U$240, U$325, U$410, U$495, U$580, U$665, U$750, U$835, U$920, U$1005: #LD#29
U$21, U$168, U$253, U$338, U$423, U$508, U$593, U$678, U$763, U$848, U$933, U$1018: RGB_IO140
U$23, U$93, U$178, U$263, U$348, U$433, U$518, U$603, U$688, U$773, U$858, U$943: PWR0
U$24, U$169, U$254, U$339, U$424, U$509, U$594, U$679, U$764, U$849, U$934, U$1019: #CUR#0
U$25, U$158, U$243, U$328, U$413, U$498, U$583, U$668, U$753, U$838, U$923, U$1008: THING_PLUS1714141839
U$26, U$77, U$139, U$156, U$224, U$241, U$309, U$326, U$394, U$411, U$479, U$496, U$564, U$581, U$649, U$666, U$734, U$751, U$819, U$836, U$904, U$921, U$989, U$1006: #VB26
U$27, U$78, U$171, U$256, U$341, U$426, U$511, U$596, U$681, U$766, U$851, U$936: CHG0
U$28, U$159, U$244, U$329, U$414, U$499, U$584, U$669, U$754, U$839, U$924, U$1009: NORA#W3061714141840
U$29, U$79, U$172, U$257, U$342, U$427, U$512, U$597, U$682, U$767, U$852, U$937: RESET0
U$30, U$99, U$184, U$269, U$354, U$439, U$524, U$609, U$694, U$779, U$864, U$949: #13#13
U$31, U$100, U$185, U$270, U$355, U$440, U$525, U$610, U$695, U$780, U$865, U$950: #14#14
U$32, U$101, U$186, U$271, U$356, U$441, U$526, U$611, U$696, U$781, U$866, U$951: #15#15
U$33, U$102, U$187, U$272, U$357, U$442, U$527, U$612, U$697, U$782, U$867, U$952: #16#16
U$34, U$41, U$173, U$258, U$343, U$428, U$513, U$598, U$683, U$768, U$853, U$938: #VUSB#0
U$35, U$133, U$218, U$303, U$388, U$473, U$558, U$643, U$728, U$813, U$898, U$983: #18#18
U$36, U$103, U$188, U$273, U$358, U$443, U$528, U$613, U$698, U$783, U$868, U$953: #11#91420
U$37, U$104, U$189, U$274, U$359, U$444, U$529, U$614, U$699, U$784, U$869, U$954: #12#91420
U$38, U$105, U$190, U$275, U$360, U$445, U$530, U$615, U$700, U$785, U$870, U$955: #13#91420
U$39, U$106, U$191, U$276, U$361, U$446, U$531, U$616, U$701, U$786, U$871, U$956: #14#91420
U$40, U$107, U$192, U$277, U$362, U$447, U$532, U$617, U$702, U$787, U$872, U$957: #15#91420
U$42, U$163, U$248, U$333, U$418, U$503, U$588, U$673, U$758, U$843, U$928, U$1013: #JP3#23061714141846
U$43, U$59, U$174, U$259, U$344, U$429, U$514, U$599, U$684, U$769, U$854, U$939: #EN#0
U$44, U$108, U$193, U$278, U$363, U$448, U$533, U$618, U$703, U$788, U$873, U$958: #16#91420
U$45, U$89, U$175, U$260, U$345, U$430, U$515, U$600, U$685, U$770, U$855, U$940: #3V3#0
U$46, U$124, U$209, U$294, U$379, U$464, U$549, U$634, U$719, U$804, U$889, U$974: #NC#2
U$47, U$122, U$207, U$292, U$377, U$462, U$547, U$632, U$717, U$802, U$887, U$972: #A0#18
U$48, U$109, U$194, U$279, U$364, U$449, U$534, U$619, U$704, U$789, U$874, U$959: #8#91421
U$49, U$110, U$195, U$280, U$365, U$450, U$535, U$620, U$705, U$790, U$875, U$960: #7#8
U$50, U$111, U$196, U$281, U$366, U$451, U$536, U$621, U$706, U$791, U$876, U$961: #6#8
U$51, U$112, U$197, U$282, U$367, U$452, U$537, U$622, U$707, U$792, U$877, U$962: #5#8
U$52, U$113, U$198, U$283, U$368, U$453, U$538, U$623, U$708, U$793, U$878, U$963: #4#8
U$53, U$114, U$199, U$284, U$369, U$454, U$539, U$624, U$709, U$794, U$879, U$964: #3#8
U$54, U$115, U$200, U$285, U$370, U$455, U$540, U$625, U$710, U$795, U$880, U$965: #2#8
U$55, U$116, U$201, U$286, U$371, U$456, U$541, U$626, U$711, U$796, U$881, U$966: #1#8
U$56, U$117, U$202, U$287, U$372, U$457, U$542, U$627, U$712, U$797, U$882, U$967: #0#8
U$57, U$137, U$222, U$307, U$392, U$477, U$562, U$647, U$732, U$817, U$902, U$987: #3V#23
U$58, U$127, U$212, U$297, U$382, U$467, U$552, U$637, U$722, U$807, U$892, U$977: #JP2#0
U$60, U$126, U$211, U$296, U$381, U$466, U$551, U$636, U$721, U$806, U$891, U$976: #SWD#501
U$61, U$164, U$249, U$334, U$419, U$504, U$589, U$674, U$759, U$844, U$929, U$1014: #100#23061714141846
U$62, U$90, U$176, U$261, U$346, U$431, U$516, U$601, U$686, U$771, U$856, U$941: THING_PLUS_0
U$63, U$118, U$203, U$288, U$373, U$458, U$543, U$628, U$713, U$798, U$883, U$968: #SHLD#9
U$64, U$119, U$204, U$289, U$374, U$459, U$544, U$629, U$714, U$799, U$884, U$969: #GND#10
U$65, U$129, U$214, U$299, U$384, U$469, U$554, U$639, U$724, U$809, U$894, U$979: #JP1#0
U$66, U$121, U$206, U$291, U$376, U$461, U$546, U$631, U$716, U$801, U$886, U$971: #PWR#14
U$67, U$120, U$205, U$290, U$375, U$460, U$545, U$630, U$715, U$800, U$885, U$970: #CHG#13
U$68, U$134, U$219, U$304, U$389, U$474, U$559, U$644, U$729, U$814, U$899, U$984: ##RESET##19
U$69, U$135, U$220, U$305, U$390, U$475, U$560, U$645, U$730, U$815, U$900, U$985: #NC#21
U$70, U$130, U$215, U$300, U$385, U$470, U$555, U$640, U$725, U$810, U$895, U$980: #9#10
U$71, U$128, U$213, U$298, U$383, U$468, U$553, U$638, U$723, U$808, U$893, U$978: #LED_DO#0
U$72, U$125, U$210, U$295, U$380, U$465, U$550, U$635, U$720, U$805, U$890, U$975: #I2C#3
U$73, U$165, U$250, U$335, U$420, U$505, U$590, U$675, U$760, U$845, U$930, U$1015: #500#23061714141846
U$74, U$131, U$216, U$301, U$386, U$471, U$556, U$641, U$726, U$811, U$896, U$981: #10#11
U$75, U$136, U$221, U$306, U$391, U$476, U$561, U$646, U$731, U$816, U$901, U$986: #G#22
U$76, U$138, U$223, U$308, U$393, U$478, U$563, U$648, U$733, U$818, U$903, U$988: #VU#23
U$80, U$140, U$225, U$310, U$395, U$480, U$565, U$650, U$735, U$820, U$905, U$990: #EN#27
U$81, U$141, U$226, U$311, U$396, U$481, U$566, U$651, U$736, U$821, U$906, U$991: #2#28
U$82, U$142, U$227, U$312, U$397, U$482, U$567, U$652, U$737, U$822, U$907, U$992: #3#28
U$83, U$143, U$228, U$313, U$398, U$483, U$568, U$653, U$738, U$823, U$908, U$993: #4#CS#28
U$84, U$144, U$229, U$314, U$399, U$484, U$569, U$654, U$739, U$824, U$909, U$994: #5#SCK#28
U$85, U$145, U$230, U$315, U$400, U$485, U$570, U$655, U$740, U$825, U$910, U$995: #6#PICO#28
U$86, U$146, U$231, U$316, U$401, U$486, U$571, U$656, U$741, U$826, U$911, U$996: #7#POCI#28
U$87, U$148, U$233, U$318, U$403, U$488, U$573, U$658, U$743, U$828, U$913, U$998: #9#TX1#A2#28
U$88, U$147, U$232, U$317, U$402, U$487, U$572, U$657, U$742, U$827, U$912, U$997: #8#RX1#A1#28
U$91, U$149, U$234, U$319, U$404, U$489, U$574, U$659, U$744, U$829, U$914, U$999: #10#28
USBSHLD, USBSHLD1, USBSHLD2, USBSHLD3, USBSHLD4, USBSHLD5, USBSHLD6, USBSHLD7, USBSHLD8, USBSHLD9, USBSHLD10, USBSHLD11: SMT-JUMPER_2_NC_TRACE_SILK

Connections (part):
3.3V: C1.1, C4.1, C10.1, I2C.2, J1.27, J3.2, J6.1, JP3.1, LED.1, Q3.2, Q4.2, R19.1, R20.1, U1.A7, U1.A8, U1.B7, U3.5
3.3V1: C12.1, C16.1, C20.1, I2C1.2, J8.2, J10.27, J12.1, JP6.1, LED1.1, Q8.2, Q9.2, R45.1, R47.1, U7.5, U8.A7, U8.A8, U8.B7
3.3V2: C26.1, C29.1, C32.1, I2C2.2, J14.2, J16.27, J18.1, JP9.1, LED2.1, Q13.2, Q14.2, R70.1, R72.1, U12.5, U13.A7, U13.A8, U13.B7
3.3V3: C38.1, C41.1, C44.1, I2C3.2, J20.2, J22.27, J24.1, JP12.1, LED3.1, Q18.2, Q19.2, R95.1, R97.1, U17.5, U18.A7, U18.A8, U18.B7
3.3V4: C50.1, C53.1, C56.1, I2C4.2, J26.2, J28.27, J30.1, JP15.1, LED4.1, Q23.2, Q24.2, R120.1, R122.1, U22.5, U23.A7, U23.A8, U23.B7
3.3V5: C62.1, C65.1, C68.1, I2C5.2, J32.2, J34.27, J36.1, JP18.1, LED5.1, Q28.2, Q29.2, R145.1, R147.1, U27.5, U28.A7, U28.A8, U28.B7
3.3V6: C74.1, C77.1, C80.1, I2C6.2, J38.2, J40.27, J42.1, JP21.1, LED6.1, Q33.2, Q34.2, R170.1, R172.1, U32.5, U33.A7, U33.A8, U33.B7
3.3V7: C86.1, C89.1, C92.1, I2C7.2, J44.2, J46.27, J48.1, JP24.1, LED7.1, Q38.2, Q39.2, R195.1, R197.1, U37.5, U38.A7, U38.A8, U38.B7
3.3V8: C98.1, C101.1, C104.1, I2C8.2, J50.2, J52.27, J54.1, JP27.1, LED8.1, Q43.2, Q44.2, R220.1, R222.1, U42.5, U43.A7, U43.A8, U43.B7
3.3V9: C110.1, C113.1, C116.1, I2C9.2, J56.2, J58.27, J60.1, JP30.1, LED9.1, Q48.2, Q49.2, R245.1, R247.1, U47.5, U48.A7, U48.A8, U48.B7
3.3V10: C122.1, C125.1, C128.1, I2C10.2, J62.2, J64.27, J66.1, JP33.1, LED10.1, Q53.2, Q54.2, R270.1, R272.1, U52.5, U53.A7, U53.A8, U53.B7
3.3V11: C134.1, C137.1, C140.1, I2C11.2, J68.2, J70.27, J72.1, JP36.1, LED11.1, Q58.2, Q59.2, R295.1, R297.1, U57.5, U58.A7, U58.A8, U58.B7
!RESET!: C11.1, J1.28, J6.10, Q2.3, S1.1, S1.2, U1.J3
!RESET!1: C24.1, J10.28, J12.10, Q7.3, S4.1, S4.2, U8.J3
!RESET!2: C36.1, J16.28, J18.10, Q12.3, S7.1, S7.2, U13.J3
!RESET!3: C48.1, J22.28, J24.10, Q17.3, S10.1, S10.2, U18.J3
!RESET!4: C60.1, J28.28, J30.10, Q22.3, S13.1, S13.2, U23.J3
!RESET!5: C72.1, J34.28, J36.10, Q27.3, S16.1, S16.2, U28.J3
!RESET!6: C84.1, J40.28, J42.10, Q32.3, S19.1, S19.2, U33.J3
!RESET!7: C96.1, J46.28, J48.10, Q37.3, S22.1, S22.2, U38.J3
!RESET!8: C108.1, J52.28, J54.10, Q42.3, S25.1, S25.2, U43.J3
!RESET!9: C120.1, J58.28, J60.10, Q47.3, S28.1, S28.2, U48.J3
!RESET!10: C132.1, J64.28, J66.10, Q52.3, S31.1, S31.2, U53.J3
!RESET!11: C144.1, J70.28, J72.10, Q57.3, S34.1, S34.2, U58.J3
CC1: J5.A5, R12.2
CC2: J5.B5, R11.2
CC3: J9.B5, R34.2
CC4: J9.A5, R35.2
CC5: J15.B5, R59.2
CC6: J15.A5, R60.2
CC7: J21.B5, R84.2
CC8: J21.A5, R85.2
CC9: J27.B5, R109.2
CC10: J27.A5, R110.2
CC11: J33.B5, R134.2
CC12: J33.A5, R135.2
CC13: J39.B5, R159.2
CC14: J39.A5, R160.2
CC15: J45.B5, R184.2
CC16: J45.A5, R185.2
CC17: J51.B5, R209.2
CC18: J51.A5, R210.2
CC19: J57.B5, R234.2
CC20: J57.A5, R235.2
CC21: J63.B5, R259.2
CC22: J63.A5, R260.2
CC23: J69.B5, R284.2
CC24: J69.A5, R285.2
CHG: CHG.2, U4.1
CHG1: CHG1.2, U2.1
CHG2: CHG2.2, U11.1
CHG3: CHG3.2, U16.1
CHG4: CHG4.2, U21.1
CHG5: CHG5.2, U26.1
CHG6: CHG6.2, U31.1
CHG7: CHG7.2, U36.1
CHG8: CHG8.2, U41.1
CHG9: CHG9.2, U46.1
CHG10: CHG10.2, U51.1
CHG11: CHG11.2, U56.1
DTR: Q2.1, R17.1, U6.23
DTR1: Q7.1, R39.1, U10.23
DTR2: Q12.1, R64.1, U15.23
DTR3: Q17.1, R89.1, U20.23
DTR4: Q22.1, R114.1, U25.23
DTR5: Q27.1, R139.1, U30.23
DTR6: Q32.1, R164.1, U35.23
DTR7: Q37.1, R189.1, U40.23
DTR8: Q42.1, R214.1, U45.23
DTR9: Q47.1, R239.1, U50.23
DTR10: Q52.1, R264.1, U55.23
DTR11: Q57.1, R289.1, U60.23
EN: J1.11, R8.2, U3.3
EN1: J10.11, R31.2, U7.3
EN2: J16.11, R56.2, U12.3
EN3: J22.11, R81.2, U17.3
EN4: J28.11, R106.2, U22.3
EN5: J34.11, R131.2, U27.3
EN6: J40.11, R156.2, U32.3
EN7: J46.11, R181.2, U37.3
EN8: J52.11, R206.2, U42.3
EN9: J58.11, R231.2, U47.3
EN10: J64.11, R256.2, U52.3
EN11: J70.11, R281.2, U57.3
GND: C1.2, C2.2, C3.2, C4.2, C5.2, C6.2, C7.2, C8.2, C10.2, C11.2, C15.2, C19.2, D3.C, D4.C, D5.GND, D6.2, J1.25, J2.1, J3.1, J4.6, J4.GND1, J4.GND2, J4.GND3, J4.GND4, J4.GND5, J4.GND6, J5.GND, J5.GND2, J6.3, J6.5, J6.9, Q5.2, R6.1, R7.1, R9.1, R11.1, R12.1, R13.2, R15.1, R22.2, S1.3, S1.4, S3.3, S3.4, U1.A1, U1.A9, U1.B2, U1.B8, U1.E4, U1.E5, U1.F4, U1.F5, U1.K2, U1.K3, U1.K5, U1.K7, U1.K8, U1.L1, U1.L9, U1.M1, U1.M2, U1.M8, U1.M9, U3.2, U4.2, U5.1, U5.4, U5.6, U5.9, U6.2, U6.PAD, USBSHLD.1
GND1: C9.2, C12.2, C13.2, C14.2, C16.2, C17.2, C18.2, C20.2, C21.2, C22.2, C23.2, C24.2, D9.C, D10.C, D11.2, D12.GND, J7.1, J8.1, J9.GND, J9.GND2, J10.25, J11.6, J11.GND1, J11.GND2, J11.GND3, J11.GND4, J11.GND5, J11.GND6, J12.3, J12.5, J12.9, Q10.2, R24.1, R26.1, R33.1, R34.1, R35.1, R36.2, R38.1, R49.2, S4.3, S4.4, S6.3, S6.4, U2.2, U7.2, U8.A1, U8.A9, U8.B2, U8.B8, U8.E4, U8.E5, U8.F4, U8.F5, U8.K2, U8.K3, U8.K5, U8.K7, U8.K8, U8.L1, U8.L9, U8.M1, U8.M2, U8.M8, U8.M9, U9.1, U9.4, U9.6, U9.9, U10.2, U10.PAD, USBSHLD1.1
GND2: C25.2, C26.2, C27.2, C28.2, C29.2, C30.2, C31.2, C32.2, C33.2, C34.2, C35.2, C36.2, D15.C, D16.C, D17.2, D18.GND, J13.1, J14.1, J15.GND, J15.GND2, J16.25, J17.6, J17.GND1, J17.GND2, J17.GND3, J17.GND4, J17.GND5, J17.GND6, J18.3, J18.5, J18.9, Q15.2, R51.1, R53.1, R58.1, R59.1, R60.1, R61.2, R63.1, R74.2, S7.3, S7.4, S9.3, S9.4, U11.2, U12.2, U13.A1, U13.A9, U13.B2, U13.B8, U13.E4, U13.E5, U13.F4, U13.F5, U13.K2, U13.K3, U13.K5, U13.K7, U13.K8, U13.L1, U13.L9, U13.M1, U13.M2, U13.M8, U13.M9, U14.1, U14.4, U14.6, U14.9, U15.2, U15.PAD, USBSHLD2.1
GND3: C37.2, C38.2, C39.2, C40.2, C41.2, C42.2, C43.2, C44.2, C45.2, C46.2, C47.2, C48.2, D21.C, D22.C, D23.2, D24.GND, J19.1, J20.1, J21.GND, J21.GND2, J22.25, J23.6, J23.GND1, J23.GND2, J23.GND3, J23.GND4, J23.GND5, J23.GND6, J24.3, J24.5, J24.9, Q20.2, R76.1, R78.1, R83.1, R84.1, R85.1, R86.2, R88.1, R99.2, S10.3, S10.4, S12.3, S12.4, U16.2, U17.2, U18.A1, U18.A9, U18.B2, U18.B8, U18.E4, U18.E5, U18.F4, U18.F5, U18.K2, U18.K3, U18.K5, U18.K7, U18.K8, U18.L1, U18.L9, U18.M1, U18.M2, U18.M8, U18.M9, U19.1, U19.4, U19.6, U19.9, U20.2, U20.PAD, USBSHLD3.1
GND4: C49.2, C50.2, C51.2, C52.2, C53.2, C54.2, C55.2, C56.2, C57.2, C58.2, C59.2, C60.2, D27.C, D28.C, D29.2, D30.GND, J25.1, J26.1, J27.GND, J27.GND2, J28.25, J29.6, J29.GND1, J29.GND2, J29.GND3, J29.GND4, J29.GND5, J29.GND6, J30.3, J30.5, J30.9, Q25.2, R101.1, R103.1, R108.1, R109.1, R110.1, R111.2, R113.1, R124.2, S13.3, S13.4, S15.3, S15.4, U21.2, U22.2, U23.A1, U23.A9, U23.B2, U23.B8, U23.E4, U23.E5, U23.F4, U23.F5, U23.K2, U23.K3, U23.K5, U23.K7, U23.K8, U23.L1, U23.L9, U23.M1, U23.M2, U23.M8, U23.M9, U24.1, U24.4, U24.6, U24.9, U25.2, U25.PAD, USBSHLD4.1
GND5: C61.2, C62.2, C63.2, C64.2, C65.2, C66.2, C67.2, C68.2, C69.2, C70.2, C71.2, C72.2, D33.C, D34.C, D35.2, D36.GND, J31.1, J32.1, J33.GND, J33.GND2, J34.25, J35.6, J35.GND1, J35.GND2, J35.GND3, J35.GND4, J35.GND5, J35.GND6, J36.3, J36.5, J36.9, Q30.2, R126.1, R128.1, R133.1, R134.1, R135.1, R136.2, R138.1, R149.2, S16.3, S16.4, S18.3, S18.4, U26.2, U27.2, U28.A1, U28.A9, U28.B2, U28.B8, U28.E4, U28.E5, U28.F4, U28.F5, U28.K2, U28.K3, U28.K5, U28.K7, U28.K8, U28.L1, U28.L9, U28.M1, U28.M2, U28.M8, U28.M9, U29.1, U29.4, U29.6, U29.9, U30.2, U30.PAD, USBSHLD5.1
GND6: C73.2, C74.2, C75.2, C76.2, C77.2, C78.2, C79.2, C80.2, C81.2, C82.2, C83.2, C84.2, D39.C, D40.C, D41.2, D42.GND, J37.1, J38.1, J39.GND, J39.GND2, J40.25, J41.6, J41.GND1, J41.GND2, J41.GND3, J41.GND4, J41.GND5, J41.GND6, J42.3, J42.5, J42.9, Q35.2, R151.1, R153.1, R158.1, R159.1, R160.1, R161.2, R163.1, R174.2, S19.3, S19.4, S21.3, S21.4, U31.2, U32.2, U33.A1, U33.A9, U33.B2, U33.B8, U33.E4, U33.E5, U33.F4, U33.F5, U33.K2, U33.K3, U33.K5, U33.K7, U33.K8, U33.L1, U33.L9, U33.M1, U33.M2, U33.M8, U33.M9, U34.1, U34.4, U34.6, U34.9, U35.2, U35.PAD, USBSHLD6.1
GND7: C85.2, C86.2, C87.2, C88.2, C89.2, C90.2, C91.2, C92.2, C93.2, C94.2, C95.2, C96.2, D45.C, D46.C, D47.2, D48.GND, J43.1, J44.1, J45.GND, J45.GND2, J46.25, J47.6, J47.GND1, J47.GND2, J47.GND3, J47.GND4, J47.GND5, J47.GND6, J48.3, J48.5, J48.9, Q40.2, R176.1, R178.1, R183.1, R184.1, R185.1, R186.2, R188.1, R199.2, S22.3, S22.4, S24.3, S24.4, U36.2, U37.2, U38.A1, U38.A9, U38.B2, U38.B8, U38.E4, U38.E5, U38.F4, U38.F5, U38.K2, U38.K3, U38.K5, U38.K7, U38.K8, U38.L1, U38.L9, U38.M1, U38.M2, U38.M8, U38.M9, U39.1, U39.4, U39.6, U39.9, U40.2, U40.PAD, USBSHLD7.1
GND8: C97.2, C98.2, C99.2, C100.2, C101.2, C102.2, C103.2, C104.2, C105.2, C106.2, C107.2, C108.2, D51.C, D52.C, D53.2, D54.GND, J49.1, J50.1, J51.GND, J51.GND2, J52.25, J53.6, J53.GND1, J53.GND2, J53.GND3, J53.GND4, J53.GND5, J53.GND6, J54.3, J54.5, J54.9, Q45.2, R201.1, R203.1, R208.1, R209.1, R210.1, R211.2, R213.1, R224.2, S25.3, S25.4, S27.3, S27.4, U41.2, U42.2, U43.A1, U43.A9, U43.B2, U43.B8, U43.E4, U43.E5, U43.F4, U43.F5, U43.K2, U43.K3, U43.K5, U43.K7, U43.K8, U43.L1, U43.L9, U43.M1, U43.M2, U43.M8, U43.M9, U44.1, U44.4, U44.6, U44.9, U45.2, U45.PAD, USBSHLD8.1
GND9: C109.2, C110.2, C111.2, C112.2, C113.2, C114.2, C115.2, C116.2, C117.2, C118.2, C119.2, C120.2, D57.C, D58.C, D59.2, D60.GND, J55.1, J56.1, J57.GND, J57.GND2, J58.25, J59.6, J59.GND1, J59.GND2, J59.GND3, J59.GND4, J59.GND5, J59.GND6, J60.3, J60.5, J60.9, Q50.2, R226.1, R228.1, R233.1, R234.1, R235.1, R236.2, R238.1, R249.2, S28.3, S28.4, S30.3, S30.4, U46.2, U47.2, U48.A1, U48.A9, U48.B2, U48.B8, U48.E4, U48.E5, U48.F4, U48.F5, U48.K2, U48.K3, U48.K5, U48.K7, U48.K8, U48.L1, U48.L9, U48.M1, U48.M2, U48.M8, U48.M9, U49.1, U49.4, U49.6, U49.9, U50.2, U50.PAD, USBSHLD9.1
GND10: C121.2, C122.2, C123.2, C124.2, C125.2, C126.2, C127.2, C128.2, C129.2, C130.2, C131.2, C132.2, D63.C, D64.C, D65.2, D66.GND, J61.1, J62.1, J63.GND, J63.GND2, J64.25, J65.6, J65.GND1, J65.GND2, J65.GND3, J65.GND4, J65.GND5, J65.GND6, J66.3, J66.5, J66.9, Q55.2, R251.1, R253.1, R258.1, R259.1, R260.1, R261.2, R263.1, R274.2, S31.3, S31.4, S33.3, S33.4, U51.2, U52.2, U53.A1, U53.A9, U53.B2, U53.B8, U53.E4, U53.E5, U53.F4, U53.F5, U53.K2, U53.K3, U53.K5, U53.K7, U53.K8, U53.L1, U53.L9, U53.M1, U53.M2, U53.M8, U53.M9, U54.1, U54.4, U54.6, U54.9, U55.2, U55.PAD, USBSHLD10.1
GND11: C133.2, C134.2, C135.2, C136.2, C137.2, C138.2, C139.2, C140.2, C141.2, C142.2, C143.2, C144.2, D69.C, D70.C, D71.2, D72.GND, J67.1, J68.1, J69.GND, J69.GND2, J70.25, J71.6, J71.GND1, J71.GND2, J71.GND3, J71.GND4, J71.GND5, J71.GND6, J72.3, J72.5, J72.9, Q60.2, R276.1, R278.1, R283.1, R284.1, R285.1, R286.2, R288.1, R299.2, S34.3, S34.4, S36.3, S36.4, U56.2, U57.2, U58.A1, U58.A9, U58.B2, U58.B8, U58.E4, U58.E5, U58.F4, U58.F5, U58.K2, U58.K3, U58.K5, U58.K7, U58.K8, U58.L1, U58.L9, U58.M1, U58.M2, U58.M8, U58.M9, U59.1, U59.4, U59.6, U59.9, U60.2, U60.PAD, USBSHLD11.1
unnamed: R1.2, U6.9
unnamed: D3.A, R4.2
unnamed: Q2.5, R17.2
unnamed: R5.1, R9.2, U6.8
unnamed: Q2.2, R18.2
unnamed: CHG.1, D1.C
unnamed: Q1.1, R10.2
unnamed: R15.2, S2.3, S2.4
unnamed: CUR.2, U4.5
unnamed: D5.DI, JP1.2
unnamed: CUR.1, R13.1
unnamed: LED.2, R2.1
unnamed: CUR.3, R6.2
unnamed: D4.A, R2.2
unnamed: D6.6, U6.3
unnamed: D6.1, J5.A6, J5.B6
unnamed: D1.A, R3.2
unnamed: D6.4, U6.4
unnamed: D6.3, J5.A7, J5.B7
unnamed: I2C.3, R28.2
unnamed: I2C.1, R29.2
unnamed: JP2.2, R4.1
unnamed: D2.C, MEAS.1, MEAS.3, Q1.2
unnamed: Q3.1, R14.2
unnamed: C5.1, J4.4, Q3.3, R16.1
unnamed: R14.1, R19.2, SDPC.2
unnamed: Q5.3, R20.2, R21.2
unnamed: C8.1, D5.VCC, JP3.2
unnamed: C2.1, C3.1, Q4.3, R1.1, U6.5, U6.6, U6.7
unnamed: Q4.1, R21.1
unnamed: Q5.1, R23.2
unnamed: R22.1, SDPC.3
unnamed: D8.A, R25.2
unnamed: R27.2, U10.9
unnamed: D9.A, R30.2
unnamed: R32.1, R33.2, U10.8
unnamed: CUR1.2, U2.5
unnamed: CUR1.1, R36.1
unnamed: CUR1.3, R26.2
unnamed: Q6.1, R37.2
unnamed: R38.2, S5.3, S5.4
unnamed: Q7.5, R39.2
unnamed: Q7.2, R40.2
unnamed: LED1.2, R41.1
unnamed: D10.A, R41.2
unnamed: D11.6, U10.3
unnamed: D11.1, J9.A6, J9.B6
unnamed: D11.4, U10.4
unnamed: D11.3, J9.A7, J9.B7
unnamed: CHG1.1, D8.C
unnamed: D12.DI, JP4.2
unnamed: I2C1.3, R42.2
unnamed: I2C1.1, R43.2
unnamed: JP5.2, R30.1
unnamed: D7.C, MEAS1.1, MEAS1.3, Q6.2
unnamed: Q8.1, R44.2
unnamed: C21.1, J11.4, Q8.3, R46.1
unnamed: R44.1, R45.2, SDPC1.2
unnamed: Q10.3, R47.2, R48.2
unnamed: C17.1, C18.1, Q9.3, R27.1, U10.5, U10.6, U10.7
unnamed: C22.1, D12.VCC, JP6.2
unnamed: Q9.1, R48.1
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

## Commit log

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2023-01-13 Proto Layout almost done
    -needs buzzard labels
    [SparkFun_Thing_Plus_NORA_W306.brd, SparkFun_Thing_Plus_NORA_W306.sch]
2023-01-16 Routed Log UART RX/TX to header pins
    [SparkFun_Thing_Plus_NORA_W306.brd, SparkFun_Thing_Plus_NORA_W306.sch]
2023-01-17 Bottom silk done, top silk needs placement
    [SparkFun_Thing_Plus_NORA_W306.brd, SparkFun_Thing_Plus_NORA_W306.sch]
2023-01-17 Switch to QFN28 package of CP2102
    -also finished top silk labels
    [SparkFun_Thing_Plus_NORA_W306.brd, SparkFun_Thing_Plus_NORA_W306.sch]
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2023-01-18 checklist run eng pre review
    -added jumper to disconnect RGB LED
    -added prod_id for module
    -added board thickness to ordering instructions on tdocu
    -added name/value texts to module footprint
    -moved a lot of vias and traces to avoid silk overlap
    [SparkFun_Thing_Plus_NORA_W306.brd, SparkFun_Thing_Plus_NORA_W306.sch]
2023-01-18 Switch IO controlling STAT LED from 13 to 16
    -to avoid having an LED on a strapping pin
    [SparkFun_Thing_Plus_NORA_W306.brd, SparkFun_Thing_Plus_NORA_W306.sch]
2023-01-18 added note about boot strap pins in schematic
    [SparkFun_Thing_Plus_NORA_W306.sch]
2023-01-18 arduino pin mapping table in schematic
    [SparkFun_Thing_Plus_NORA_W306.brd, SparkFun_Thing_Plus_NORA_W306.sch]
2023-01-19 nudged r11, fixed sch table
    -added silk outline to module footprint
    [SparkFun_Thing_Plus_NORA_W306.brd, SparkFun_Thing_Plus_NORA_W306.sch]
2023-01-19 nudged SDA trace for better btm gnd flow
    [SparkFun_Thing_Plus_NORA_W306.brd]
2023-01-19 module fp pad spacing corrected
    -all vector text in schematic
    -removed units in some measures
    [SparkFun_Thing_Plus_NORA_W306.brd, SparkFun_Thing_Plus_NORA_W306.sch]
2023-01-19 Design review changes
    -removed un-used net class "power"
    -renamed N_RESET net to !RESET!
    -added "USER" silk to button
    -flipped RESET buzzard label to match jumper label orientations
    -added chg jumper text paragraph to sch
    -nudged 3.3V vias/poly (connection from VREG to inner layer) to free up space from nearby passive.
    -added NC silk labels to NC header pins
    -all vias to 10 thou
    -added I2C pullups and jumper
    -added jumper to removed stat LED from GPIO
    [SparkFun_Thing_Plus_NORA_W306.brd, SparkFun_Thing_Plus_NORA_W306.sch]
2023-01-19 added debounce cap to reset
    [SparkFun_Thing_Plus_NORA_W306.brd, SparkFun_Thing_Plus_NORA_W306.sch]
2023-01-19 extended tb restricts outward .1mm to match ds
    [SparkFun_Thing_Plus_NORA_W306.brd, SparkFun_Thing_Plus_NORA_W306.sch]
2023-01-19 exteneded tb restrices out past module end like ds
    -this also highlighted that I should bring in the inner GND layer back as well, so did that too.
    [SparkFun_Thing_Plus_NORA_W306.brd, SparkFun_Thing_Plus_NORA_W306.sch]
2023-01-20 Renamed and updated label to STAT Jumper to JP4
    [SparkFun_Thing_Plus_NORA_W306.brd, SparkFun_Thing_Plus_NORA_W306.sch]
2023-01-30 Switched to SPI1 and alternate TX1/RX1 pins
    [SparkFun_Thing_Plus_NORA_W306.brd, SparkFun_Thing_Plus_NORA_W306.sch]
2023-01-30 bumping version to v02
    [SparkFun_Thing_Plus_NORA_W306.brd, SparkFun_Thing_Plus_NORA_W306.sch]
2023-01-30 BOM consolidation
    -added surface finish instructions (HASL)
    -removed layer 100
    -all 0.1uF caps are now the same 16V part (there used to be 3 different types).
    -all 10uF are now the same part (just changed one cap from 0603 to 0402, but had the same voltage rating).
    -all 4.7uF are now 0603, 35V, to accommodate VBATT inputs.
    [SparkFun_Thing_Plus_NORA_W306.brd, SparkFun_Thing_Plus_NORA_W306.sch]
2023-01-31 Added SWD header to bottom side
    [SparkFun_Thing_Plus_NORA_W306.brd, SparkFun_Thing_Plus_NORA_W306.sch]
2023-01-31 nudged trace for better gnd flow
    added gnd via near swd layer transfer
    [SparkFun_Thing_Plus_NORA_W306.brd]
2023-01-31 SWD header to DNP and bumped version to v03
    [SparkFun_Thing_Plus_NORA_W306.brd, SparkFun_Thing_Plus_NORA_W306.sch]
2023-02-01 v03 proto panel and gerbers
    [SparkFun_Thing_Plus_NORA_W306-Panel.GBL, SparkFun_Thing_Plus_NORA_W306-Panel.GBO, SparkFun_Thing_Plus_NORA_W306-Panel.GBP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]
2023-03-06 removed paste from cortex debug SMD footprint (DNP)
    -also bumped version to v04
    [SparkFun_Thing_Plus_NORA_W306.brd, SparkFun_Thing_Plus_NORA_W306.sch]
2023-03-10 Correcting SWD_DATA and SWD_CLK
    -In the Symbol Pin names, Removed SWD DATA and CL from PB18/PB19
    -Removed PDM mic
    [SparkFun_Thing_Plus_NORA_W306.brd, SparkFun_Thing_Plus_NORA_W306.sch]
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2023-03-13 Switched CP2102 to QFN24 package type
    [SparkFun_Thing_Plus_NORA_W306.brd, SparkFun_Thing_Plus_NORA_W306.sch]
2023-03-20 Rerouted with new pin selections
    -SPI0 now used for "main" SPI headers and uSD
    -SPI1 PICO pin used for WS2812 control
    -RX1/TX1 pins changed to other option on module
    -I2C pins changed to other option on module
    -SWD lines routed to DNP header on bottom side.
    -most GPIOs switched/rerouted *note, Arduino pin map table not yet updated*
    [SparkFun_Thing_Plus_NORA_W306.brd, SparkFun_Thing_Plus_NORA_W306.sch]
2023-03-20 Silk Labels updated
    -and some minor layout tweaks
    [SparkFun_Thing_Plus_NORA_W306.brd, SparkFun_Thing_Plus_NORA_W306.sch]
2023-03-21 Corrected User button and STAT LED silk
    -Moved button to Arduino "17"
    [SparkFun_Thing_Plus_NORA_W306.brd, SparkFun_Thing_Plus_NORA_W306.sch]
2023-03-21 rerouting some stuff
    -Re-routed SPI lined to removed one via in SPI0_CLK net
    -Nudged some stuff to create a bit more clearance between RX/TX log and SPI traces on long north-south journey.
    [SparkFun_Thing_Plus_NORA_W306.brd]
2023-03-22 Updated Arduino pin mapping table in SCH
    [SparkFun_Thing_Plus_NORA_W306.brd, SparkFun_Thing_Plus_NORA_W306.sch]
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2023-03-22 Moved SDA/SCL from inner to bottom layer
    [SparkFun_Thing_Plus_NORA_W306.brd]
2023-03-22 Removed V_BUS plane on inner layer
    To avoid splitting up the 3.3V plane on the inner layer, I decided to route V_USB (instead of using an additional separate plane).
    Added some stitching traces/polys to stich up the 3.3V plane.
    [SparkFun_Thing_Plus_NORA_W306.brd]
2023-03-23 Updated to new 0603 RED LED
    -also updated the limiting resistor to correct value (4.7K) for DIO-17976
    [SparkFun_Thing_Plus_NORA_W306.brd, SparkFun_Thing_Plus_NORA_W306.sch]
2023-03-24 Pre-group Review of v04 Changes
    -moved logos to right box in SCH
    -added column names to may pin mapping table in SCH
    -adjusted SCH note about boot strapping pin internal pullups
    -"single-cell" lipo batt note moved to single line
    -changed current jumper silk to be "CUR"
    -changed MEAS to smaller size and flat ends to fit better
    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
    [SparkFun_Thing_Plus_NORA_W306.brd, SparkFun_Thing_Plus_NORA_W306.sch]
2023-03-24 more tweaks pre-review
    -added another ground via near I2C lines NW corner
    -Added GND trace to connect GND near user button
    -fixed some airwires caused by the new trestrict rectangles. Just routed the "missing" GND connections.
    [SparkFun_Thing_Plus_NORA_W306.brd]
2023-03-24 Added tKeepout around module footprint
    [SparkFun_Thing_Plus_NORA_W306.brd, SparkFun_Thing_Plus_NORA_W306.sch]
2023-03-24 Label Abbreviations table in SCH
    [SparkFun_Thing_Plus_NORA_W306.sch]
2023-03-28 WIP adding switches to uSD and CP2102
    [SparkFun_Thing_Plus_NORA_W306.brd, SparkFun_Thing_Plus_NORA_W306.sch]
2023-03-29 layout work done for switches for uSD & cp2102
    [SparkFun_Thing_Plus_NORA_W306.brd, SparkFun_Thing_Plus_NORA_W306.sch]
2023-03-29 added jumper to cut power to WS2812B
    [SparkFun_Thing_Plus_NORA_W306.brd, SparkFun_Thing_Plus_NORA_W306.sch]
2023-03-29 corrected JP1 comment text
    [SparkFun_Thing_Plus_NORA_W306.sch]
2023-03-29 replaced SDPC jumper using correct library
    [SparkFun_Thing_Plus_NORA_W306.brd, SparkFun_Thing_Plus_NORA_W306.sch]
2023-03-29 updating visible layers when you open it
    [SparkFun_Thing_Plus_NORA_W306.brd]
2023-03-29 final review before ordering proto changes
    -added 100 ohm slow down resistor to CP2102 mosfet control gate pin
    -added 1K pull down off of SCPC jumper to protect gpio in case user accidentally closes all 3 pads on jumper.
    -changed VBATT trace on inner layer so it crosses SDA/SCL at 90
    -added gnd via above user botton
    -added full size SFE logo to bottom silk
    -center product name silk
    -redrew bRestrict as rectangles in module FP
    -made all sch labels vector
    -changed "No connect" to "Not connected" in abbreviation table
    -Add note - if user cuts JP3, they should cut JP1 too to prevent back powering
    -Add warning - if SDPC is enabled, user needs to not drive pins high until uSD is powered
    -changed C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
    [SparkFun_Thing_Plus_NORA_W306.brd, SparkFun_Thing_Plus_NORA_W306.sch]
2023-03-29 added gate resistor to Q5
    [SparkFun_Thing_Plus_NORA_W306.brd, SparkFun_Thing_Plus_NORA_W306.sch]
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2023-04-04 Via size decreased to reach 5 mil clearances
    -decreased via size to provide more clearance from pads under the module
    -also decrease GND traces under the module to 16 mil.
    -also adjusted USB D+/D- for closer to 90 ohms impeadance (8mil trace width and 6mil gap between them).
    -bumped version to v05 to keep file names straight with collaborators on this project
    [SparkFun_Thing_Plus_NORA_W306.brd, SparkFun_Thing_Plus_NORA_W306.sch]
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2023-05-15 Tweaks from final mini group review.
    -corrected "back powering" to "powering" on sch note about JP1
    -Swapped R7 from 10K to 100K for better power savings if powered from USB or 5V battery
    -nudging for better GND flow
    -peppered in some more gnd vias
    -adjusted v_batt trace and via from header to fuel gage for better gnd flow
    -adjusted SWD Traces for a little more spacing in between them
    -added GND via at one layer change on SWD_DATA trace.
    -switched silk to include "IO" on gpio pins (button, RGB, STAT)
    -switched CUR and SDPC jumper labels to inverted text style.
    -nudges bottom silk label "VB" away for better printing.
    [SparkFun_Thing_Plus_NORA_W306.brd, SparkFun_Thing_Plus_NORA_W306.sch]
2023-05-15 one more via
    -one more via in between pads 14 and 15. Had a long ground peninsula with no gnd at the end.
    -nudged PB1 trace away a tiny bit to allow ground flow.
    [SparkFun_Thing_Plus_NORA_W306.brd]
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

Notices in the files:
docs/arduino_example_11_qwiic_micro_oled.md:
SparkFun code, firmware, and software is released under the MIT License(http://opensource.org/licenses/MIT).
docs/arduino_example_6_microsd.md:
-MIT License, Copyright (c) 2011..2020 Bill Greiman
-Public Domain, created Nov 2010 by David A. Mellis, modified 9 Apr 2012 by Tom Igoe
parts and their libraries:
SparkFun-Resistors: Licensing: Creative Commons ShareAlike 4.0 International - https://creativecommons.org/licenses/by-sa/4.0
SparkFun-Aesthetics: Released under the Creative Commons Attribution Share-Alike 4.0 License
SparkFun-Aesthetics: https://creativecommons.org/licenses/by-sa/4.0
